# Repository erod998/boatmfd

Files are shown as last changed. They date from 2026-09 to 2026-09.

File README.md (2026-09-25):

# Boat Dashboard — Proof of Concept

A DIY Garmin-style MFD for a 7" 16:9 landscape display, restyled after the
look of Garmin's GPSMAP touchscreen chartplotters (near-black panes, round
segmented dials that fill blue, outlined data boxes, a black menu bar with a
Home button) and built for big touch targets while driving the boat.

**Moving to real hardware?** [HARDWARE.md](HARDWARE.md) has the parts list, a picked depth
transducer, and a step-by-step order to bring it up on the boat.

**Screens** (tap **Home** on the menu bar, or the small thumbnails either side
of it, to switch):

| Screen | What it shows |
| --- | --- |
| **Helm** (default) | Everything at once: GPS speed and RPM dials plus coolant / oil / battery / fuel (with estimated GPH and MPG) / trim bars on top, the chart with big Depth and Water Temp boxes in the middle, and trip, Fusion stereo and RGB lights below |
| **Nav. Chart** | Full-screen chart with Speed / Heading / Depth / Water Temp data boxes, zoom buttons, the boat, its heading line and track, an optional compass rose, and waypoint navigation |
| **Gauges** | Garmin-style engine and vessel dials: coolant, oil, battery, fuel, trim, RPM, GPS speed, fuel flow, plus fuel economy / remaining / water temp boxes |
| **Trip** | Start/stop trip logging: distance, time, average and max speed, fuel used and economy, and the saved-trip list |
| **Media** | Fusion stereo over NMEA 2000: cover art, source chips, big transport buttons, a Master volume that moves every zone together (keeping their relative mix), and a volume bar for each zone (with its own mute), plus a mute for everything, plus a gear icon for RPM Volume Boost |
| **RGB Lights** | Twelve colour presets, rainbow, power, and a segmented brightness bar |
| **Switching** | A grid of simulated digital-switching circuits (nav lights, anchor light, cabin lights, livewell, bilge pump, two accessories, horn) — no real switching module, just remembers on/off |

**Also reachable from Options** (not full screens, but full features): **Waypoints, Routes &
Boundaries** (mark/save/rename/delete waypoints, search saved waypoints by name and go straight
to one — like a GPS — build and follow multi-leg routes, circular geofence alarms), **Navigation
Alarms** (Arrival, Off Course, Anchor Drag, GPS Accuracy), and **Pinned Screens** (choose which screens
show in the Home overlay's Pinned tab and the prev/next swipe at the bottom of every screen — at
least one has to stay pinned).

**Home** is a translucent overlay like Garmin's: a clock (tap **Home** any time to check
it), a row of screen thumbnails above category tabs (Pinned, Charts, Combo, Vessel, Media,
Lights). The menu bar also has **Mark** (drop a waypoint at the boat), **Info** (data sources,
position, GPS status), **Day/Night** chart mode, **Alerts** (the alarms and
warnings below, and a missing GPS fix; the icon turns amber/red with a count)
and **Options** (units, alarms, chart orientation, map layers & colors, centre chart on
boat, waypoints, calibration). Tap the speed gauge to switch between mph and knots. The
chart defaults to **Old Hickory Lake, TN (37075)**, and has the three orientations a GPSMAP
does: **North Up** (default), **Heading Up** (the bow points to the top of the screen) and
**Course Up** (the *active leg* points to the top). Course Up is the one worth knowing about —
Heading Up re-aims the chart with every wiggle of the boat, which at idle is a constant slow
swim, while Course Up holds the leg still and lets the boat icon swing against it, so the angle
between the icon and straight-up is exactly how much you are crabbing off the track. With no Go
To or route running it falls back to course over ground, then heading, so it is never stuck
pointing somewhere stale. The chart button beside the zoom controls is labelled with the current
mode (**N↑**, **H↑**, **C↑**) and switches in one press between North Up and whichever rotating
mode you last chose; **Options → Chart orientation** cycles through all three. (It used to cycle
all three itself, and since Heading Up and Course Up look alike on a straight run, getting back
to North Up took two presses.)

**Following the boat**: the chart keeps the boat centred (North Up) or a third of the way up the
screen (Heading and Course Up) until you drag it. Then it stays where you put it, and a blue
**Center** button appears above the ruler; tap it to go back to the boat. Pinching or the +/−
buttons zoom without letting go of the boat.

**The chart cursor** — what a tap on the chart does, the way a GPSMAP does it: it drops a cursor
and does nothing else yet. The bar that appears says how far away it is and in which direction,
its position, and what is charted there (the depth band, or a bridge, dam or caution area — tap
that line for the full details); **Go To** navigates there, **Save Waypoint** keeps it. A tap used
to start a Go To immediately, and since a Go To and a route are mutually exclusive, one stray tap
in a chop cancelled an active route. Tapping an aid to navigation, mile marker, landmark or
hazard point identifies it instead, with its own Go To. Only those point features take a tap;
land, depth areas and shorelines used to as well, which between them cover the whole chart, so
every tap opened "Land" and the chart could not be tapped for anything else at all.

**Go To follows the channel** (auto guidance): a Go To is planned over the water, preferring the
Corps' recommended track down the channel, and leaves it only to reach a destination off it -- up a
creek, into a marina. The route is drawn as a dashed line and steered leg by leg: bearing, course
and cross-track error are for the current leg (so Course Up turns with the channel), distance and
time to go are along the rest of the route. With no chart or no way through the water it falls
back to a straight line and says so. Saved routes (Route To) still run straight between their
waypoints, as they do on a GPSMAP.

**Look-ahead**: in North Up the boat sits a third of the way in from the edge it is coming from,
so two thirds of the screen is the water ahead -- the bottom third heading north, the left third
heading east. It follows the course over the ground above 2 kn.

**Measure Distance** (the ruler button beside the zoom controls): the reference starts at the
boat and follows it; each tap on the chart moves the far end, and the range and bearing read out
at the top of the chart. **Set Ref** pins the reference to that point instead, to measure between
two arbitrary points; **From Boat** puts it back. (Built for a finger: an earlier version relied on
mouse hover and read 0.00 on a touchscreen.)

**Range Rings** (**Options → Map layers & colors → My Vessel**): four concentric circles around
the boat at a spacing you pick, the outermost labelled with its radius, so distance to anything
on screen can be eyeballed without measuring it. Drawn in real distance rather than screen
pixels, so they scale with zoom the way the chart does.

The boat's position and heading are eased continuously (every animation frame, not once a
second when a GPS fix arrives) — the same idea as the spring-smoothed gauges, but for a
wrapped compass angle and a lat/lon position: `setBoatTarget()`/`boatTick()` in app.js. This
drives the boat icon, the chart's own bearing in Heading Up (which turns the whole chart so
the boat's current heading points to the top of the screen, the boat icon then always
pointing straight up), and the position lock that keeps the boat horizontally centered and
about a third of the way up from the bottom of the map in Heading Up — a single cheap
`panBy` every frame, not a `setView`, so it holds through the whole rotation instead of only
correcting once a second. The chart itself is vector data held in memory (see **Charts**), so
panning and rotating never wait on anything to load and never show a blank square — the old
raster-tile black-square problem went away with the tiles.

**Map layers & colors** (**Options → Map layers & colors**, or the app/gps.py and
app/state.py simulators' more realistic noise): chart colors are Day/Dusk/Night — three real
palettes applied to the chart vectors themselves, not a filter smeared over an image, so the
boat and track keep their own colours while only the chart changes;
**Chart** layer toggles (Land & shoreline, Depths & contours, Aids to navigation, Hazards &
caution areas, Landmarks) add and remove the matching vector layers on the spot, with no
refetching — the data is already local; **My Vessel** has a Heading Line
(projects ahead of the boat by a fixed distance or by how far it'll travel in a set time at
its current speed — Distance/Time, matching a real GPSMAP's own Heading Line options) and a
Compass Rose (a fixed-size ring around the boat marked N/E/S/W — left un-rotated in CSS on
purpose, since leaflet-rotate spins the whole marker pane with the chart, the same reason the
boat icon has to counter-rotate to stay pointing up in Heading Up); **User Data** can hide the
recorded track, clear it, name and **save** the current breadcrumb trail as a permanent record
(kept in `data/tracks.json`, up to the same ~600-point/~10-minute window the live trail itself
keeps — a real chartplotter's active-track memory has the same kind of limit), and lists every
saved track — tap one to draw it on the chart in green, tap again to hide it, tap the pencil to
rename it in place, tap the arrow to drop a waypoint back at its starting point (retracing it, the
way you'd want to find your way back to the dock after an out-and-back cruise), or delete it. All
of this is a per-browser preference (localStorage) except clearing the track, and saved tracks
themselves, which live on the server (`/api/track`, `/api/tracks`).

**Data overlays** (the Speed/Heading/Depth/... boxes on the Helm and Nav. Chart screens): **hold**
any box (same gesture, and the same fill-as-you-hold feedback, as the RPM display and alarm
menus) to swap in a different field, matching a real GPSMAP's "Edit Overlays". There are **36
fields in seven groups**, and the picker shows the group headings because a flat list of that
many is not something anyone navigates while driving:

| Group | Fields |
| --- | --- |
| **Navigation** | Bearing, Course, Distance, Time To Dest, Arrival Time, VMG, Cross Track, Turn, Destination |
| **Vessel** | Speed, Heading, Course Over Ground, Position, GPS Accuracy, Satellites |
| **Depth & Water** | Depth, Water Temp |
| **Engine** | RPM, Engine Temp, Oil Pressure, Trim, Battery |
| **Fuel** | Fuel Level, Fuel Remaining, Fuel Rate, Fuel Economy, Range |
| **Trip** | Trip Distance, Trip Time, Average Speed, Max Speed, Trip Fuel Used |
| **Time** | Time of Day, Sunrise, Sunset, Moon Phase |

The Navigation group needs a Go To or a route running and reads `--` otherwise, the Trip group
needs a trip started, and everything reads `--` without a GPS fix — which is what a real unit
does rather than showing a stale or invented number. **VMG** is velocity made good: how fast the
distance to the destination is actually shrinking, which is only the same as speed when steering
straight at it. **Time To Dest** is computed from VMG rather than speed for exactly that reason
— sliding sideways past a waypoint at 20 kn is not arriving at 20 kn — and reads `--` when VMG
has gone negative, because a boat pointed away is not arriving at all. **Fuel Remaining**,
**Economy** and **Range** need the tank size (`BOAT_FUEL_CAPACITY_GAL`, default 40).
Which fields are picked, per screen, is a per-browser preference (localStorage);
the Chart screen defaults to Speed/Heading/Depth/Water Temp and the Helm screen (which already
shows speed via its own dial) to Depth/Water Temp, same as before this was made editable.
Sunrise, sunset and moon phase come from `app/celestial.py` — sunrise/sunset from the standard
astronomical "sunrise equation" using the boat's own position, moon phase from the days elapsed
since a known new moon (the same for every observer, so it only needs a date) — both accurate to
civil (not celestial-navigation) precision, no network call or API key, and (deliberately) not
tide/current predictions or moonrise/moonset times, which either wouldn't mean anything on a
freshwater lake (tide/current) or need meaningfully more work to compute well (the moon's real
position, not just its phase angle) than this dashboard's use case calls for.

**Alarms:** hold your finger on a gauge for about half a second (the gauge
fills as you hold) to open its alarm menu: coolant / engine temperature, oil
pressure, battery voltage (a low and a high alarm), fuel level, or the Depth
box. **Options → Alarms** lists them all. Each has an on/off switch and a
level you set with the big −/+ buttons or by tapping the bar; a small bell
marks every gauge that has an alarm on, and the gauge's red and amber bands
move to match the level. Coolant and engine temperature are the same reading
here (one engine-temperature gauge). Details are in "Alarms" below.

**Waypoints, Routes & Boundaries** (**Options → Waypoints, Routes & Boundaries**): mark the
boat's current position as a named, saved waypoint (separate from the single "Go To" target the
chart cursor sets); go to one, rename it in place, or delete it. Build a **route** by
checking two or more saved waypoints in the order you want to visit them — following one steers
leg to leg and auto-advances to the next point on arrival (within ~300 ft), the same way a single
Go To does, and the two are mutually exclusive (starting a route stops a Go To and vice versa).
**Boundaries** are a circular geofence around a point — pick a radius and whether the alarm fires
on entering, exiting, or both — for a no-wake zone, a marina, water you want a heads-up about
either way. Only circles, not the arbitrary polygons a real Garmin supports: a circle is a tap
and a radius, a polygon needs collecting an ordered ring of points on a touchscreen, and circles
already cover "stay near/away from this spot."

**Navigation Alarms** (**Options → Navigation Alarms**): **Arrival** (nearing the active
waypoint or route leg, on by default), **Off Course** (strayed too far from the direct line, by
cross-track error), **GPS Accuracy** (the fix's own reported HDOP has gotten too poor to trust),
and **Anchor Drag** — drop a reference point at the current position and get alarmed if the boat
drifts past a set radius from it, checked against the real (or simulated) GPS fix every second,
the same way a real chartplotter's anchor watch works. All four, plus boundary crossings, show up
in the same Alerts panel and banner as the engine/boat alarms; unlike those, they don't have an
"acknowledge" — they clear on their own once the condition does (back on course, anchor
re-settled), except a boundary crossing, which is a one-time event held in the alert list for 8
seconds so it doesn't disappear before the once-a-second Alerts badge or banner even shows it.

**Digital Switching** (the **Switching** screen): eight named on/off circuits (nav lights, anchor
light, cabin lights, livewell, bilge pump, two accessories, horn) standing in for a real NMEA
2000 digital-switching module (a CZone/Empirbus-style relay box) — there isn't one wired up, so
each circuit just remembers its own state, the same simulate-what-there's-no-hardware-for
approach as the rest of this dashboard.

**Smooth gauges:** engine and boat readings arrive five times a second (GPS,
trip, stereo and lights once a second), and every dial, bar and number glides
to each new reading on a critically damped spring instead of jumping, so
needles start and stop gently and never overshoot. How quickly a needle
follows a new reading is itself adjustable: hold either RPM gauge (Helm or
Gauges screen) to open "Engine RPM display" and pick from Very smooth to
Snappy — useful once a real, noisier tach signal replaces the simulator's.
No amount of easing can fully hide noise with a genuinely slow, drifting
component (a spring only trades lag for smoothness, it can't remove a real
random walk), so the simulated RPM and GPS heading in app/state.py and
app/gps.py were also tuned down to something closer to a real steady-cruise
signal — they were originally noisy enough that even "Very smooth" still
visibly shook.

Engine and battery readings are read-only, like real NMEA 2000 sensors. The
layout scales with screen height and was checked at 800x480, 1024x600,
1280x720, 1280x800 (the 10.1" panel below) and 1920x1080.

Runs today against built-in **simulators** (GPS, engine, stereo, LEDs) so the
whole thing is demoable with zero hardware attached. Swapping in real
hardware is a config change, not a rewrite — see "Going to real hardware".

## The reference build

| Job | Part | Connects with |
| --- | --- | --- |
| Brain | Raspberry Pi 4 or 5 | Runs the server and the browser (Chromium kiosk) |
| Screen | Orient Display 10.1" 1280x800, 900 nit, capacitive touch, **HDMI/USB version** (see "The screen") | HDMI + USB touch + 12 V |
| Engine data | Matsutec **CX5003** analog-to-NMEA 2000 converter | senders on one side, NMEA 2000 on the other |
| Stereo | Fusion MS-RA210 / MS-WB675 | NMEA 2000 |
| NMEA 2000 interface | CAN HAT for the Pi (PiCAN-M, MacArthur HAT, or an isolated MCP2515 HAT) or a USB CAN adapter | `can0`, 250 kbit/s |
| Fuel flow (optional) | NMEA 2000 fuel-flow sensor | NMEA 2000 |
| Lights | 12 V PWM RGB strips: PCA9685 board + 3 logic-level MOSFETs | I2C |
| Position | GPS receiver | USB or UART |
| Battery voltage | ADS1115 board + two resistors (or the converter's alternator volts) | I2C |

```
 senders (tach, oil, temp, trim, fuel) --> CX5003 --+
 Fusion MS-RA210 / MS-WB675 ------------------------+--- NMEA 2000 backbone (250 kbit/s, a terminator
 fuel-flow sensor (optional) -----------------------+    at each end, 12 V power tee)
                                                    |
                                     CAN HAT or USB CAN adapter
                                                    |
 GPS -------------- USB or UART ---------------+    |
 battery ------- ADS1115 ---- I2C -------------+--- Raspberry Pi --- HDMI + USB touch ---> 10.1" screen
 12 V RGB strips <-- MOSFETs <-- PCA9685 <-- I2C +
```

**ESP32** is not a fit for serving the chart UI, but it makes an excellent
*lighting node* for addressable strips:
[`esp32/boat_rgb_node/`](esp32/boat_rgb_node/boat_rgb_node.ino) is an
Arduino sketch that drives a WS2812B strip over WiFi with the same
`/api/lighting` shape this dashboard uses (solid color + rainbow).

## Run it (simulator mode, no hardware)

```bash
python -m venv venv
venv/Scripts/pip install -r requirements.txt      # Windows
# venv/bin/pip install -r requirements.txt         # macOS/Linux
venv/Scripts/python -m uvicorn app.main:app --host 0.0.0.0 --port 8090
```

Open `http://localhost:8090` (the layout scales with screen height, so it
works from 1024x600 up to 1080p). The simulated boat cruises up and down
the Old Hickory Lake channel near Hendersonville (edit `ROUTE` in
[`app/gps.py`](app/gps.py) to move it). Tap the chart to drop the cursor, press **Go To**, and
watch bearing/distance/ETA/cross-track-error update live (**Options →
Waypoint / go to…** shows them). Use **Night** on the menu bar, tap a color
swatch to light the (virtual) LED strip, and try the Media screen (a simulated
stereo, badge says DEMO). On a desktop browser the screen is sized by window
height, so resize to 1024x600 to see it as it will look on the boat.

Tests (protocol layer, including a fake stereo on a virtual CAN bus):

```bash
venv/Scripts/pip install python-can
venv/Scripts/python -m unittest discover -s tests -t . -v
```

## Charts

The chart is **vector data drawn by this app**, not pictures downloaded from a
map server — the same thing a real chartplotter does, and the reason it works
with no internet, stays sharp at any zoom, restyles for night instantly, and
can tell you what a buoy is when you tap it.

Source is **USACE Inland ENC** (`ienccloud.us`, the Corps of Engineers' inland
waterway charts — free, no key, no account). Their map service exposes every
S-57 feature class as a queryable layer, so the fetch pulls real GeoJSON:
depth areas with their actual depth ranges in metres, the shoreline, the
navigable channel, and every buoy, beacon and light with full attribution.

For the whole of Old Hickory Lake — Old Hickory Dam (river mile 216) up to Cordell Hull Dam at
Carthage (mile 313), creek arms included — that is **about 9,000 features and 8 MB, in about 107
requests, one every 3 seconds: 6–7 minutes**, once, until you choose to refresh it. (The first
version covered only the lower lake and stopped at Gallatin.) The service publishes no rate
limit and is a shared government server, so the fetcher never bursts; see
`REQUEST_DELAY_S` in `app/chart_data.py`.

### Getting the charts

Run this **on the Pi**, over WiFi at the dock:

```bash
venv/bin/python -m app.fetch_charts old-hickory --dry-run   # coverage check first
venv/bin/python -m app.fetch_charts old-hickory              # then for real
venv/bin/python -m app.fetch_charts --name my-lake --bbox -86.62,36.24,-86.44,36.36
```

Charts land in `data/charts/<area>/` as GeoJSON, two levels of detail (the
zoomed-out one is generalised server-side, which turns 2.1 MB of raw shoreline
into 207 KB without any visible difference at that zoom).

**`data/charts/` is committed**, so Old Hickory arrives with a plain `git pull`
and you only need the command above for a new area or a refresh. Everything else
under `data/` — tracks, waypoints, trips, settings — stays gitignored, since
that is per-boat state rather than project source. Charts are the exception
because the Pi cannot re-create them for itself: it is offline, and
`fetch_charts.py` needs the internet.

USACE reissues IENCs bi-monthly, so re-running this occasionally at the dock is
worth doing. It simply overwrites what's there.

### What you get on screen

Land and shoreline; creeks and marina basins as water; depth-shaded water, with the
**surveyed depths** (below) over the channel; the recommended track; bridges, the dam and lock;
marinas, docks and piers; restricted areas and no-wake notice signs; caution areas and hazards;
roads and railroads on land; and the aids to navigation on top. **Names** print the way a chart
prints them — creeks and bays in italic blue, islands and bends, towns, marinas, bridges and river
miles — upright even in Heading Up, and only as many as fit without overlapping. Detail comes in
as you zoom: the whole lake at once is the shoreline, the channel and the town names, and buoys,
mile markers, hazards and docks appear as you zoom in. Every group can be hidden under
**Options → Map layers & colors**. Tap any of them:

| Tap | It says |
| --- | --- |
| A beacon | `Spencer Creek Light (236.8)` — Starboard-Hand Lateral Mark, Red |
| A light | `Fl(2)R 5s` — built from the S-57 characteristic, group and period |
| The chart, in the surveyed channel | `Depth 18.2 ft, surveyed 2019` — then the charted area below it |
| A charted depth area | `0 ft to 9 ft` outside the channel, `9 ft or more` inside it |
| A marina | its name, and what kind of facility it is |
| A distance mark | `Mile 225`, Cumberland (CR) |

Two things were wrong in how the chart drew before this version and are worth knowing about if
you remember the old one: creeks and marina basins were filled in the **land** colour (Station
Camp Creek, Cedar Creek and every marina looked like dry ground), and in **Heading Up the chart
did not turn** — the boat, track and labels did, while the chart under them stayed north-up and
drew in the wrong place.

### Surveyed depths

The Corps' chart only knows two depths on Old Hickory: **0–9 ft** outside the navigation channel
and **9 ft or more** inside it. That is what the chart is for — the maintained 9-ft channel — and
it is why tapping the chart used to say 0–9 ft or nothing.

The Corps does survey the actual bottom. Its Nashville District runs condition surveys of the
channel and publishes every one through **eHydro** — around 9,000 soundings per mile, across the
old river bed from bank to bank. `app/fetch_depths.py` downloads them and turns them into a depth
grid (25 ft cells, keeping the shallowest sounding in each, a newer survey replacing an older
one) plus the surveyors' own printed soundings:

```bash
venv/bin/python -m app.fetch_depths old-hickory --dry-run   # list the surveys
venv/bin/python -m app.fetch_depths old-hickory              # ~18 downloads, one every 5 s
```

On screen: the channel shaded by depth (darker is shallower, as on a paper chart; the colour key
is under Map layers & colors), depth numbers once zoomed in, and the cursor reading the real
depth wherever you tap in a surveyed stretch. The result is `data/charts/old-hickory/survey_depth.json`
(680 KB, committed with the charts); the downloads are cached in `data/survey-cache/` so a re-run
fetches only new surveys.

**What it covers**: river miles **216–225** (Old Hickory Dam up past Hermitage, surveyed 2018–19)
and **297–313** (the upper lake below Cordell Hull Dam, 2016–17) — the channel, not the coves,
flats or creek arms, and not the middle of the lake between those two stretches. No public data
covers those; Quickdraw, once a transducer is fitted, fills them in from your own sounder.

**Lake level**: the surveys record bottom *elevations* (feet above NAVD88), so a depth is the lake
level minus the bottom — and Old Hickory moves between 442 and 445 ft. **Options → Map layers &
colors → Lake level** sets it (445 ft, normal summer pool, by default), the way a Garmin with
lake charts does; every screen shares the setting. Set it to the day's level, which the Corps
posts daily, and the chart agrees with the sounder.

Day / Dusk / Night are real palettes applied to the vectors, not a CSS filter
smeared over an image — so the boat and track keep their own
colours while only the chart changes.

### Coverage: what this data does and does not include

IENC charts the **commercially-navigable federal waterway system** — the
Cumberland (including Old Hickory Lake), Tennessee, Ohio, Mississippi and
similar. Those are covered properly, to real chart standard.

Lakes off that system may have **nothing at all**. Center Hill Lake was checked
three ways — the IENC vector service, the IENC S-57 cell list, and USACE's
separate eHydro hydrographic survey archive — and has zero USACE data in any of
them. That is a genuine gap in the free federal data, not a bug here.
`--dry-run` reports the feature count before downloading, so an uncovered area
is obvious in seconds.

Closing that gap means commercial data (Navionics, C-MAP and the like, which is
what apps such as Savvy Navvy license). That data is not redistributable into a
project like this one without its own licence, and the terms are not something
to assume — it would need checking with the provider directly, and would be a
separate data pipeline rather than a drop-in. The other route, once a
transducer is fitted, is recording your own depths with Quickdraw, which builds
a personal depth map of exactly the water you actually run.

### Why it is not raster tiles any more

The first version cached rendered tile images. Replacing it with vectors was
not a tuning change, it was a correction:

| | Raster tiles | Vectors (now) |
| --- | --- | --- |
| Requests for one lake | ~4,500, rate-limited | **~60, once** |
| Time | ~3.75 hours | **36 seconds** |
| On disk | 88 MB | **2.1 MB** |
| Zoom | fixed 11–15, blurry between | **any zoom, always sharp** |
| Night mode | CSS filter over the image | **a real palette** |
| Tap a feature | nothing | **full chart attributes** |
| Load with no internet | only pre-cached area | **everything fetched** |

### A chart app of its own in the chart's place (GPS Nautical Charts)

GPS Nautical Charts sells Center Hill Lake charts, but only inside their own app, not
as files the dashboard can draw. Their Raspberry Pi app (`Boating_App-aarch64.AppImage`,
a Qt/X11 program, verified by them on Debian 13) can take the chart's place on the
helm display instead. The dashboard's screens stay as they are, and the app's window
sits where the chart would be: on the Helm and Chart screens, clear of the data boxes,
an open side panel and the alarm banner, and out of sight on the other screens and
under the Home overlay.

On the Pi (the custom image):

```bash
mkdir -p ~/boating-app && cd ~/boating-app
curl -fLO https://www.gpsnauticalcharts.com/static_html/Boating_App-aarch64.AppImage
chmod +x Boating_App-aarch64.AppImage && ./Boating_App-aarch64.AppImage --appimage-extract
echo "BOAT_CHART_APP=$HOME/boating-app/squashfs-root/AppRun" >> /var/lib/boatmfd/boat.env
sudo systemctl restart boat-dashboard boatmfd-kiosk
```

(Extracted rather than run as an AppImage: the image has no FUSE, and it starts faster.)
Then, in the app's settings, set its NMEA 0183 source to **TCP, 127.0.0.1, port
10110**: the dashboard sends the boat's position, speed, course, heading, depth and
water temperature there once a second (`app/nmea_out.py`; `BOAT_NMEA_TCP_PORT` and
`BOAT_NMEA_TCP_HOST` change where).

How it fits together: the kiosk page (`static/js/chart-app.js`) reports where its
chart is on the screen (`POST /api/chart-app/rect`); `kiosk/chart-app.py`, started by
labwc's autostart when `BOAT_CHART_APP` is set, keeps the app running and moves its
window there; labwc's window rule (`/etc/boatmfd/labwc/rc.xml`) takes its title bar
off and keeps it above the dashboard. Remove the `BOAT_CHART_APP` line to go back to
the dashboard's own chart.

## Going to real hardware

**GPS** (e.g. u-blox NEO-6M/NEO-M8N on the Pi's UART or a USB adapter):

```bash
venv/Scripts/pip install pyserial pynmea2
set BOAT_GPS_PORT=COM5          # or /dev/serial0 on the Pi
set BOAT_GPS_BAUD=9600
```

With `BOAT_GPS_PORT` set, [`app/gps.py`](app/gps.py) uses `SerialGPS`
(real NMEA GGA/RMC/VTG parsing) instead of the simulator. If the port can't
be opened it shows NO FIX rather than a made-up position. Put the antenna
where it sees the sky.

**When hardware is configured, the dashboard never shows made-up numbers:**
a sensor that isn't wired, or has failed, shows `--`. Depth is `--` until you
add a depth transducer, and water temperature is `--` until you assign a
water probe.

### The screen

The listing for the [10.1" Sunlight Readable IPS, 1280x800, 900 nits, capacitive touch panel](https://orientdisplay.com/products/10-1-sunlight-readable-ips-1280x800-900-nits-with-capacitive-touch-panel/)
(`AFY1280800A1-10.1INTH-C`, about $142) is a **bare LVDS panel**: it has no
HDMI input, its touch panel needs its own controller, and its 3.3 V logic and
LED backlight expect a driver board. A Raspberry Pi can't drive it directly.
Orient sells the same panel with the driver board attached as the
[10.1" Raspberry Pi TFT with PCAP, HDMI/USB interface](https://www.orientdisplay.com/products/10-1-raspberry-pi-tft-with-pcap1280x800-900-nits-hdmi-usb-interface/)
(`AFY1280800A2-10.1INTH-C-HDMI`, about $180, listed with HDMI video, USB touch and a
12 V supply). Buy that one. Keeping the bare panel would mean sourcing an
HDMI-to-LVDS board that matches its pinout and backlight, plus a touch
controller: doable, but a project of its own.

- The panel is 16:10, not 16:9. Nothing in the layout assumes 16:9.
- Feed it fused, switched 12 V. The listing gives no current draw, so
  budget generously until you measure it.
- 900 nits is blinding at night. **Day/Night** only changes the chart colors.
  Ask Orient whether the driver board has a backlight dimming input: a
  dimmable backlight is the real fix, and the PCA9685 has spare outputs.
- USB touch works without drivers; there is nothing to calibrate.

### Engine data over NMEA 2000: the CX5003 (`BOAT_SENSORS=n2k`)

The Matsutec **CX5003** ([manual](https://www.scribd.com/document/1074807900/Matsutec-CX5003-Dual-NMEA-2000-converter-user-manual))
reads the boat's analog senders and puts them on the NMEA 2000 bus, so the Pi
needs no ADC, tach circuit or temperature probe for the engine. It sends PGN
127488 (RPM, trim), 127489 (oil pressure, temperature) and 127505 (fuel,
fresh-water and black-water levels), which the app decodes.

| Input | What the manual says | For this boat |
| --- | --- | --- |
| RPM | speed-ratio DIP switches (ratio 1-128) | a 4-cylinder, 4-stroke gasoline inboard is **ratio 2**; set the switches as the table on page 2 of the manual shows for ratio 2 |
| Fuel level | 0-190 ohm, or 240-33 ohm when the **"switch" wire is connected to ground** | US-standard sender: connect "switch" to ground |
| Trim | 0-190 ohm | measure the Alpha One sender with a multimeter first; anything above 190 ohm is cut off |
| Oil pressure | 10-184 ohm = 0-10 bar | US-standard 80 psi senders read high; set the sender's psi on `/calibrate` |
| Temperature | 301-22 ohm = 40-120 C (VDO-type sender) | the engine has no coolant sender: fit a VDO-type one (check the thread of your thermostat-housing port), or use the DS18B20 fallback below |
| Power | 9-32 V DC, under 120 mA, IP67 | fused, ignition-switched 12 V |

Things to know:

- **Reviews are mixed** (3.5 of 5 on Amazon, and the manual is thin). Forum
  posters report the *second engine channel* of the dual unit dead on some
  units; you use one engine, but test it on the bench before you install it.
- It does **not** send battery voltage or fuel rate. Battery voltage comes from an
  ADS1115 on the Pi (`BOAT_BATTERY_ADC=true`, wired as in the next section)
  or, if the converter turns out to send alternator volts, from that. Fuel rate
  comes from a fuel-flow sensor, otherwise it is estimated from RPM.
- The manual doesn't say which **instance numbers** it uses, whether the
  temperature is reported as engine or oil temperature, or what it sends for a
  sender that isn't connected. Open `/calibrate`: it lists every value the
  converter sends, with the instance numbers. The Pi treats a zero oil pressure
  or fuel rate as "nothing connected" until it has seen a real nonzero reading,
  so an unwired input shows `--` rather than 0.
- Trim and oil come through as percentages of the converter's range, so
  you calibrate both on `/calibrate` (below).
- If the CX5003 disappoints, any other NMEA 2000 engine converter works the
  same way: the app reads standard PGNs, not anything specific to this device.

On the Pi (the CAN interface is set up in "The NMEA 2000 backbone" below):

```bash
export BOAT_SENSORS=n2k
export BOAT_CAN=can0
export BOAT_N2K_ENGINE_INSTANCE=0        # RPM, trim, oil, temperature: use what /calibrate shows
export BOAT_N2K_FUEL_TANK_INSTANCE=0     # fuel level
export BOAT_BATTERY_ADC=true             # only if you fitted the ADS1115 for the battery
export BOAT_HOUSE_BATTERY=true           # the sensor board's house battery input (J1.8): a second battery
export BOAT_REDLINE_RPM=4800             # your engine's maximum WOT RPM
export BOAT_ENGINE_HP=135 BOAT_ENGINE_WOT_RPM=4600      # only used for the fuel-burn estimate
export BOAT_FUEL_CAPACITY_GAL=40                        # tank size: turns fuel % into gallons, economy and range
# export BOAT_N2K_TEMP=oil               # if the converter reports its temperature as oil temperature
```

**Calibrate** from a phone at the boat: `http://<pi-address>:8090/calibrate`.

1. Check that the converter appears under "NMEA 2000" with the instance number
   in use, and that RPM, oil and temperature look plausible.
2. **Trim:** run the drive fully down and save, then fully up and save.
3. **Oil:** type your sender's full-scale psi (80 for US-standard). Check it
   against a mechanical gauge if you can.
4. **Fuel level:** works as it arrives; save the readings when the tank is truly
   empty and truly full if it never quite reads 0 and 100.
5. **RPM:** with the engine running, type what the analog tach shows. The DIP
   switches must already be right; this only corrects small errors.
6. **Battery:** type what a multimeter shows.
7. At each fill-up, type the gallons pumped (see "Fuel" below).

Values are saved to `data/calibration.json`. A converter that stops
transmitting turns every engine value to `--` within a few seconds; the Info
panel on the dashboard says whether the bus is being heard.

### Alternative: the Pi reads the senders itself (`BOAT_SENSORS=real`)

Skip this section if you use an NMEA 2000 converter.

**Recommended: the passive-tap sensor board** ([SENSOR_BOARD.md](SENSOR_BOARD.md),
`BOAT_SENDER_WIRING=tap`). It only *listens* to the wires the analog gauges already drive, so every
analog gauge stays connected and working -- if the Pi is off, the helm is a normal helm. It reads
fuel, trim, oil, engine temperature, battery and RPM (through an optocoupler), and calibrates from the gauges
themselves: "just filled up", then one mark read off the analog fuel gauge, calibrates the whole
fuel scale. RPM comes from the Delco EST ignition's gray tach wire. The KiCad schematic, board and
ready-to-order fabrication files are in [hardware/sensor-board/](hardware/sensor-board/). The rest of this section is the older **reference** wiring (`BOAT_SENDER_WIRING=reference`,
the default), which takes each sender over and means disconnecting its analog gauge.

Everything on a boat like this is analog, so a small interface board sits between the senders and the Pi.
This was designed for a MerCruiser 3.0 (4-cylinder, distributor ignition,
Alpha One drive) with US-standard resistive senders, but every value is
configurable.

**Parts:** an ADS1115 module (4-channel 16-bit I2C ADC); 1% metal-film
resistors (one 240 ohm per resistive sender, one 47 k and one 10 k for the
battery, two 47 k for the tach); a 3.3 V zener diode; a 100 nF capacitor; a
1 A fuse; DS18B20 waterproof probes (1-2) with one 4.7 k resistor; wire.

| Signal | Wiring |
|---|---|
| Fuel sender (A0) | Pi 3.3 V, then 240 ohm, then a node wired to ADS1115 A0, then the sender, then boat ground. **Skip this** if you use a NMEA 2000 tank-level adapter, and set `BOAT_FUEL_SENDER=false` (an unwired input must never be read as a fuel level) |
| Trim sender (A1) | Same circuit into A1 |
| Oil sender (A3, optional) | Same circuit into A3, and set `BOAT_OIL_SENDER=true` |
| Battery (A2) | Fused 12 V, then 47 k to a node wired to A2; 10 k from the node to ground; 100 nF node to ground |
| Tach | The coil-negative (gray) tach wire, then two 47 k in series, then a node wired to GPIO 17; a 3.3 V zener from the node to ground (cathode on the node) |
| Temperature probes | DS18B20 red to 3.3 V, black to ground, yellow to GPIO 4; 4.7 k from GPIO 4 to 3.3 V. Several probes share the same three wires. (On a MacArthur HAT, use its 1-Wire connector instead: it is GPIO 19 with the pull-up already fitted, and GPIO 4 is the HAT's NMEA 0183 transmit line) |

Read these before wiring:

- **A resistive sender can feed only one circuit.** The dashboard reads each
  sender through its own reference resistor, so **disconnect the sender wire
  from the old analog gauge** (the gauge stops working). Paralleling the two
  circuits shifts both readings. Keep the analog gauge only if you can fit a
  second sender.
- **The tach wire carries ignition spikes.** On a MerCruiser 3.0 the tach
  signal is the coil-negative wire, which spikes to hundreds of volts. Tap it
  where it reaches the back of your existing tach, keep both 47 k resistors in
  series, and before connecting the GPIO put a multimeter on the node with the
  engine running: it should stay at or below about 3.3 V. The old tach can stay
  connected (this tap loads it negligibly). The counter uses one edge per
  spark (2 per revolution on a 4-cylinder distributor engine; `BOAT_TACH_PPR`)
  and ignores the ring-down after each spark, but that filtering is designed
  from how the ignition behaves, not tested on your engine: check idle RPM
  against your analog tach and use the calibration page to correct it.
- **Alpha One trim sender range:** published values conflict (some sources say
  33-240 ohm, others 0-80 ohm), so nothing is assumed: you measure yours on the
  calibration page. The 240 ohm reference handles anything from 0 to about
  390 ohm.
- **Share one ground** with the boat's DC negative, and keep sender and tach
  wiring away from ignition wires.

On the Pi:

```bash
sudo raspi-config nonint do_i2c 0                       # enable I2C
echo "dtoverlay=w1-gpio" | sudo tee -a /boot/firmware/config.txt   # 1-Wire on GPIO 4, then reboot
                                                                   # (MacArthur HAT: dtoverlay=w1-gpio,gpiopin=19)
sudo apt install python3-lgpio
python -m venv --system-site-packages venv && venv/bin/pip install -r requirements.txt smbus2

export BOAT_SENSORS=real
export BOAT_REDLINE_RPM=4800                            # your engine's maximum WOT RPM
export BOAT_ENGINE_HP=135 BOAT_ENGINE_WOT_RPM=4600      # only used for the fuel-burn estimate
export BOAT_FUEL_CAPACITY_GAL=40                        # tank size: turns fuel % into gallons, economy and range
```

**Calibrate** from a phone at the boat: open `http://<pi-address>:8090/calibrate`.
Live readings update every second. Capture fuel empty/full (defaults are the
US-standard 240/33 ohm), trim fully down/up, type your multimeter's battery
voltage, type your analog tach's RPM while running, assign the temperature
probes (engine / water), and record each fill-up. Values are saved to
`data/calibration.json`.

**Engine temperature:** the boat has no coolant sender, so use a DS18B20
probe strapped to the thermostat housing (thermal paste, then insulate it
from the engine bay air). It reads a little below true coolant temperature;
correct that on the calibration page against an infrared thermometer. A
second probe on the raw-water intake hose gives the water temperature.
Warning colors on the dashboard: amber above 195 F, red above 210 F.

### Fuel: a NMEA 2000 fuel sensor

Both kinds of NMEA 2000 fuel device work, and they share the same powered
backbone and CAN interface as the Fusion stereo (set `BOAT_CAN=can0`; the old
name `BOAT_FUSION_CAN` still works):

- **Fuel-flow sensor** (measures fuel going to the engine and broadcasts fuel
  rate, PGN 127489): GPH is then **measured**, and MPG is GPS speed divided by
  GPH. Install it in the fuel line with the flow arrow pointing the right way and
  a fuel filter ahead of it, and check the sensor's rated flow and line size
  against your engine (for example,
  [Navico's](https://www.svb24.com/en/navico-fuel-flow-transmitter.html) is rated
  0.6-45 GPH on 3/8" lines). A sensor in a supply line only reads net
  consumption if the engine has no fuel return line; fuel-injected engines
  with a return line need a differential kit that outputs the net rate.
- **Tank-level adapter** (converts your existing 240-33 ohm sender to NMEA 2000,
  PGN 127505; the CX5003's fuel input does the same job): fuel level comes from
  the bus and takes priority over the analog sender. The [Maretron TLA100](https://www.maretron.com/products/tla100-tank-level-adapter/)
  does this and, per Maretron, can be used alongside the analog gauge, so with
  that adapter you can keep your old fuel gauge. Set `BOAT_FUEL_SENDER=false` so
  the Pi doesn't also read the sender.
- The `/calibrate` page lists every fuel-flow and tank-level message it hears,
  with the device address and its **instance number**. If yours isn't 0, set
  `BOAT_N2K_ENGINE_INSTANCE` (flow sensor) or `BOAT_N2K_FUEL_TANK_INSTANCE`
  (tank level).
- Messages the device marks "not available", and readings older than 5 seconds,
  count as no data: GPH falls back to the estimate below and the level falls
  back to the analog sender, never to a stale number.

**Without a fuel-flow sensor**, GPH is estimated from RPM (propeller-law
horsepower times a typical fuel consumption) and shown with an "est" tag. With
either kind of GPH, enter the gallons the pump put in at each fill-up on
`/calibrate`: the count of gallons burned since the last fill-up is compared
with what the pump says and the fuel burn is rescaled to match, so it improves
every time.

### Depth: a NMEA 2000 transducer

Depth (and, if the transducer sends it, sea temperature) comes from any NMEA 2000 depth
transducer on the same backbone as the CX5003 and the Fusion stereo — no separate wiring
or converter needed once it's on the bus. [HARDWARE.md](HARDWARE.md) has a specific
transducer picked out (an Airmar DST800, thru-hull) if you're buying one.

- PGN 128267 (Water Depth) gives the raw depth below the transducer and the transducer's
  own configured offset (positive: to the waterline; negative: to the keel) — the two are
  added together for what the dashboard shows.
- PGN 130311 (Environmental Parameters) is filtered to just the "Sea Temperature" reading
  (that PGN is shared with outside air, cabin and other temperatures from other instruments,
  so the rest are ignored) and, if a transducer sends it, wins over the DS18B20 water probe,
  the same "bus beats a local sensor" rule used for engine temperature and fuel level.
- The `/calibrate` page lists what it hears, with the device address and the raw depth and
  offset the transducer itself reports. Depth messages carry no instance number, so with more
  than one transducer on the bus the freshest is used; to pick one, set
  `BOAT_N2K_DEPTH_SOURCE` to its device address.
- If the depth is off by a fixed amount (a transducer's own offset is often left at its
  factory default), type the true depth — from a lead line, a marked dock piling, or a known
  chart depth at your slip — into the Depth card; that's a *further* correction added on top
  of whatever offset the transducer itself reports, so you never need to reconfigure the
  transducer to fix it from here.
- No transducer, or one that's gone quiet for more than a few seconds, means `--`, the same
  no-made-up-data rule as everything else on real hardware.

### RGB lighting

**Recommended for plain 12 V PWM strips: a PCA9685 board and three MOSFETs
next to the Pi** (`BOAT_LED_DRIVER=pwm`, below). The PCA9685 makes steady 12-bit
PWM on its own, so the Pi's load never makes the lights flicker; it works on
any Pi, including the Pi 5; and the strips' current never touches the Pi. Keep
the MOSFETs beside the PCA9685 (I2C and gate wiring are short-range), and run
fused 12 V and the switched color wires out to the strips in tinned marine
wire sized for the strip current (a 5 m, 60 LED/m RGB strip can draw about 6 A
in total, 2 A per color). Fuse each LED circuit and put the electronics in a
sealed box.

**Response time:** the lights change within milliseconds of a tap. A small
background loop in `LightingController` applies every change straight away
(the API also applies it before it answers), keeps the rainbow moving at 30
frames a second, and only writes to the driver when the color actually changed
(it repeats an unchanged color every two seconds, to recover from an I2C glitch).
On the screen, the swatch, power state and preview strip react at the tap,
without waiting for the server, and the brightness slider sends its first change
at once and then at most one update every 60 ms while you drag.

Color presets live in [`app/lighting.py`](app/lighting.py) (`COLOR_PRESETS`);
the UI builds its swatches from `GET /api/lighting/presets`. Pick the driver
that matches your lights:

**Plain 12 V RGB strips (the common 4-wire kind)** — `BOAT_LED_DRIVER=pwm`.
A PCA9685 PWM board on the Pi's I2C bus (address 0x40) drives three
logic-level N-channel MOSFETs (for example IRLZ44N, or a 3-channel MOSFET
board rated above your strip's current). Wire the strip's shared `+12V`
wire to fused 12 V; each color wire (R, G, B) to a MOSFET drain; the sources to
ground; the gates to PCA9685 outputs 0, 1 and 2 (`BOAT_LED_PWM_CHANNELS`) with
a 100 ohm series resistor and a 10 k pulldown each. This assumes a
**common-anode** strip (the shared wire is +12 V), which is how nearly all
4-wire strips are made; if yours is common-cathode this circuit won't work.
All LEDs show one color at a time.

**Addressable WS2812B strips** — `BOAT_LED_DRIVER=ws281x` (needs `rpi_ws281x`
and root), with `BOAT_LED_COUNT` and `BOAT_LED_GPIO`.

**With the sensor board: the [LED board](LED_BOARD.md)** — `BOAT_LED_DRIVER=ledboard`.
Four 12 V RGBW zones (5 m of 5050 strip each) and four 12 V addressable outputs
(5 m of WS2815 each), every output on its own standard blade fuse, 20 A in all,
with a current monitor that keeps the whole board inside that. It connects to
the sensor board's J6 by an ordinary Cat5e/Cat6 patch cable (differential I2C;
not Ethernet), and the strips' power never goes near the Pi. See LED_BOARD.md.

### The NMEA 2000 backbone (CX5003, Fusion stereo and the Pi)

The CX5003, the Fusion stereo (MS-RA210 or MS-WB675 — same protocol either way) and the Pi all share one NMEA 2000 backbone,
and Fusion-Link control over NMEA 2000 needs a **powered** network. The stereo
does not power the bus, so:

1. Build a small backbone: a power tee fed from switched 12 V through a 3-5 A
   fuse, a terminator (120 ohm) at each end, and T-connectors with a drop cable
   to the CX5003, the stereo and the Pi (and the fuel-flow sensor, if any).
   Power the bus from exactly one place. The CX5003 has its own red/black
   power wires as well as the "Micro-C" bus connector.
2. Give the Pi a CAN interface. Any of these gives you a `can0`:
   - **The sensor board** ([SENSOR_BOARD.md](SENSOR_BOARD.md), rev 1.1 on): it has an isolated
     NMEA 2000 interface built in -- a drop cable into J5, and the network side is powered from
     the backbone and isolated from the Pi, like any NMEA 2000 device. Nothing else to buy.
   - **[PiCAN-M](https://copperhilltech.com/pican-m-nmea-0183-nmea-2000-hat-for-raspberry-pi/)**:
     a Pi HAT built for NMEA 2000, with a Micro-C connector for a
     plain drop cable and an optional 3 A supply that runs the Pi from 12 V. The
     simplest route. Feed that supply from the boat's 12 V, not from the
     NMEA 2000 bus: a Pi draws more than a bus should carry.
   - The **[MacArthur HAT](https://github.com/OpenMarine/MacArthur-HAT)** (open
     hardware, EUR 62 from OpenMarine before tax and shipping): an MCP251xFD CAN controller, so it
     appears as an ordinary `can0`, plus a 1-Wire connector with its pull-up
     fitted, a Qwiic I2C connector, two NMEA 0183 inputs and two outputs
     (a route to a depth sounder) and an optional 12 V to 5 V power module.
     Three things to know. It has **screw terminals**, not an M12 connector, so
     you cut a drop cable and follow the wiring diagrams in
     [its NMEA 2000 chapter](https://macarthur-hat-documentation.readthedocs.io/en/latest/nmea2000.html).
     Its CAN side is **not isolated**: the Pi and the NMEA 2000 network must be
     powered from the same battery, and the HAT's ground goes on first (see
     [its safety note](https://macarthur-hat-documentation.readthedocs.io/en/latest/#safety)).
     And its documentation assumes OpenPlotter, so on plain Raspberry Pi OS you
     set it up yourself (below). Its power module's clean-shutdown handshake is
     configured by OpenPlotter's settings app; a forum poster found that the bare
     `gpio-shutdown` and `gpio-poweroff` overlays cut power at once, so plan on
     a separate 5 V supply unless you install that app for it. Power the Pi from
     the module or from USB-C, never both.
   - An **isolated MCP2515 HAT** such as Waveshare's 2-CH CAN HAT: cheaper, screw
     terminals, so you cut a Micro-C drop cable and wire CAN_H, CAN_L and the
     HAT's isolated ground (**not** the bus's 12 V).
   - A **USB CAN adapter** (a candleLight-firmware one appears as `can0` with no
     overlay to edit); prefer an isolated one.

   Turn the HAT's own 120 ohm termination off unless it sits at the end of
   the backbone (the backbone terminators do that job). With the power off,
   measure between CAN-H and CAN-L on the backbone: 60 ohm means both
   terminators are present, 120 ohm means one is missing, about 40 ohm means
   there is one too many.
3. Enable the HAT in `/boot/firmware/config.txt` (`dtparam=spi=on` and the
   `dtoverlay=...` line for its CAN chip from your HAT's documentation), reboot,
   then bring the interface up at N2K's 250 kbit/s and check that the devices
   are talking before starting the app. Examples:

   | HAT | `config.txt` lines |
   | --- | --- |
   | Sensor board, J5 (SPI0 CE0, GPIO 25) | `dtparam=spi=on` and `dtoverlay=mcp251xfd,spi0-0,oscillator=40000000,interrupt=25` |
   | Waveshare 2-CH CAN HAT (`can0`) | `dtparam=spi=on` and `dtoverlay=mcp2515-can0,oscillator=16000000,interrupt=23` |
   | MacArthur HAT (SPI0 CE1, GPIO 25) | `dtparam=spi=on` and `dtoverlay=mcp251xfd,spi0-1,oscillator=20000000,interrupt=25` (the settings OpenPlotter's CAN app uses for it) |

   After a reboot, `dmesg | grep -i mcp` should show the controller, and
   `ip link` should list `can0`.

```bash
sudo apt install can-utils
sudo ip link set can0 up type can bitrate 250000 restart-ms 100
candump can0                          # power the stereo and the CX5003 on: you should see frames
pip install python-can
export BOAT_CAN=can0                  # shared by the engine converter, the Fusion stereo and the fuel sensor
export BOAT_FUSION_MAX_VOLUME=24      # volume steps your head unit uses (check the manual)
export BOAT_FUSION_ZONES=4            # zones the stereo has -- this boat's head unit is a 4-zone model
```

The Pi claims an NMEA 2000 address (default 42, `BOAT_N2K_ADDRESS`),
discovers the stereo from its status broadcasts, and the Media card shows
what's playing and controls play/pause/next/prev, source, mute, power and
volume. If the CAN interface can't be opened the Media card says "No stereo
found" instead of pretending.

**Zones:** each zone has its own volume. On the Media screen every zone is a
row with the name you gave it on the stereo (otherwise "Zone 1", "Zone 2"), a
speaker button that mutes just that zone, and its own −/+ and volume bar. On
the Helm screen, numbered chips choose which zone the one volume bar controls.
The speaker button beside the transport buttons (or the Helm volume row) mutes
everything at once, which is the stereo's own mute. The stereo has no
per-zone mute, so muting a zone sets its volume to 0 and remembers the level to
return to; if the volume is changed on the stereo itself in the meantime, that
memory is dropped. Each zone's volume bar stops at the volume limit set on the
stereo for that zone.

The zone number in the volume command counts from 0 (Zone 1 is 0, Zone 2 is 1),
although the stereo's screen counts from 1; the code converts. That follows
canboat's captures and the signalk-fusion-stereo plugin, which sends the zone
number minus one. An earlier version of this dashboard sent Zone 1 as 1, which,
going by those sources, would have been Zone 2.

**RPM Volume Boost:** the gear icon next to the power button on the Media
screen opens a panel that turns the stereo up as RPM climbs toward
`BOAT_REDLINE_RPM`, to stay ahead of engine and wind noise, and eases it back
down toward idle — the marine version of a car stereo's speed-compensated
volume. Three settings, all saved server-side (`data/volume_boost.json`, so
every screen agrees): an on/off toggle, **Boost at full RPM** (how many
percent louder than what you set the volume to, applied at redline), and
**Smoothing** (how gradually the boost follows RPM changes instead of
chasing every flicker — 0% is instant, 100% is about a 4-second ease). It
boosts every zone from whatever you last set that zone's volume to, so
turning the volume up or down by hand while boosted just moves the baseline
it boosts from. Implemented in `app/volume_boost.py`, ticked once a second
from the full-frame loop.

**Mute stereo on alarms (TelMute):** when a new NMEA-sourced alarm fires
(coolant, oil pressure, battery, fuel, depth — see "Alarms" below), the
dashboard sends the stereo's ordinary mute command for a few seconds so the
alarm is actually heard over music, then un-mutes on its own; a second alarm
before that window ends extends it instead of double-muting. This is the
same idea as wiring a phone or VHF into a stereo's dedicated TelMute input,
but Fusion has no TelMute message over NMEA 2000 — the regular mute command
(the same one behind the dashboard's own Mute button) has the same audible
effect without extra wiring. Toggle it at **Options → Mute stereo on
alarms** (on by default; the setting is saved server-side too). Implemented
in `app/telemute.py`, ticked five times a second alongside alarm evaluation.

**Album art:** Fusion stereos don't send cover art over NMEA 2000, so the
dashboard looks it up by artist/album from Apple's free iTunes Search API
(cached, on a background thread; needs internet). That sends the track's
artist and album names to Apple. Set `BOAT_ALBUM_ART=false` to turn it off;
with no art (offline, or no match) the UI draws a generated cover instead.

**Read this before trusting it:** the Fusion messages come from
[canboat's](https://github.com/canboat/canboat) reverse-engineered PGN
definitions (proprietary PGN 126720 commands, PGN 130820 status), not an
official Garmin spec. The code is verified against those definitions by unit
tests and a virtual CAN bus with a fake stereo — **it has not been tested
against a real head unit.** Expect to adjust things like the volume range
(unit-specific) and the number of zones once it's on the boat.

### Alarms

Hold a gauge (see the top of this file) to set its alarm. What you can set,
and where each starts:

| Alarm | Fires when the reading | Starts at | Warning (amber) from |
| --- | --- | --- | --- |
| Coolant / engine temp | rises to the level | 210 F, on | 15 F below |
| Oil pressure | falls to the level | 10 psi, on | 10 psi above |
| Battery voltage low | falls to the level | 11.8 V, on | 0.3 V above |
| Battery voltage high | rises to the level | 14.8 V, on | 0.3 V below |
| Fuel level | falls to the level | 10 %, on | 15 % above |
| Depth | falls to the level | 5 ft, **off** | 3 ft above |

The first five start on, at the same levels as the fixed red alerts the dashboard
had before, but they now also raise the banner and the beep described below.
Depth starts off: it needs a depth sounder, and there is none yet.

How they behave (all decided on the server, in [`app/alarms.py`](app/alarms.py),
so the Helm screen and a phone always agree):

- The reading must stay past the level for a few seconds (3 s for temperature
  and oil, 5 s for battery and fuel, 2 s for depth) before the alarm fires, so a
  starter-motor voltage dip or a sounder dropout doesn't set it off. It clears
  when the reading recovers by a small margin, so it doesn't flicker.
- **No data never alarms:** a sensor that isn't there, or a converter that has
  gone quiet, is not a reading. Oil pressure is only watched once the engine
  has been running for 5 seconds, because it takes a moment to build.
- **...and never clears one either.** An alarm already sounding stays up when
  its sensor stops reporting, with the banner saying so ("no reading from the
  sensor", and the last value it had), until real data shows recovery. A depth
  sounder loses the bottom in very shallow water, and an overheating engine can
  burn through its sender wire -- the moments an alarm must not quietly vanish,
  which it used to. Silence still silences it; switching that alarm off clears it.
- When an alarm fires, a red **banner** appears above the menu bar with the
  message and a **Silence** button, the gauge flashes red, and a double beep
  sounds once a second. Silence stops the banner and the beep for everything
  alarming at that moment; the alarm stays in the Alerts list, marked
  "silenced", until the reading recovers. A different alarm later needs its own
  Silence. Warnings are amber, silent, and appear only in the Alerts list and
  on the gauge.
- Levels, on/off and the sound switch are saved in `data/alarms.json`, so they
  survive a restart. Changing a level starts that alarm afresh against the new
  level.

**Sound** is generated in the browser (Web Audio, two alternating tones), so it comes out of
whatever device is actually showing the dashboard: the Pi's own audio (HDMI, a USB speaker, or
the 3.5 mm jack on a Pi 4 -- the Pi 5 has no jack) if it's running in kiosk mode on the boat, or
that device's own speaker if it's a phone or tablet loading the dashboard over the boat's WiFi.
Browsers only allow sound after the page has been touched once; the kiosk command below adds
`--autoplay-policy=no-user-gesture-required` so the Pi's own kiosk browser never hits this, but a
phone or tablet still needs one tap anywhere first -- a "Tap anywhere to enable alarm sound" hint
appears a couple seconds after load if it hasn't happened yet, and disappears on the first tap.
The **Test sound** button in the alarm menu plays the pattern so you can check the volume. The
banner and flashing work without any sound, on every device, regardless of the above.

### Run it on the Pi at boot

A systemd service for the server, with the settings from the sections above in
`boat.env` (one `NAME=value` per line):

```ini
# /etc/systemd/system/boat-dashboard.service
[Unit]
Description=Boat dashboard
After=network.target

[Service]
User=pi
WorkingDirectory=/home/pi/boat-dashboard
EnvironmentFile=/home/pi/boat-dashboard/boat.env
ExecStartPre=+/bin/sh -c 'ip link set can0 down; ip link set can0 up type can bitrate 250000 restart-ms 100'
ExecStart=/home/pi/boat-dashboard/venv/bin/python -m uvicorn app.main:app --host 0.0.0.0 --port 8090
Restart=always

[Install]
WantedBy=multi-user.target
```

Then `sudo systemctl enable --now boat-dashboard`. To pick up new code later,
from an SSH session on the Pi itself: `./update.sh` (pulls, then restarts the
service -- one-time `chmod +x update.sh` first, or just `bash update.sh`).

**Full screen on the Pi's own display** ([kiosk/](kiosk/)), from an SSH session on the Pi:

- `kiosk/start-kiosk.sh` opens the dashboard in Chromium's kiosk mode on the display, now
  (`--stop` closes it). It finds the desktop session itself, so it works over SSH, and first
  shows a "Starting up..." page that switches to the dashboard as soon as the server answers.
- `kiosk/install-autostart.sh`, once: the Pi logs straight in to a **kiosk session** of its own
  (`kiosk-session.sh`) -- none of the Pi desktop, only the splash and the dashboard, which reopens
  itself if it's closed or crashes. `--desktop` points the auto-login back at the normal desktop
  (with the dashboard opened over it); `--undo`, the plain desktop.
- `kiosk/quiet-boot.sh`, once, then `sudo reboot`: no rainbow square, logos or boot text -- a
  black screen that says "Starting up...", the same as the kiosk's first page, until the
  dashboard appears. Every boot file it touches is backed up first; `--undo` puts them back.
- `kiosk/slim-down.sh`, once, then `sudo reboot`: turns off what a boat dashboard doesn't use --
  cloud-init, waiting for WiFi at boot, remote desktop, automatic updates (an update cut short by
  the power switch can leave the Pi unbootable), printing, Bluetooth, NFS. Disabled, not
  uninstalled, and recorded: `--undo` turns back on exactly those. It saves boot time, not CPU:
  measured, Chromium drawing the dashboard is nearly all of the Pi's CPU.
- `kiosk/network-later.sh`, once, then `sudo reboot`: the dashboard first, the network after.
  NetworkManager takes ~16 s to start on the Pi and the display waits for it; now it starts the
  moment the display is up instead, with a timer that starts it 60 s after boot regardless, so
  WiFi and SSH always come back. `--undo`.

**Or a system of its own** ([image/](image/README.md)): an image built for the dashboard alone,
with no Raspberry Pi OS underneath -- the boot logo, then the dashboard, from a read-only system
the power switch can't damage.

## Architecture

```
app/
  main.py      FastAPI app: REST endpoints + /ws/telemetry WebSocket (engine/boat/alarms 5x a second, everything else 1x)
  alarms.py    User-set alarms: levels, delay, hysteresis, warnings, silencing, saved to data/alarms.json
  gps.py       GPS source: SimulatedGPS (default) or SerialGPS (real NMEA)
  nav.py       Great-circle bearing/distance/ETA/cross-track-error math
  lighting.py  RGB controller with its own 30 Hz loop: color presets, rainbow; MockDriver, WS281xDriver or PCA9685 PWM
  sensors.py   Sensor hub: engine data from NMEA 2000 or from senders/tach/temp probes on the Pi, fuel-burn estimate, calibration
  media.py     Stereo control: SimulatedMedia (default) or FusionMedia (real)
  fusion.py    Fusion PGN encoders + status parsers (canboat layouts), including zone volumes, limits and names
  volume_boost.py  RPM-linked stereo volume boost: boost %, smoothing, saved to data/volume_boost.json
  telemute.py  Mutes the stereo for a few seconds when a new NMEA alarm fires, saved to data/telemute.json
  artwork.py   Cached background album-art lookup (iTunes Search API)
  n2k.py       Minimal shared NMEA 2000 node: CAN IDs, fast-packet, address claim
  n2k_engine.py  Engine (127488, 127489) and tank level (127505) decoders + latest-value store
  n2k_env.py   Depth (128267) and sea-temperature (130311) decoders + latest-value store
  state.py     Settings (env vars) + the simulated engine/battery/depth/water-temp
  trips.py     Start/stop trip logging, saved to data/trips.json
  tracks.py    Saved chart tracks (name, save, list, delete), saved to data/tracks.json
  celestial.py Sunrise/sunset/moon phase from lat/lon/date: the "sunrise equation", no network call
  waypoints.py Saved waypoint list (name, save, rename, move, delete), saved to data/waypoints.json
  routes.py    Multi-leg routes: save/list/rename/delete, plus following one leg-by-leg with auto-advance on arrival
  boundaries.py  Circular geofence alarms (enter/exit/both), saved to data/boundaries.json
  nav_alarms.py  Arrival, Off Course, Anchor Drag, GPS Accuracy alarms
  switching.py  Simulated digital-switching circuits, saved to data/switching.json
  quickdraw.py Simplified Quickdraw-style depth-sample recording, saved to data/quickdraw.json
  chart_data.py   Local vector chart store: fetches S-57 features from USACE as GeoJSON; see "Charts" above
  fetch_charts.py CLI to download an area's charts over WiFi ahead of time (python -m app.fetch_charts)
static/
  index.html, css/style.css                 The screens, menu bar, Home overlay and side panels
  js/dials.js                               Garmin-style segmented dials and bars (SVG), and the spring animation that smooths every gauge
  js/app.js                                 Chart (Leaflet, drawing local USACE IENC vectors), gauges, trip/media/lights widgets, telemetry rendering
  js/alarms.js                              Hold-a-gauge alarm menus, gauge bands, banner and alarm sound
  js/chrome.js                              Menu bar, Home overlay, screen switching, Alerts / Info / Options panels, WebSocket link
  calibrate.html                         Phone-friendly sensor calibration page (/calibrate)
tests/
  test_media_protocol.py                 N2K framing, Fusion protocol and album-art tests
  test_sensors.py                        Sensor math, tach, probes, fuel burn, calibration, PWM lights
  test_n2k_fuel.py                       NMEA 2000 fuel sensor decoding, priority rules, virtual-bus test
  test_n2k_engine.py                     Engine converter decoding, staleness, unwired inputs, calibration, virtual-bus test
  test_alarms.py                         Alarm thresholds, delay, hysteresis, warnings, silencing, saved settings
  test_lighting.py                       Lights: changes reach the driver at once, rainbow animation, no needless writes
  test_n2k_env.py                        Depth/sea-temperature decoding, offsets, calibration, staleness, virtual-bus test
  test_volume_boost.py                   RPM volume boost math, smoothing, per-zone baselines, saved settings
  test_telemute.py                       Alarm-to-mute timing, extension, manual-unmute handoff, saved settings
  test_tracks.py                         Saved-track save/list/get/rename/delete, generated names, persistence
  test_celestial.py                      Sunrise/sunset and moon-phase invariants (day length, hemispheres, synodic month)
  test_waypoints.py                      Saved waypoints: create/list/rename/move/delete, auto-generated names
  test_routes.py                         Multi-leg routes: save/list/rename/delete, leg-by-leg auto-advance, arrival/finish
  test_boundaries.py                     Circular boundaries: create/list/enable/delete, enter/exit/both crossing detection
  test_switching.py                      Digital switching circuits: defaults, toggle, persistence
  test_quickdraw.py                      Quickdraw depth recording: enable/disable, distance-based dedup, clear
  test_nav_alarms.py                     Navigation alarms: arrival, off course, anchor drag, GPS accuracy
  test_chart_data.py                     Chart query building, paging, atomic writes, per-layer/detail storage, failure handling
esp32/
  boat_rgb_node/boat_rgb_node.ino        Optional WiFi RGB lighting node
```

No build step on the frontend — it's a static page served by FastAPI,
talking to the backend over REST (waypoints, lighting, media, trips) and one
WebSocket (telemetry stream: GPS fix, computed nav, engine, boat info, media
state, LED frame).

### The offline guard

The boat has no internet, so anything the UI loads from a CDN works in testing —
where the machine is online, or the browser still has it cached — and is simply
gone on the water. Leaflet itself shipped that way for a while: every test
passed, the chart drew fine, and a reload out of range would have produced no map
at all, because without `L` the first `L.map()` call throws and takes the whole
chart screen with it.

`app/offline_check.py` scans `static/` for references that need the internet —
HTML `src`/`href`, CSS `url()` and `@import`, and URLs in JS string literals
(comments are skipped, so citing a source in prose is free, and `xmlns` SVG
namespaces are not mistaken for fetches). It runs two places:

- **`tests/test_offline_check.py`** fails the suite. This is the real gate; a
  CDN reference never reaches the Pi.
- **Startup**, which prints `[offline] …` with file and line into the journal
  and carries on. That covers what the test cannot see — a file hand-edited over
  SSH, or restored from an old backup. It deliberately does not refuse to boot:
  a helm display that will not start because of a lint finding is a worse bug
  than the one being guarded against.

Browser libraries therefore live in `static/vendor/`, committed. See
`static/vendor/README.md` for versions and how to upgrade them.

## What's genuinely POC-grade (next steps for a real boat)

- Nav math is great-circle bearing/distance — fine for coastal use, not
  rhumb-line/Mercator-correct for long passages.
- The sensor layer is verified by unit tests and by running the real code
  against fake hardware (a fake ADC, GPIO edge source and 1-Wire directory).
  **It has not been run on a real Pi against real senders**, and the tach
  conditioning circuit and ring-down filter in particular should be checked
  against your analog tach before you trust the RPM.
- The CX5003 support follows its manual and canboat's PGN layouts and is tested
  against a fake converter on a virtual CAN bus, **not against a real CX5003**:
  its instance numbers, its temperature field, its trim scaling and what it
  sends for an unwired sender are all things to confirm on `/calibrate`.
- Fuel GPH is an estimate until a NMEA 2000 fuel-flow sensor is added.
- The depth and sea-temperature decoding (PGN 128267, 130311) follows canboat's PGN layouts
  and is tested against a fake transducer on a virtual CAN bus, **not against a real
  transducer**: confirm its instance number and offset sign on `/calibrate` before trusting it.
- Chart rotation (Heading Up and Course Up) uses [leaflet-rotate](https://github.com/Raruto/leaflet-rotate),
  a third-party Leaflet plugin, not a first-party part of Leaflet itself. It is vendored into
  `static/vendor/` along with Leaflet, because the boat has no internet — see "The offline guard".
  Its bearing convention and click-to-latlng math were checked by hand against its own source
  and by comparing real clicks to their expected position at several bearings; it has not been
  used on a touchscreen on a moving boat.
- The NMEA 2000 fuel decoding follows canboat's PGN layouts and is tested
  against a fake sensor on a virtual CAN bus, not a real fuel sensor. Some
  devices number their instances differently; the calibration page shows what
  the device actually sends.
- The NMEA 2000 node is minimal: no product-information PGN (126996) or
  heartbeat, and it uses manufacturer code 2046 (DIY/unassigned). Some
  chartplotters list unidentified devices oddly.
- The zone byte convention (Zone 1 is 0 on the wire) comes from canboat's
  captures and the signalk-fusion-stereo plugin, not from a real head unit on
  the bench. If Zone 1's dial moves Zone 2 on the boat, that is the first
  thing to look at.
- Alarm sound is generated per-device in the browser (see "Sound" above); depth
  alarms wait for a depth source.
- No auth on the API/WebSocket — fine on an isolated boat WiFi network,
  not fine if exposed further.

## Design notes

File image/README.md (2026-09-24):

# The boat MFD's system image

A system of its own for the Pi, instead of Raspberry Pi OS with the dashboard added
([kiosk/](../kiosk/)): power on, the boot logo ("Starting up..."), then the dashboard, and
nothing else on screen at any point. It is built with Raspberry Pi's own image builder,
[rpi-image-gen](https://github.com/raspberrypi/rpi-image-gen), on GitHub
([.github/workflows/image.yml](../.github/workflows/image.yml)) whenever the dashboard or
this folder changes.

What's in it:

- Minimal Debian 13 from Raspberry Pi's A/B configuration: **two copies of a read-only system**
  (an update goes into the other copy; one that fails to boot goes back to the one that worked),
  and a data partition for everything that changes. Cutting the power with the switch can't
  damage the system, because nothing writes to it.
- The dashboard's server (`boat-dashboard.service`) and the display (`boatmfd-kiosk.service`:
  labwc and Chromium, the same session as [kiosk/](../kiosk/)). No desktop, no login screen.
- SSH, by key only; the network (systemd-networkd, with iwd for WiFi); `boatmfd.local` on the
  local network.
- The sensor board's hardware turned on in `config.txt`: I2C, SPI and its CAN controller, and the
  LED board's I2C bus (7).

| Where | What |
|---|---|
| `/opt/boatmfd` | The dashboard (read-only) and the charts it was built with |
| `/var/lib/boatmfd` | What the boat writes: tracks, waypoints, settings, calibration |
| `/var/lib/boatmfd/boat.env` | The boat's settings ([README](../README.md): `BOAT_SENSORS=real`, `BOAT_CAN=can0`, ...), one `NAME=value` per line; then `sudo systemctl restart boat-dashboard` |
| `/home/admin` | The dashboard browser's profile (its screens and units) and SSH keys |

To see what it's doing: `journalctl -u boat-dashboard` and `journalctl -u boatmfd-kiosk`.
Nothing in the image is private. SSH keys and WiFi passwords go onto the drive after the image is
written, and it picks them up at boot (`/usr/lib/boatmfd/apply-settings`).

## The Pi 4 test build, on a USB flash drive

[config/boatmfd-pi4.yaml](config/boatmfd-pi4.yaml). The Pi 4 boots from USB when there's no SD
card in it, so the SD card's Raspberry Pi OS stays as it is: take the flash drive out and put the
card back to go back to it.

rpi-image-gen's A/B system only boots from an SD card or NVMe; `usb_boot`
([layer/boatmfd.d/usb-boot.sh](layer/boatmfd.d/usb-boot.sh)) adds USB, as long as the flash
drive is the only USB drive plugged in at boot.

From the Pi, with the flash drive plugged in (here `/dev/sda`: check with `lsblk`):

```bash
sudo ~/boatmfd/image/flash-from-pi.sh https://github.com/erod998/boatmfd/releases/download/pi4-test/boatmfd-pi4.img.zst /dev/sda
```

It asks before erasing the drive, writes the image, and copies this Pi's SSH keys (the computers
that can log in to it now) and its WiFi networks onto it. Then `sudo poweroff`, take out the SD
card, and power on. Log in with `ssh admin@boatmfd.local`, or at its address on the router.

## The boat's Pi 5

The same with `device.layer: rpi5`, booting from its SD card or NVMe, without `usb_boot`. A USB
drive then holds more charts (to come).

## Building it yourself

On a 64-bit Raspberry Pi OS or Debian arm64 machine (a Pi 5 will do):

```bash
git clone https://github.com/raspberrypi/rpi-image-gen && cd rpi-image-gen && sudo ./install_deps.sh
sudo apt install python3-pil
python3 ~/boatmfd/image/make-splash.py ~/boatmfd/kiosk/plymouth/splash.png ~/boatmfd/image/build/splash.tga
./rpi-image-gen build -S ~/boatmfd/image -c boatmfd-pi4.yaml
```

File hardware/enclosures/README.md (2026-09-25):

# Enclosures: the Pi box and the LED box

Two boxes to 3D-print in PETG. Each is a base and a screw-on lid:

- **Pi box.** Holds the Raspberry Pi 5, the M.2 SSD board over its Active Cooler, and the
  sensor board on top. It measures 100 × 100 × 55 mm, not counting the ears and lugs.
- **LED box.** Holds the LED board. It measures 185 × 101 × 38 mm.

| Pi box | LED box |
| --- | --- |
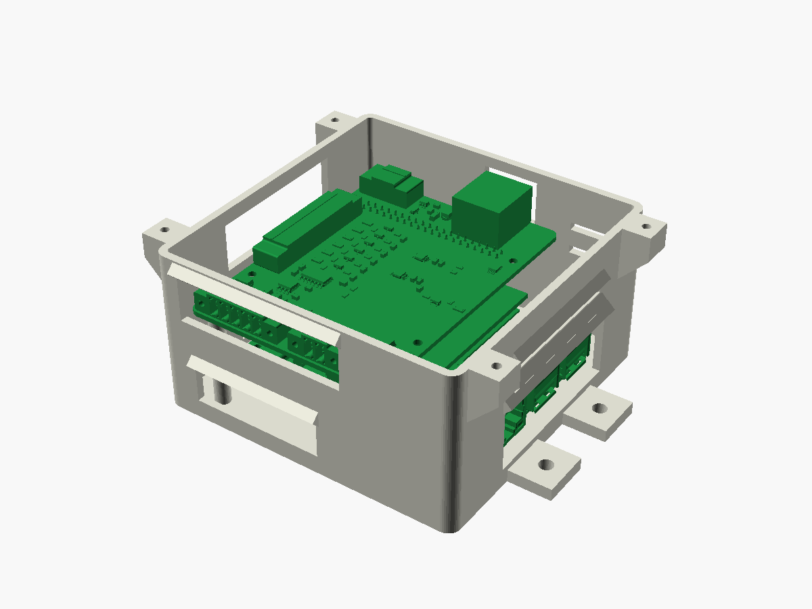
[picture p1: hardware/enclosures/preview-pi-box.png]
Pi box, USB-C/HDMI and J5/J2 side
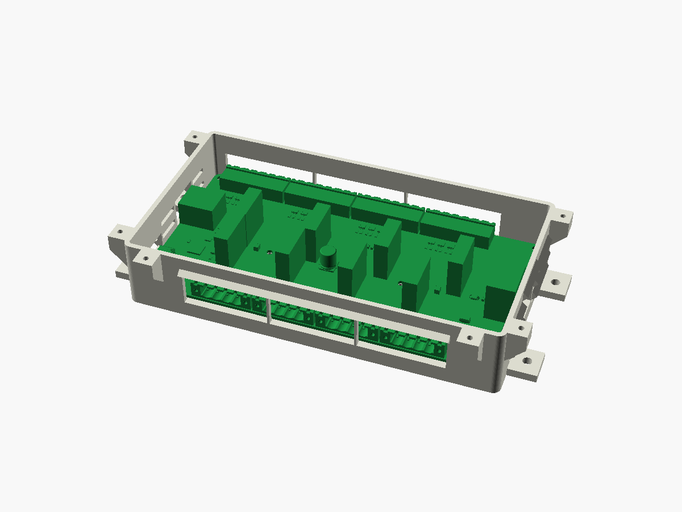
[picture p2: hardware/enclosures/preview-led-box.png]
LED box
|  |  |
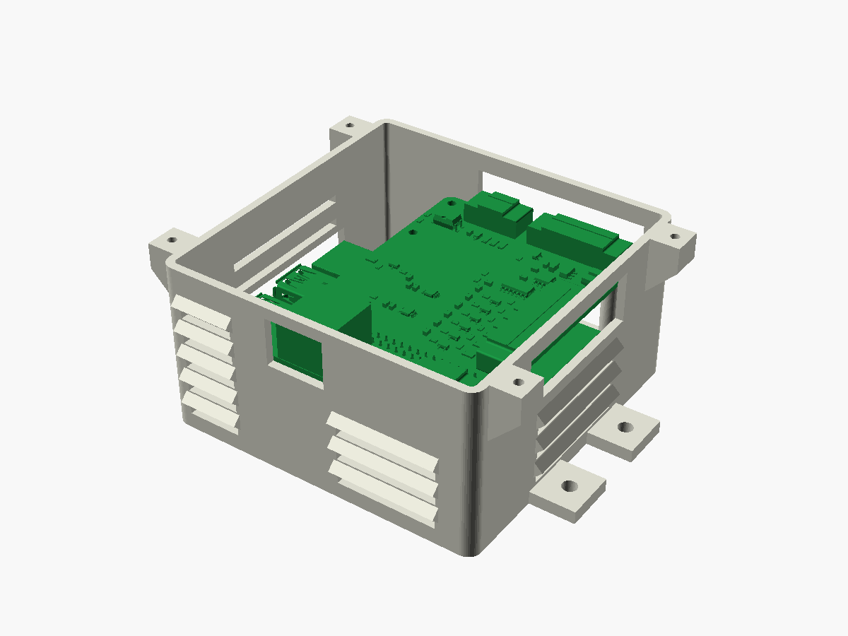
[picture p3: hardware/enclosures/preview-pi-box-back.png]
Pi box, RJ45 side
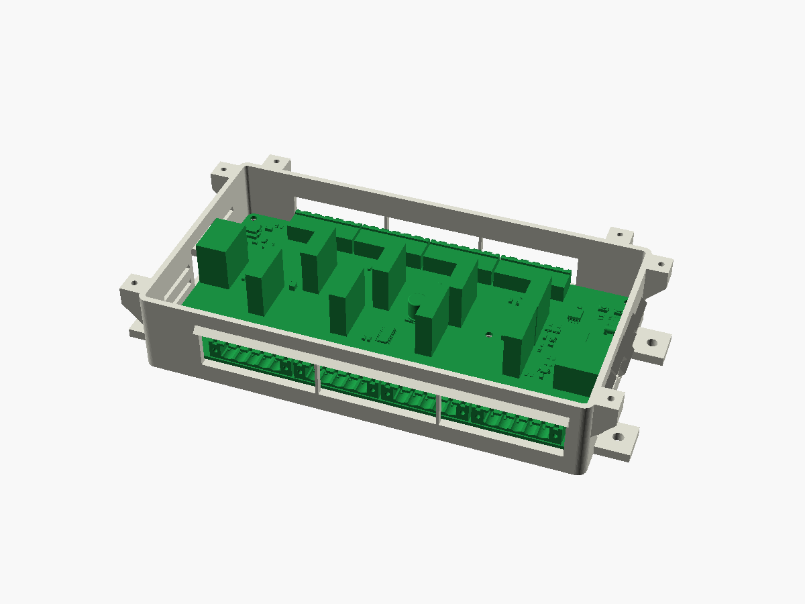
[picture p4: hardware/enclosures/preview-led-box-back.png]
LED box, zone outputs side
|  |  |

## Built for humidity, not spray

Both boxes go behind the dash. A sealed box would trap damp air, and it would condense on the
boards whenever the temperature drops. So the boxes breathe, but water can't drip in:

- The lid has no openings, and it overhangs the walls by 1.5 mm. Drips fall clear of the
  seam.
- The vents are louvres: slots in the side walls, each under a hood that slopes down and out.
  Every connector window has a hood like that above it too.
- Each floor corner has a 3 mm drain hole.
- **Conformal-coat both boards** (MG Chemicals 422B silicone or similar). The coating, not
  the box, is what keeps condensation off the parts. Mask these before you spray:
  - every connector
  - the fuse clips
  - the RJ45 and USB jacks
  - the GPIO header pins
  - the push buttons

Mount the boxes floor-down, with the walls vertical, so the hoods and the drains work.

## Files (`out/`)

| File | What it's for |
| --- | --- |
| `*-base.3mf`, `*-lid.3mf` | Bambu Studio. Already oriented to print: the bases stand on their floors, and the lids are upside down. |
| `*.stl` | The same parts as STL, for any other slicer. |
| `*-base.step`, `*-lid.step` | Fusion 360 (File → Open). Each part sits where it goes in the box, and you can edit it. |
| `*-assembly.step` | Each box with its boards in place, to check the fit in Fusion. These aren't in git because they're large. `enclosures.py` writes them. |

## Printing (Bambu, 256 mm bed, PETG)

- Layer height 0.2 mm, 5 walls (the 2.5 mm walls come out solid), 20–25 % infill.
- **No supports.**
  - The hoods, lugs and the undersides of the lugs are 45° slopes.
  - The window tops are short bridges.
  - The LED box's two long plug windows have thin ribs across them, so their tops print as
    short bridges. **Snip the ribs out with flush cutters after printing.**
- Print the bases floor-down and the lids top-down, as the 3MF files already have them.

## Hardware

**Pi box**

| Qty | Part | For |
| --- | --- | --- |
| 4 | M2.5 × 10 pan-head screw | Up through the floor posts and the Pi, into the M.2 kit's brass standoffs. They replace the kit's four lower screws. |
| 1 | M2.5 × 8 screw | Down through the sensor board's fifth hole, into the tall post under its overhang. It cuts its own thread in PETG. |
| 4 | M3 × 10 self-tapping screw | The lid into the lugs. |
| 4 | #8 or M4 screw | The ears to the boat. |

**LED box**

| Qty | Part | For |
| --- | --- | --- |
| 6 | M3 × 8 self-tapping screw | The board onto the posts. **Use nylon for the two in the middle:** they sit in the 12 V bus. |
| 6 | M3 × 10 self-tapping screw | The lid into the lugs. |
| 4 | #8 or M4 screw | The ears to the boat. |

If you'll open a lid often (the LED box, to change fuses), use M3 heat-set inserts in the lugs
instead of self-tapping screws. Set `LUG_PILOT = 4.0` in `enclosures.py` and run it again.

## Before printing the Pi box: measure the stack

Two heights aren't published anywhere: how high the M.2 board and the sensor board sit above
the Pi. `enclosures.py` estimates them:

```python
SSD_HAT_Z = 13.8   # the M.2 board's underside, above the Pi's underside
SENSOR_Z = 26.0    # the sensor board's underside, above the Pi's underside
```

Assemble the stack (Pi, Active Cooler, M.2 board on its standoffs and stacking header, and the
sensor board). Measure both heights with calipers, from the underside of the Pi's board. Put
them in `enclosures.py` and run it again, and the windows and posts follow. The box can only
be checked against the heights it's given.

The LED box has one estimate too:
- `FUSE_TOP = 22.0` is the top of an ATO fuse sitting in its holder, measured from the LED
  board's underside. The holder itself is 17.5 mm tall, per Littelfuse.
- The rim sits 4.5 mm above that height.

## Regenerating

With FreeCAD 1.0 installed, run this from this directory:

```bash
"$LOCALAPPDATA/Programs/FreeCAD 1.0/bin/freecadcmd.exe" enclosures.py
```

It does five things:
1. Exports both boards from KiCad (`kicad-cli`).
2. Builds the boxes.
3. Checks every part of every board against the walls, posts and lid.
4. Prints any clash it finds.
5. Writes `out/`.

For the Pi itself to be included in that check, put Raspberry Pi's model in `models/`:
1. Download `RaspberryPi5-step.zip` from datasheets.raspberrypi.com (MIT licence).
2. Extract `rpi-5b_no_graphics.step` into `models/`.

That model has no micro-HDMI sockets, so the Pi box has one wide opening for USB-C and both
HDMI ports. The plugs' overmoulds need that room anyway.

## What goes where

**Pi box**

| Wall | Openings |
| --- | --- |
| USB-C/HDMI side | USB-C and both micro-HDMI, reached 20 mm in under the sensor board. Above them, J5 (NMEA 2000) and J2 (tach). |
| USB side | The Pi's two USB stacks and Ethernet. |
| Power-button end | J1 (the gauge taps). It sits 6 mm in from the wall, because the M.2 board's ribbon cable loops out beside the Pi there. |
| GPIO side | J6, the RJ45 to the LED board. |

The sensor board's own J7 5 V input has no window: on the boat the Pi 5 runs from its USB-C.
Drill one if that changes.

**LED box**

| Wall | Openings |
| --- | --- |
| Zone-output side | The four zone outputs (J3–J6). |
| Pixel-output side | The four addressable outputs (J7–J10). |
| 12 V end | The 12 V input (J2), for 10 AWG. |
| RJ45 end | The RJ45 link (J1), and the USB-C for loading firmware. |

BOOTSEL, RESET and the fuses are reached with the lid off.

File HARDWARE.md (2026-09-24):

# Hardware list and Pi bring-up guide

This is the shopping list and the step-by-step for moving from the simulator to real
hardware on the boat. It assumes you've read the relevant sections of [README.md](README.md)
for the *why* and the wiring detail; this file is the *what to buy* and *what order to do
it in*. Nothing here is final until you've soldered it — treat part numbers as a strong
starting point, not gospel, and check current price/stock before ordering.

> **Engine data without a converter:** instead of the CX5003, the [passive-tap sensor board](SENSOR_BOARD.md) reads fuel, trim, oil, battery and RPM straight off the existing gauges' wires while they keep working. The KiCad design and ready-to-order fabrication files are in [hardware/sensor-board/](hardware/sensor-board/); it has not been built and proven on the boat yet.

## Parts list

| # | Part | Why | Rough price |
| - | --- | --- | --- |
| 1 | Raspberry Pi 4 or 5 (4 GB+), power supply, microSD (32 GB+) or SSD | Runs the dashboard | $60-100 |
| 2 | [Orient Display 10.1" 1280x800, HDMI/USB](https://www.orientdisplay.com/products/10-1-raspberry-pi-tft-with-pcap1280x800-900-nits-hdmi-usb-interface/) (`AFY1280800A2-10.1INTH-C-HDMI`) | The screen | ~$180 |
| 3 | Matsutec CX5003 analog-to-NMEA 2000 converter | Reads your MerCruiser's tach, trim, oil, and (once you add one) a coolant-temp sender | ~$130 |
| 4 | A NMEA 2000 interface for the Pi — **built into the [sensor board](SENSOR_BOARD.md)** (rev 1.1: isolated, J5 takes a drop cable), or a PiCAN-M / MacArthur HAT (see README's "The NMEA 2000 backbone" section) | Lets the Pi join the CAN bus | included / $60-100 |
| 5 | NMEA 2000 backbone parts: a power tee, 2 terminators (120 Ω), 3-5 A fuse, T-connectors and drop cables for the CX5003, the Fusion, the Pi's HAT and the depth transducer | Ties everything together | $60-100 |
| 6 | Depth transducer: **Airmar DST800PV-N2** (plastic, thru-hull, NMEA 2000 native) — see "Choosing a transducer" below | Makes the Depth box real | $370-410 |
| 7 | VDO-type engine temperature sender (301-22 Ω, matches the CX5003's temperature input) | Coolant temperature, since the boat has none | $15-30 |
| 8 | ADS1115 board (I2C 16-bit ADC) + a 47 kΩ / 10 kΩ resistor pair | Battery voltage (`BOAT_BATTERY_ADC=true`) | $10 |
| 9 | PCA9685 PWM board + 3 logic-level N-channel MOSFETs (e.g. IRLZ44N) + gate resistors/pulldowns -- or, with the sensor board, the [LED board](LED_BOARD.md) (4 RGBW zones + 4 addressable strips, 20 A, every output fused) | Drives the 12 V strips | $15-25 |
| 10 | GPS receiver (u-blox NEO-6M/NEO-M8N or similar, UART or USB) | Position and heading | $15-30 |
| 11 | Fuses, tinned marine wire, connectors, a project box, a 12 V-to-5 V converter for the Pi (3 A+, with output overvoltage protection; with the sensor board it plugs into the board's J7 and powers the Pi through the header) | Wiring and enclosure | $40-80 |

That's roughly **$950-1200** all-in, dominated by the transducer. If that's too much for a first
pass, skip #6 and #7 for now — everything else (engine data, lights, GPS, media) works and is
testable without them, and Depth/coolant just show `--` until you add them.

### Choosing a transducer

**[Airmar DST800PV-N2](https://www.airmar.com/Product/DST800P-2000)** (depth, speed and
water temperature in one housing, native NMEA 2000, ~$370-410): this is the recommendation.
It needs a **thru-hull install** — one hole in the hull, below the waterline, which normally
means hauling the boat out. In exchange: it's a well-proven part with a huge install base,
it's *retractable* (the sensor pulls up from inside the hull on its valve for cleaning or
replacement without hauling out again), and it gives water temperature too, which the boat
otherwise has no good source for. Prices and part-number suffixes vary a bit by retailer
(`DST800PV-N2` / `DST800P-2000` both show up for the plastic NMEA 2000 version); confirm
the listing says **NMEA 2000**, not **NMEA 0183** — Airmar sells both, and only the 2000
version talks to this dashboard directly.

**If you'd rather not haul out and drill a hole:** an *in-hull* depth transducer (a puck
epoxied to the inside of a solid fiberglass hull, reading through the glass) needs no hole,
but only works reliably on a solid (non-cored) hull, gives depth only (no speed or
temperature — you already have GPS speed, so that's a smaller loss), and typically comes as
a plain analog/pulse sender needing a separate NMEA 2000 converter box, the same pattern as
the CX5003 for engine data. This dashboard's depth code (PGN 128267) doesn't care which kind
of transducer feeds it, so either route works; this option just hasn't been priced out or
tested here the way the DST800 has.

Either way, mount it where it won't cavitate (bubbles under the boat at speed) — away from
strakes, steps and the propeller — and forward enough to read at speed, not right at the
transom.

## Setting it up: do this in order

Bring hardware up **one piece at a time**, checking the dashboard after each step, rather
than wiring everything and hoping. Every step below has something you can look at to confirm
it worked before moving to the next.

### 1. The Pi, headless, with the software already proven

1. Flash Raspberry Pi OS (64-bit, Bookworm or newer) to the SD card / SSD. Enable SSH and
   Wi-Fi in the imager's advanced options so you don't need a monitor yet.
2. Boot it, SSH in, then:
   ```bash
   sudo apt update && sudo apt install -y python3-venv git
   git clone <your fork or a copy of this repo> boat-dashboard
   cd boat-dashboard
   python3 -m venv venv
   venv/bin/pip install -r requirements.txt
   venv/bin/python -m uvicorn app.main:app --host 0.0.0.0 --port 8090
   ```
3. From your phone or laptop on the same network, open `http://<the Pi's address>:8090`.
   You should see the full dashboard running on **simulators** — a moving boat, engine
   gauges, lights you can tap. This proves the Pi, Python, and the app itself all work,
   with zero hardware attached yet. **Don't move on until this works.**
4. `Ctrl-C` it for now; it comes back permanently in the last step below.

### 2. The screen

1. Connect the display's HDMI and USB (touch) to the Pi, and its 12 V power to a bench
   supply or the boat's battery through a fuse.
2. Re-run the `uvicorn` command from step 1 and confirm the dashboard shows on the display
   itself, and that touch works (tap a screen thumbnail in the Home overlay, drag the
   brightness slider). If touch is inverted or offset, that's an OS display-rotation/touch
   calibration issue, not this app.

### 3. Engine data (the CX5003)

This is the biggest wiring job, so it gets its own careful pass. Full wiring, DIP-switch and
calibration detail is in README's ["Engine data over NMEA 2000: the CX5003"](README.md#engine-data-over-nmea-2000-the-cx5003-boat_sensorsn2k)
section — this is the short version of the order to do it in:

1. Build the NMEA 2000 backbone (item #5): power tee, a terminator at each end, T-connectors.
   Power it from switched 12 V through its own fuse.
2. Wire the CX5003 to the backbone and to your senders (tach off the coil-negative wire, the
   fuel and trim senders, and the new engine-temperature sender). Set its speed-ratio DIP
   switches for a 4-cylinder 4-stroke gasoline engine (ratio 2) and, for the fuel sender's
   "switch" wire, connect it to ground for a US-standard 240-33 Ω sender.
3. Set up the Pi's NMEA 2000 interface (item #4; for the sensor board's, see SENSOR_BOARD.md's
   "NMEA 2000" section) and bring the interface up
   (`sudo ip link set can0 up type can bitrate 250000 restart-ms 100`; `candump can0` should show frames
   once the CX5003 has power).
4. On the Pi:
   ```bash
   export BOAT_SENSORS=n2k
   export BOAT_CAN=can0
   ```
   Restart the app and open `/calibrate`. You should see "Engine data from device ..." with
   live RPM, trim, oil and temperature. If RPM reads roughly double or half the analog tach,
   fix the DIP switches rather than the calibration scale.
5. Calibrate trim (drive fully down, then fully up), oil (type your sender's full-scale psi),
   and the tach (type what the analog tach shows), all from `/calibrate`.

### 4. Battery voltage

Wire the ADS1115 (item #8) as described in README's sensor-wiring table, set
`BOAT_BATTERY_ADC=true`, and check `/calibrate` shows a sensible voltage; type what a
multimeter shows to calibrate it.

### 5. Depth transducer

1. Install the transducer (see "Choosing a transducer" above) and wire it to the same NMEA
   2000 backbone as the CX5003.
2. Restart the app (still `BOAT_SENSORS=n2k`) and check `/calibrate` — you should see
   "Depth from device ..." and, if the transducer sends it, "Sea temperature from device
   ...". The Depth box on the Helm and Chart screens should stop showing `--`.
3. If the depth reads off by a fixed amount (common — the transducer's own offset is often
   left at its factory default), type the true depth from a lead line or a marked piling
   into the Depth card's "true depth" field; that's a *correction on top of* whatever the
   transducer itself reports, so you don't need to reconfigure the transducer.

### 6. RGB lights

Wire the PCA9685 + MOSFETs (item #9) as in README's "RGB lighting" section, set
`BOAT_LED_DRIVER=pwm`, and check that tapping a color swatch actually changes the strip.

### 7. GPS

Wire the GPS receiver (item #10), set `BOAT_GPS_PORT` (and `BOAT_GPS_BAUD` if it's not
9600), and confirm the boat icon moves to your real position instead of the simulated lake
route.

### 8. Fusion stereo

Wire the RA210 onto the same NMEA 2000 backbone (README's "The NMEA 2000 backbone" section
already covers this alongside the CX5003) and confirm the Media screen finds it.

### 9. Make it permanent

Once everything above works from a manual `uvicorn` command, set up the systemd service and
Chromium kiosk autostart from README's ["Run it on the Pi at boot"](README.md#run-it-on-the-pi-at-boot)
section, with all the `export`s from the steps above moved into its `boat.env` file.

## After it's running

- Go through **every** card on `/calibrate` once more with the engine actually running and
  the boat actually on the water — numbers that looked right on the bench can still be off
  (a coolant sender reading warm at idle in your driveway, for instance).
- Set your alarm levels (hold a gauge, or **Options → Alarms**) — the defaults are
  reasonable guesses, not tuned to your engine.
- If the RPM needle looks too jumpy or too sluggish once it's reading a real, noisy tach
  signal instead of the smooth simulator, hold either RPM gauge and adjust "Needle response".

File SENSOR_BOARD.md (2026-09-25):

# Sensor board: passive taps on the existing gauges

A Raspberry Pi HAT that reads **fuel level, trim, oil pressure, engine temperature, battery
voltage and RPM** by
*listening* to the wires the boat's analog gauges already use -- and, since rev 1.1, puts the Pi on
the boat's **NMEA 2000** network (the Fusion stereo, the depth transducer) through an isolated
CAN interface, so no separate CAN HAT is needed. Since rev 1.2 it also powers the Pi, from an
external 12 V to 5 V converter wired to J7, and has a connector (J6, LIGHTS) for a separate LED
controller board -- since rev 1.3 an RJ45, for an ordinary patch cable to the
[LED board](LED_BOARD.md). Nothing is disconnected: every
analog gauge stays wired exactly as it is and keeps working, so if the Pi is off or broken the
helm is just a normal helm. It replaces buying an engine-data converter (the CX5003 route).

Built for this boat: a MerCruiser 3.0 4-cylinder with the **Delco EST ignition** (the newer
coil with two terminals, BAT +12 V in and TACH out), US-standard resistive senders, and the
stock analog gauges.

- **Design files:** [hardware/sensor-board/](hardware/sensor-board/) -- a KiCad 10 project
  (schematic, board, project footprint library) generated from one Python description.
- **Ready to order:** [hardware/sensor-board/fab/](hardware/sensor-board/fab/) -- Gerbers and
  drill files, BOM, pick-and-place, schematic and assembly PDFs, renders.
- **Software:** `BOAT_SENSORS=real` with `BOAT_SENDER_WIRING=tap`
  ([app/sender_tap.py](app/sender_tap.py) has the maths and why it works;
  [tests/test_sensor_board.py](tests/test_sensor_board.py) runs it end to end against simulated
  gauges).

> **Status: a checked design, not a proven board.** Rev 1.3 (the RJ45 link to the LED board, and
> the house battery input on J1.8) passes KiCad's electrical rules check, its design rules check
> and its schematic-to-board parity check with nothing reported at any severity, and `fab/` is
> built from it. No board has been built or connected to this boat yet, so the bring-up section
> below checks each block with a multimeter before it is trusted.

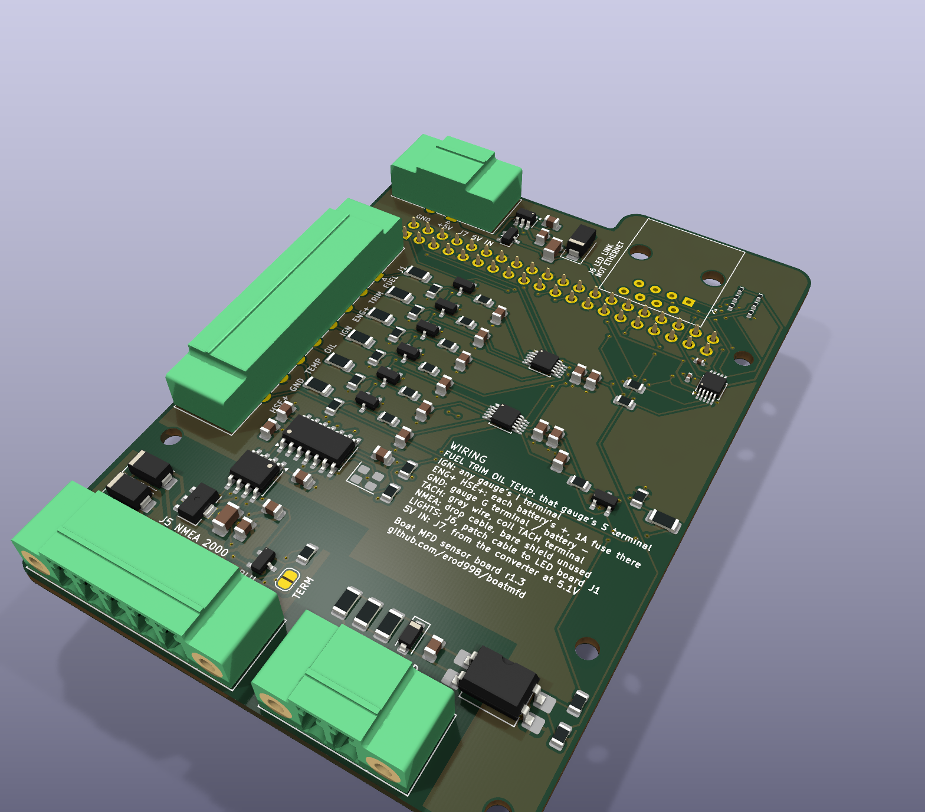
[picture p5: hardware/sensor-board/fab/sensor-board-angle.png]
The board, top side


---

## How it works

```
               BACK OF THE GAUGES (unchanged)                           SENSOR BOARD (Pi HAT)
  fuel gauge   S ── to the fuel sender ─────────── tap wire ── J1.1 FUEL ────┐
  trim gauge   S ── to the trim sender ─────────── tap wire ── J1.2 TRIM ────┤ divider, clamp, filter
  any gauge    I ── key-on +12 V ───────────────── tap wire ── J1.4 IGN ─────┤   ADS1115 U1 (0x48)
               G ── ground ────────────────────────────────── J1.7 GND      │     AIN0 fuel   AIN1 trim
  oil gauge    S ── to the oil sender ──────────── tap wire ── J1.5 OIL ─────┤     AIN2 batt   AIN3 gauge supply
  temp gauge   S ── to the temp sender ─────────── tap wire ── J1.6 TEMP ────┤   ADS1115 U2 (0x49)
  engine battery + (fused 1 A at the battery) ─────────────── J1.3 ENG+ ────┤     AIN0 oil    AIN1 temp
  house battery + (fused 1 A at the battery) ──────────────── J1.8 HSE+ ────┘     AIN2 house

  gray wire: EST coil TACH terminal ── tach gauge ─────────── J2.1 TACH ──── optocoupler ──── GPIO 13
  the tach gauge's G terminal ─────────────────────────────── J2.2 GND (the tach's own, isolated)

  NMEA 2000 drop cable (Fusion stereo, depth transducer) ───── J5 ── isolated CAN ── SPI0 + GPIO 25 (can0)

  LED board (LED_BOARD.md), patch cable ───────────────────── J6 (RJ45) ── differential I2C ── GPIO 5 / 6

  12 V -> 5 V converter (separate) ── J7 ── ideal diode ── header pins 2, 4: the Pi, and from it this board's 3V3
```

- **Taps** read the voltage on each gauge's **S** (sender) terminal, and once on the gauges' shared
  **I** (ignition supply) terminal. Each level is worked out from the sender voltage *as a share of
  the gauge supply*, so it doesn't shift when the alternator starts charging. With the key off the
  gauges are dark, and so are these readings ("--").
- The voltage on the S terminal is **not linear** in fuel level: the gauge and the sender form a
  divider. The software models that divider exactly (see app/sender_tap.py), so two calibration
  points anywhere on the scale -- "just filled up", and one mark read off the analog gauge later --
  calibrate the whole range, near-empty included. A straight line would be ~20 points out at half
  a tank.
- **Every tap resistor is on the board** (49.9 kΩ on top, 10 kΩ below, which the software
  assumes: `BOAT_TAP_R_TOP=49900`), so a tap wire is plain wire from the gauge terminal to J1.
  That makes each tap wire part of its gauge's circuit: one chafed through to ground would read
  on that gauge like a shorted sender (and on IGN, short the key-on 12 V). Route them so they
  can't chafe, and secure them. (Rev 1.0-1.1 put 10 kΩ of the top resistor at the gauge end of
  each wire instead, which made a chafed wire harmless.)
- The **tach** input goes through an **optocoupler**, so nothing on the ignition side can reach
  the Pi. It has to: the EST coil's **TACH** terminal is the coil's switched side. It sits at
  12 V, drops to ground while the coil charges, and flies up to a few hundred volts at every
  spark. That's what the analog tach counts, and the board reads the same wire.
- A tap loads the gauge by about 0.2 mA (59 kΩ from the S terminal to ground). Next to a 33–240 Ω
  sender that is well under half a percent -- the analog gauges read the same as before.

---

## Schematic, block by block

Reference designators match the KiCad schematic
([PDF](hardware/sensor-board/fab/sensor-board-schematic.pdf)). `3V3` and `GND` are the Pi's.

### Tap inputs (×7: fuel, trim, engine battery, gauge supply, oil, engine temperature, house battery)

```
                                             on the board
  gauge terminal ── tap wire ── J1.x ──[ R1 49.9k 1% 1206 ]──┬──[ R13 1k ]──┬── ADS1115 AINx
                                                             │              │
                                                    [ R7 10k 1% ]      [ C1 100n ]
                                                             │              │
                                                            GND            GND
                                     D1 BAT54S: clamps the node (R1/R7) between GND and 3V3
```

- **R1/R7** divide 0–16 V down to 0–2.7 V (`V_adc = V_tap × 10/59.9`).
- **D1 (BAT54S)** clamps the divider node between GND and 3V3 so a transient can never push the
  ADC input past its limits; the 49.9 kΩ in front of it keeps the clamp current to about 2 mA even
  at 100 V.
- **R13/C1** are a noise filter right at the ADC pin (and keep the clamp's forward voltage away from it).
- No TVS diode on these inputs: the 49.9 kΩ already limits any transient to a couple of
  milliamps, and a TVS's leakage current, flowing through it, would show up as a reading error.
- The top resistors are 1206 for their voltage rating; everything else is 0805.
- Channels, top to bottom on the board: fuel (R1, R7, R13, C1, D1), trim (…2), engine battery
  (…3), gauge supply (…4), oil (…5), engine temperature (…6). The house battery's (R35, R36, R37,
  C24, D13) came in rev 1.3, after the other parts were numbered; with no room left in that
  column, its lane runs right to left beside U2.

### Battery voltages (J1.3 engine, U1 AIN2; J1.8 house, U2 AIN2)

The boat has two batteries on a common negative, their positives kept apart: the engine's and
the house's (lights and stereo). Each input is the same as a tap input, except the top resistor
is **47 kΩ 1% 1206** (R3 engine, R35 house), giving `V_adc = V_batt × 10/57`. The software
default `BOAT_BATT_R_TOP=47000`, `BOAT_BATT_R_BOTTOM=10000` matches both. Wire each straight from
its battery's + terminal through a **1 A fuse at the battery**, not from a switched feed, so both
read with every switch off; the divider draws about 0.2 mA, some 2 Ah a year. One GND (J1.7)
serves both, since they share the negative. (J1.8 was a second GND until rev 1.3.)

### Tach: the EST coil's TACH terminal, gray wire (optocoupler)

```
  gray wire (TACH) ───── J2.1 ──[ R19 3.3k ]──[ R20 3.3k ]──[ R21 3.3k ]──┬─────────┬─────────┬── U3 pin 1 (LED anode)
                                   1206          1206          1206        │         │         │
                                                                     [ C11 10n ] [ D7 ]        │  D7: 1N4148W, cathode
                                                                           │     1N4148W       │  toward pin 1
  tach gauge G ───────── J2.2 ─────────────────────────────────────────────┴─────────┴─────────┴── U3 pin 2 (LED cathode)
                          (printed GND, but its own net, TACH_GND -- not the board's GND)

                                              3V3
                                               │
                                          [ R22 10k ]
                                               │
  U3 pin 4 (collector) ────────────────────────┴───[ R23 1k ]─── GPIO 13 (header pin 33)
  U3 pin 3 (emitter) ── GND
```

- Three 1206 resistors in series share an ignition spike (≈130 V each at a 400 V spike, inside a
  1206's rating) and set about 1 mA through the LED at 12 V -- plenty for a PC817 rank B/C.
- **C11** filters the ring-down after each spark; **D7** stops the ring-down's negative swing from
  reverse-biasing the LED.
- **R23** protects the GPIO if it is ever set as an output by mistake.
- The Pi sees one clean rising edge per ignition cycle, which is what the tach code counts: two per
  revolution on the 4-cylinder (`BOAT_TACH_PPR=2`, the default). Set **`BOAT_TACH_PULL=none`**:
  R22 is the pull-up.
- The board draws about 1 mA from the gray wire, next to the analog tach, which stays connected.

### NMEA 2000: isolated CAN interface

```
                    THE NETWORK'S SIDE (its own 0 V: N2K_GND)          │  THE PI'S SIDE
  J5.2 NET-S ──[ D9 SS14 ]──┬── N2K_12V ──[ U6 L78L05 ]── N2K_5V ──┐   │
                            ├─[ D10 SMAJ18A ]─ N2K_GND             │   │
                            └─[ C16 1µ 50V ]── N2K_GND   C17, C18 ─┤   │
  J5.3 NET-C ── N2K_GND                                            │   │
  J5.4 NET-H ──┬── D11 NUP2105L ── N2K_GND              U5 ISO1044 ┴ VCC2 │ VCC1 ── 3V3
  J5.5 NET-L ──┤   R26 120 + JP1 (open)                    CANH/CANL  │  TXD/RXD ── U4 MCP2518FD ── SPI0: GPIO 8-11
  J5.1 shield: not connected                                          │             INT ────── GPIO 25
                                                                      │             OSC1 ───── Y1 40 MHz
```

- **U4 (MCP2518FD)** is a CAN FD controller on the Pi's SPI0, the same chip family as the
  MacArthur HAT and most current CAN HATs; Raspberry Pi OS's own `mcp251xfd` driver makes it
  `can0`. R27 keeps it deselected while the Pi boots, R28 pulls its interrupt line up.
- **U5 (ISO1044)** is an isolated CAN transceiver: its Pi side runs from 3V3 and the Pi's ground,
  its network side from the NMEA 2000 network's own NET-S and NET-C. The two never share a ground,
  so the stereo's power wiring and the Pi's can't form a ground loop through the CAN wires, which
  is what the NMEA 2000 standard expects of a device with its own power supply.
- **D9** stops a reversed NET-S from doing anything; **D10** clamps surges on it; **U6** makes 5 V
  for U5's network side. The board draws well under 50 mA from the network: **1 LEN**.
- **D11** protects NET-H and NET-L from ESD and surges.
- **JP1 is open, and stays open on the boat.** Bridging it puts R26 (120 Ω) across NET-H/NET-L,
  for a bench test with just the Pi and the stereo and no backbone. A device on a real network
  must not terminate it -- the backbone's two terminators do that.
- The network side is its own island on the board: every N2K net is at least **2 mm** from all
  other copper (a rule KiCad's DRC checks, in `sensor-board.kicad_dru`), with its own ground pour,
  kept 4 mm clear of the Pi mounting hole beside it so a metal standoff can't bridge the two.

### No temperature probes

Every temperature comes from the boat's own senders: the engine's through its temperature gauge
(J1 TEMP, above), the water's from the depth transducer on NMEA 2000, if it reports one. Rev 1.0
and 1.1 had a 1-Wire input (J3) for DS18B20 probes clamped to the engine; rev 1.2 has none.

### Converters and header

```
  ADS1115 U1                              ADS1115 U2
    VDD ── 3V3, C7 100n + C8 1µ to GND      VDD ── 3V3, C9 100n + C10 1µ to GND
    SCL ── GPIO 3 (pin 5)                   SCL ── GPIO 3 (pin 5)
    SDA ── GPIO 2 (pin 3)                   SDA ── GPIO 2 (pin 3)
    ADDR ── GND   -> address 0x48           ADDR ── 3V3   -> address 0x49
    AIN0 fuel  AIN1 trim                    AIN0 oil  AIN1 temp  AIN2-3 not connected
    AIN2 battery  AIN3 gauge supply
    ALERT/RDY: not connected                ALERT/RDY: not connected
```

No I²C pull-ups on the board: the Pi already has them on GPIO 2/3, and a second board stacked on
the header would double them up.

### 5 V in (J7): the Pi's power

```
  J7.1 +5V ──┬──────────── Q1 IRLML0030 (S -> D) ──────────────┬──── header pins 2, 4 (the Pi's 5 V)
             │                     │ G                         ├── C21 22µ
         [ C20 100n ]         U7 LM74700 ideal diode:           └── D12 SMAJ5.0A (to GND)
             │                ANODE/EN to J7.1, CATHODE to the Pi side,
  J7.2 GND ──┴── GND          GATE to Q1, VCAP: C19 100n to ANODE
```

- The converter's output (set it to **5.1-5.2 V**, rated 3 A or more) runs the Pi through the
  header's 5 V pins, as the Raspberry Pi HAT guide allows (5 V ±5 %, up to 2.5 A). This board's
  3V3 comes from the Pi, as before; the NMEA 2000 side still runs from the network's own 12 V.
- **U7 + Q1 are an ideal diode**: about 20 mV forward drop, where a Schottky would lose 0.4 V the
  Pi can't spare (it warns of undervoltage below 4.63 V). **J7 wired backwards** is blocked --
  nothing conducts, and U7 is rated to -65 V. With the Pi's **USB-C plugged in as well**, that
  supply can't push current back into the converter. (The Pi 4 has no diode of its own on
  USB-C, though, so the converter would feed the USB supply: don't plug both in on the boat.)
- **D12** clamps spikes on the rail. None of this saves the Pi from a converter that fails with
  12 V on its output, so pick one with output overvoltage protection.
- J7 and these parts sit on a **tab above the header's left half** (see Ordering): the Pi's 5 V
  pins are at that corner, and the tab keeps the 5 V run to them short.

**On the boat: the Pi 5 and its SSD run from the Pi's own USB-C, not J7.** A Pi 5 with an NVMe
SSD (the M.2 board under this one, see below) can draw more than the 2.5 A J7 and the header are
built for. So the boat's Pi 5 takes its power the usual way, through its USB-C, from a 12 V -> 5 V
converter good for **5 A**, and the Pi feeds the SSD board and this board through the header, as
Raspberry Pi's own M.2 HAT+ is fed. **J7 stays unconnected** (still fitted, for a Pi on its own).
The ideal diode keeps the Pi's 5 V from reaching J7's terminals. J7 remains the way to power a
Pi 4, or a Pi 5 without an SSD.

**Stacked on an M.2 SSD board.** The boat's Pi 5 boots from an NVMe SSD on a PCIe-to-M.2 board
(Waveshare PCIe TO M.2 HAT+, 2230/2242 drives). That board sits on the Pi, over its Active Cooler,
with a stacking header passing the 40 pins up, and this board plugs onto that header. Nothing
clashes. The only part on this board's underside is its header socket, apart from the
connectors' solder joints: check those clear the SSD. The M.2 board's own ID EEPROM is the only one, since this
board has none. Its INA219 power monitor sits at I²C address 0x40, while this board's ADCs are at
0x48 and 0x49. Use standoffs tall enough for the two levels.

### Lights connector (J6): the link to the LED board

The LED controllers are deliberately **not** on this board: 20 A of switched strip current would
sit next to the millivolt-level gauge taps, and a shorted strip shouldn't be able to take the
engine data down with it. They're on the [LED board](LED_BOARD.md), and J6 is its link: an
**RJ45** for an ordinary straight-through Cat5e/Cat6 patch cable (rev 1.3; rev 1.2 had an 8-way
JST GH carrying logic-level signals, which a long cable run through a boat would not have liked).

```
  J6.1 / J6.2  ── pair: the LED board's I2C clock  ┐ differential I2C (U8, a PCA9615): GPIO 5/6,
  J6.3 / J6.6  ── pair: the LED board's I2C data   ┘ the LED board's own bus (R24/R25 pull it up)
  J6.4 / J6.5, J6.7 / J6.8 ── the other two pairs: reserved, not connected
```

- **One I2C bus, everything on it.** The LED board's PCA9685 (0x40, its four RGBW zones), its
  current monitor (INA226, 0x45) and the RP2040 that runs its four addressable outputs (0x30) all
  sit on the bus from GPIO 5/6. It's a bus of its own, so a fault out there can't stall the
  converters' bus and with it the engine data; and a kernel-driven one (i2c-gpio), which honours
  clock stretching -- the RP2040 stretches, and the Pi's hardware I2C gets that wrong.
- **Differential I2C**: U8 (NXP PCA9615) turns the bus into two differential pairs at 5 V, and the
  LED board's PCA9615 turns it back. Each pair is terminated at both ends, 620 Ω up, 120 Ω across,
  620 Ω down (R29-R34 here), so the cable is matched and an idle bus reads as idle. Good for many
  metres of cable at the 100 kHz the bus runs at.
- **No ground and no power in the cable.** The strips' current returns on the LED board's own
  heavy ground wire to the supply's ground point, and can't come back through the Pi. The PCA9615
  is built for exactly this: it tolerates a few volts between the two boards' grounds.
- **NOT Ethernet.** Never plug either end into a network switch, router or PoE injector: the
  pairs carry 5 V logic, and a PoE injector would put 48 V on them. Both boards say so beside
  their RJ45s.
- **GPIO 18, 19 and 21 are free since rev 1.3**: rev 1.2 passed them to the LED board for
  addressable data, but the Pi can only drive two such strips (and none on a Pi 5), so the LED
  board's RP2040 makes that data itself now.

Software: `dtoverlay=i2c-gpio,bus=7,i2c_gpio_sda=5,i2c_gpio_scl=6` in `/boot/firmware/config.txt`,
then `BOAT_LED_DRIVER=ledboard` and `BOAT_LED_I2C_BUS=7` (LED_BOARD.md, "Software").

---

## Pi header pins used

| Pin | Signal | Use |
|---|---|---|
| 2, 4 | 5V | **in**: the Pi's power, from J7 through the ideal diode |
| 1, 17 | 3V3 | converters, pull-ups, U8's input side (a few mA in total) |
| 3 | GPIO 2 / SDA | both ADS1115 |
| 5 | GPIO 3 / SCL | both ADS1115 |
| 6, 9, 14, 20, 25, 30, 34, 39 | GND | |
| 33 | GPIO 13 | tach |
| 19, 21, 23, 24 | GPIO 10, 9, 11, 8 (SPI0 MOSI, MISO, SCLK, CE0) | NMEA 2000 CAN controller |
| 22 | GPIO 25 | CAN controller interrupt |
| 29, 31 | GPIO 5, 6 | SDA, SCL of the LED board's own I2C bus (i2c-gpio), out on J6 through U8 |

Everything else is left free -- GPIO 18, 19 and 21 too, since rev 1.3 -- GPIO 4 (used for NMEA 0183 by some marine HATs) included. The
header is a stacking socket, so another HAT can go on top; check its pin list against this one
first -- in particular, a CAN HAT on SPI0 CE0 would clash with the one built in here.

## Connectors

J1, J2, J5 and J7 are Phoenix Contact **MC 1,5 / 3.81 mm pluggable terminal blocks with
screw-locking flanges**: the plug screws to the header, so it can't walk out on a boat. Each
connector's plug overhangs the board edge. J6, the LED board's link, is an **RJ45** for a
straight-through patch cable (Amphenol 54602-908LF, on the tab beside J7's, facing up).

Since rev 1.2 every pin is labelled on the board itself, beside the pin, with the name in the
**Printed** column; the **WIRING** block in the middle of the board sums up the table below.

| Connector | Pin | Printed | Goes to |
|---|---|---|---|
| **J1** helm (8, left edge) | 1 | FUEL | fuel gauge **S** terminal |
| | 2 | TRIM | trim gauge **S** terminal |
| | 3 | ENG+ | the engine battery's **+** terminal, through a **1 A fuse at the battery** |
| | 4 | IGN | the **I** terminal on the back of any one gauge. That's the key-switched +12 V that lights the gauges; they all share it, so any gauge will do. The board measures the senders as a share of it, and uses it to tell that the key is on |
| | 5 | OIL | oil gauge **S** terminal |
| | 6 | TEMP | engine temperature gauge **S** terminal |
| | 7 | GND | the **G** terminal of the same gauge as IGN: the taps measure against the gauges' own ground |
| | 8 | HSE+ | the house battery's **+** terminal, through a **1 A fuse at the battery** (rev 1.3; was a second GND) |
| **J2** tach (2, bottom edge) | 1 | TACH | the **gray wire** from the EST coil's **TACH** terminal -- easiest where it lands on the tach gauge's signal terminal at the helm. No resistor on this one |
| | 2 | GND | the tach gauge's **G** terminal -- twist these two wires together |
| **J5** NMEA 2000 (5, bottom edge) | 1 | BARE | the drop cable's bare drain wire (shield) -- **not connected** here (the backbone grounds its shield at the power tee) |
| | 2 | RED | NET-S: the network's +12 V |
| | 3 | BLK | NET-C: the network's 0 V |
| | 4 | WHT | NET-H: CAN high |
| | 5 | BLU | NET-L: CAN low |
| **J6** lights (RJ45, on the tab, facing up) | 1-8 | "J6 LIGHTS: LED board J1 / patch cable, NOT ETHERNET" | the LED board's J1, by a straight-through Cat5e/Cat6 patch cable (see "Lights connector" above) |
| **J7** 5V IN (2, on the tab, plug faces up) | 1 | +5V | the 12 V -> 5 V converter's **+5 V** output |
| | 2 | GND | the converter's **0 V** output |
| **J4** | | | the Pi's 40-pin header, underneath |

---

## Parts list

The full list, with manufacturer part numbers, is
[fab/sensor-board-bom.csv](hardware/sensor-board/fab/sensor-board-bom.csv). In short:

| Ref | Qty | Part | Notes |
|---|---|---|---|
| U1, U2 | 2 | **ADS1115IDGSR** (TI, TSSOP-10) | 0x48 and 0x49 |
| U3 | 1 | **PC817**, rank B or C, SMD gull-wing | tach optocoupler |
| R1, R2, R4–R6 | 5 | 49.9 kΩ 1% **1206** | tap top resistors |
| R3, R35 | 2 | 47 kΩ 1% **1206** | engine and house battery top resistors |
| R7–R12, R36, R22 | 8 | 10 kΩ 1% 0805 | divider bottoms; tach pull-up |
| R13–R18, R37, R23 | 8 | 1 kΩ 0805 | ADC pin series resistors; GPIO protection |
| R19–R21 | 3 | 3.3 kΩ **1206** | tach input, in series |
| R24, R25 | 2 | 4.7 kΩ 0805 | the LED board bus's pull-ups |
| U8 | 1 | **PCA9615DP** (NXP, TSSOP-10) | differential I2C for the LED link |
| R29-R34, C22, C23 | 6 + 2 | 620 / 120 / 620 Ω ×2, 100 nF, all 0402 | the link's pair terminations; U8's decoupling |
| C1–C7, C9, C24 | 9 | 100 nF X7R 0805 | ADC pin filters; decoupling |
| C8, C10 | 2 | 1 µF X7R 0805 | decoupling |
| C11 | 1 | 10 nF X7R 0805 | tach ring-down filter |
| D1–D6, D13 | 7 | BAT54S (SOT-23) | clamps |
| D7 | 1 | 1N4148W (SOD-123) | across the opto LED |
| U4 | 1 | **MCP2518FD** (Microchip, SOIC-14) | CAN controller |
| U5 | 1 | **ISO1044BD** (TI, SOIC-8) | isolated CAN transceiver |
| U6 | 1 | L78L05 (SOT-89) | 5 V for the network side |
| Y1 | 1 | 40 MHz 3.3 V oscillator, 3.2 × 2.5 mm | CAN controller clock |
| D9 / D10 / D11 | 1 each | SS14 / SMAJ18A (SMA) / NUP2105L (SOT-23) | reverse polarity / surge / CAN ESD |
| R26, JP1 | 1 | 120 Ω 0805 + solder jumper (open) | bench-only terminator |
| C12-C18 | 7 | 100 nF / 1 µF 0805, one 1 µF **50 V 1206** (C16) | decoupling |
| J1 / J2 / J5 | 1 each | Phoenix MC 1,5/ 8-, 2-, 5-GF-3,81 | plus the matching **MC 1,5/ n-STF-3,81** plugs |
| J6 | 1 | Amphenol **54602-908LF** (RJ45, through-hole) | the LED link; any straight-through patch cable |
| J7 | 1 | Phoenix MC 1,5/ 2-GF-3,81 (as J2) | 5 V in, plus its **MC 1,5/ 2-STF-3,81** plug |
| U7 / Q1 | 1 each | **LM74700-Q1** (TI, SOT-23-6) / **IRLML0030** (Infineon, SOT-23) | ideal diode |
| C19, C20 / C21 | 2 / 1 | 100 nF 0805 / 22 µF 25 V X5R **1206** | charge pump, input / 5 V bulk |
| D12 | 1 | SMAJ5.0A (SMA) | 5 V rail clamp |
| J4 | 1 | 2×20 female **stacking** header, extra-tall (e.g. Adafruit 1979) | |
| — | 5 | M2.5 standoffs and screws | four HAT holes on the Pi, one (H5) supporting the part past the Pi's edge |
| — | 1 | NMEA 2000 drop cable with a female Micro-C end | cut the other end into J5's plug |
| — | 2 | inline fuse holder + 1 A fuse | the J1.3 and J1.8 battery leads, one at each battery |
| — | 1 | **12 V -> 5 V converter**, 3 A or more, adjustable or fixed at 5.1-5.2 V, **with output overvoltage protection**, potted or sealed | J7; fed from the dashboard switch through its own fuse |
| — | | 20–22 AWG tinned marine wire, ring terminals | taps; tach pair twisted |

---

## Ordering the board

For **PCBWay**, everything is ready in [hardware/sensor-board/fab/pcbway/](hardware/sensor-board/fab/pcbway/): the Gerbers, a BOM and centroid in PCBWay's assembly format, and [ORDER.md](hardware/sensor-board/fab/pcbway/ORDER.md) with every option to pick on their quote forms. The notes below are the general version.

The board is a 2-layer, 1.6 mm Pi HAT, **65 × 88 mm overall**: the standard HAT outline and
mounting holes, 20 mm longer on the side away from the header to make room for the NMEA 2000
interface, and a **35 × 12 mm tab above the left half of the header** for the 5 V input.
- The 20 mm reach past the Pi 4's USB-C / micro-HDMI edge and sit about 5 mm above those plugs
  (on the Pi's usual 11 mm standoffs) -- fine for straight plugs; check first if you use a
  right-angle HDMI adapter there. H5, in the extra corner, takes a standoff to the enclosure.
- The tab reaches 12 mm past the Pi's GPIO edge, at the SD-card end, and J7's plug and wires
  come out of its top edge: leave room for them there in the enclosure.
0.2 mm tracks and spacing, 0.3 mm vias, all within any online fab's standard service.

- **Bare board:** upload `fab/sensor-board-gerbers.zip`. Any colour and finish (HASL lead-free
  is fine; ENIG makes the fine-pitch ADS1115 easier to solder by hand).
- **Assembled (surface-mount parts):** also upload `fab/sensor-board-bom.csv` and
  `fab/sensor-board-cpl.csv` (JLCPCB's column names). Check every part's orientation in the fab's
  placement preview before paying -- fabs' rotation conventions differ from KiCad's for some
  packages, typically SOT-23, TSSOP and the opto's SMD-4. The connectors and the stacking header
  are through-hole: solder those yourself.
- `fab/sensor-board-assembly.pdf` is the placement drawing (references and pin-1 marks);
  `fab/sensor-board-layers.pdf` shows each copper layer.

## Layout

- **Two layers**, a GND pour on both with a stitching via beside every surface-mount ground pad
  -- **except under the NMEA 2000 network's side** (its own pour, 2 mm away; see above) and
  **around the tach input**: J2, R19–R21, C11, D7 and U3's pins 1–2 are on their own
  nets (TACH_*) with **at least 3 mm clearance** to everything else and no pour near them. That
  side sees the ignition; no board ground goes anywhere near it. Inside it, the three series
  resistors' nets keep 0.6 mm from each other. Both rules are in `sensor-board.kicad_dru`, so
  KiCad's design rules check enforces them.
- The six input channels run in lanes from J1 on the left to the converters in the middle,
  each with its filter right at the ADC pin; the tach sits in the bottom-right corner, away
  from them.
- **Silkscreen** (rev 1.2): every connector pin is labelled with what it connects to, printed
  on the wire side of the connector, and a WIRING block in the middle of the board sums up the
  rules. J5's labels are the drop cable's wire colours.
- **The 5 V input** is on the tab: J7's +5V pin sits right above the header's 5 V pins, and the
  converter's current runs J7 -> Q1 -> header pins 2/4 on 0.8 mm tracks, the last stretch on the
  bottom layer (on top it walled the header's GND pin 6 off from the pour). The ideal diode's
  sense pins, caps and D12 join on thin tracks. No via sits in a surface-mount pad anywhere on
  the board, so none can wick solder away from a joint.
- **J6** (rev 1.3) is an RJ45 on a tab of its own beside J7's, reaching 17.6 mm past the Pi's
  GPIO edge: 13 mm tall and through-hole, it couldn't go anywhere over the Pi. Its pair
  terminations stand in two chains beside its pins 1-3; U8 sits below the mounting hole, on the
  way to GPIO 5/6. Nothing runs on top under the plug's end of it.
- **The header's GND pins keep their thermal spokes:** no other net's track passes within half a
  pin pitch of one, on either layer, so none is ever walled off from the ground pours.
- **Conformal coat** everything except the connectors and the header after the board passes bring-up.

## Changing the design

Everything in `hardware/sensor-board/` is generated. Edit the Python, not the KiCad files:

| File | What it is |
|---|---|
| `design.py` | every part, its value, footprint, part number, and what each pin connects to -- the one source of truth |
| `schematic.py` | draws the schematic from design.py |
| `board.py` | places the parts, routes the board (with `router.py`), pours ground, writes the design rules |
| `footprints.py` | the project footprint library: KiCad's own resistor, capacitor and SOT-23 footprints with their outline moved off the silkscreen (the board is too dense for it) |
| `build.py` | runs all of the above, then KiCad's ERC, DRC and parity checks, then writes `fab/` |

Rebuild with KiCad's bundled Python (KiCad 10). `build.py` stops before writing `fab/` if any
check reports anything.

```powershell
& "C:\Users\erod9\AppData\Local\Programs\KiCad\10.0\bin\python.exe" hardware\sensor-board\build.py
```

---

## Wiring at the gauges

1. Key off. At the back of each gauge, the terminals are marked **I** (ignition +12 V), **G**
   (ground) and **S** (sender, sometimes SND). Don't remove anything: put a ring terminal for the tap
   *on top of* the existing one on the stud, and snug the nut back down.
2. Run a tap wire from each: fuel S to J1 FUEL, trim S to TRIM, oil S to OIL, the temperature
   gauge's S to TEMP, and one gauge's **I** terminal to **IGN** (J1.4). Plain wire -- the
   resistors are on the board.
3. Run a ground from that same gauge's **G** terminal to J1.7 (GND).
4. **Tach:** the EST coil has two terminals, **BAT** (+12 V in) and **TACH**. The **gray** wire
   runs from TACH to the tach gauge's signal terminal (marked TACH, SIG or S). Put a ring terminal
   on top of the gray wire's at the back of the tach gauge, to **J2 TACH**, and a second from the
   tach gauge's **G** terminal to **J2 GND**. Twist the two together. The tach gauge stays
   connected.
5. **Power:** the dashboard switch's 12 V output feeds the 12 V -> 5 V **USB-C** converter
   (5 A, through its own fuse), plugged into the **Pi 5's USB-C**. That powers the Pi, the SSD
   board and this board. Leave J7 unconnected. (A Pi without an SSD can take a 3 A converter on
   J7 instead, with the USB-C left unplugged.)
6. **Batteries:** a wire from each battery's **+** terminal, through a 1 A inline fuse right at
   the battery: the engine battery to **J1.3 ENG+**, the house battery to **J1.8 HSE+**. Not from
   a switched feed: these read with everything off.
7. **NMEA 2000:** a drop cable from a T on the backbone to J5 (colours in the Connectors table).
   The backbone needs its power tee and two terminators, as always; see README's "The NMEA 2000
   backbone".
7. Keep the tap and tach wires away from ignition leads, and zip-tie them against chafe.

## Bring-up, one block at a time

Do these in order, and don't connect the gauges until the board has passed the bench steps.

1. **5 V in, before the Pi goes on.** Board on its own, a bench supply at 5.1 V into J7:
   header pins 2 and 4 read about 5.08 V to GND. Swap the supply's leads: they read 0 V, and the
   supply sees no load (the ideal diode blocks). Then set the real converter to 5.1-5.2 V the same
   way before connecting it.
2. **Converters.** Board on the Pi (powered from its USB-C, or from J7), nothing plugged into J1
   or J2. Enable I²C
   (`sudo raspi-config nonint do_i2c 0`, reboot), then `i2cdetect -y 1` must show **48** and **49**.
3. **One tap, on the bench.** A 12 V supply into J1.4 and its negative to J1.7. The calibration
   page (`http://<pi>:8090/calibrate`, with the software settings below) should show **about
   12.0 V at the gauges**. Repeat for each tap input by moving the wire, and for the battery input
   (J1.3).
4. **Tach, on the bench.** A 12 V supply switched on and off into J2 (+ to pin 1): `pinctrl get 13`
   should follow it -- low while 12 V is applied, high when it is off. Then on the engine: compare
   the page's RPM with the analog tach at idle and at cruise, and use the page's tach calibration
   to correct it.
5. **Gauges.** Wire the taps (above). Key ON, engine off: the page shows the gauge supply and
   "gauges on", and each tap shows a voltage between 0 and the supply.
6. **NMEA 2000.** With the overlay below set and the Pi rebooted, `dmesg | grep -i mcp251xfd`
   shows the controller and `ip link` lists `can0`. Connect J5 to the backbone, power the network,
   then `sudo ip link set can0 up type can bitrate 250000 restart-ms 100` and `candump can0`: with
   the stereo on you see its frames. The dashboard's Media card finds the stereo by itself. (For a
   bench test with no backbone, bridge JP1 and power NET-S/NET-C from a 12 V supply -- then
   un-bridge it before the board goes on the boat.)
7. **The ratiometric check** (tells you what kind of gauges you have): once fuel is calibrated,
   note the fuel % with the key on, then start the engine. It should stay put. If it moves by more
   than a percent or two, your gauges regulate their own supply: switch the page to **Plain volts**
   and capture the points again.

## Software settings

In `boat.env` (see the README's service section), or exported before starting the app:

```bash
BOAT_SENSORS=real
BOAT_SENDER_WIRING=tap          # listen to the gauges instead of driving the senders
BOAT_TACH_GPIO=13               # the board's tach output (header pin 33)
BOAT_TACH_PULL=none             # the board has its own pull-up (R22)
BOAT_OIL_SENDER=true            # the oil tap on U2
BOAT_TEMP_SENDER=true           # the engine temperature tap on U2 (J1.6)
BOAT_HOUSE_BATTERY=true         # the house battery on U2 (J1.8); the engine battery (J1.3) is always read
BOAT_CAN=can0                   # the NMEA 2000 interface on J5 (Fusion stereo, depth)
# BOAT_TACH_PPR=2               # the default: 2 pulses per revolution on a 4-cylinder
# BOAT_FUEL_SENDER=false        # only if fuel level comes from NMEA 2000 instead
```

And once on the Pi:

```bash
sudo raspi-config nonint do_i2c 0
echo "dtparam=spi=on" | sudo tee -a /boot/firmware/config.txt
echo "dtoverlay=mcp251xfd,spi0-0,oscillator=40000000,interrupt=25" | sudo tee -a /boot/firmware/config.txt
sudo apt install can-utils && venv/bin/pip install python-can
sudo apt install python3-lgpio && venv/bin/pip install smbus2
```

Once the LED board is on J6, its I2C bus too (and `BOAT_LED_DRIVER=ledboard`, `BOAT_LED_I2C_BUS=7`
in `boat.env`; LED_BOARD.md):

```bash
echo "dtoverlay=i2c-gpio,bus=7,i2c_gpio_sda=5,i2c_gpio_scl=6" | sudo tee -a /boot/firmware/config.txt
```

The fuel sender is assumed to be the US standard (240 Ω empty, 33 Ω full). For anything else,
set `"empty_ohm"` and `"full_ohm"` under `"fuel"` in `data/calibration.json` before capturing points.

## Calibrating on the boat

All on `http://<pi>:8090/calibrate`, from a phone or the iPad, **key ON**:

| What | When | How |
|---|---|---|
| Oil 0 psi | any time, engine **off** | "Key on, engine off: save 0 psi" |
| Trim | at the dock | drive fully DOWN → save; fully UP → save; optionally the analog gauge's middle mark |
| Fuel, first point | **right after filling up** | "Just filled up: save FULL" |
| Fuel, second point | any later day | when the analog gauge sits on a mark, tap ¾, ½ or ¼ |
| Oil, running | engine running | type what the analog gauge reads, at idle and at cruise |
| Engine temp, cold | key on after the engine has sat a few hours | type the air or lake temperature |
| Engine temp, warm | warmed up | type what the analog gauge reads (an infrared thermometer on the thermostat housing is better) |
| RPM | engine running steady | type what the analog tach reads |

Fuel shows "--" until it has two points at least 25% apart; after that the whole scale is live,
empty included, and more points refine it (the page says how well they agree). Engine temperature
works the same way, with two points at least 40 F apart: the software knows the shape of a
temperature sender's curve (app/sender_tap.py), so the cold and warm points also set the overheat
end, which straight lines through them would read 15-45 F low. With the key off the gauges are
dark, and the engine temperature shows "--", like fuel, trim and oil. A capture is
refused while the reading is still settling (fuel is smoothed against slosh), and a new point at
the same level replaces the old one.

---

`can0` has to be up before the dashboard starts: the `ExecStartPre` line in README's systemd
unit does that. Add it to the Pi's unit **once this board is fitted** -- without a `can0` to bring
up, that line fails and takes the whole service down with it, which is why it is left out today.

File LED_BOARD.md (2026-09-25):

# LED board: four RGBW zones, four addressable strips, 20 A

The boat's lighting controller. It sits in its own box near the strips and the 12 V supply, and
takes its orders from the Pi over an ordinary patch cable to the [sensor board](SENSOR_BOARD.md)'s J6.

- **Four RGBW zones** (J3-J6): 12 V common-anode strips, 5050 RGBW, 5 m each -- a MOSFET per colour.
- **Four addressable outputs** (J7-J10): 12 V pixel strips (WS2815 and the like), 5 m each. An
  RP2040 on the board runs them, so each can show its own colour or effect.
- **Every output fused**, each on its own standard blade fuse (ATO/ATC) in a holder on the board.
- **20 A in all**, from one 12 V feed, measured by the board itself: the software holds the whole
  board inside it.
- **The link**: an RJ45 for a straight-through Cat5e/Cat6 patch cable to the sensor board's J6,
  carrying the board's I2C bus as differential I2C. **Not Ethernet** -- never plug it into a switch.

**Design files:** [hardware/led-board/](hardware/led-board/) -- a KiCad 10 project generated from
Python, like the sensor board's; the RP2040's firmware in
[hardware/led-board/firmware/](hardware/led-board/firmware/).
**Software:** `BOAT_LED_DRIVER=ledboard` ([app/lighting.py](app/lighting.py), `LedBoardDriver`;
tested in [tests/test_led_board.py](tests/test_led_board.py)).

> **Status: a checked design, not a proven board.** KiCad's electrical rules check, design rules
> check and schematic-parity check all come back clean, with nothing reported at any severity, and
> the fabrication files are in [hardware/led-board/fab/](hardware/led-board/fab/) -- ordering notes in
> [fab/pcbway/ORDER.md](hardware/led-board/fab/pcbway/ORDER.md) (2 oz copper). The firmware compiles;
> the driver is tested against a simulated board. Nothing has been built yet.

---

## What it has to carry

At 12 V, at full white:

| Output | Strip | Current |
|---|---|---|
| a zone | 5 m of 5050 RGBW, 60 LEDs/m | about 8 A (2 A per colour wire; all of it in the shared +12V wire) |
| an addressable output | 5 m of WS2815, 60 pixels/m | about 7.5 A (25 mA a pixel) |
| **everything** | four of each | **about 60 A** |

The board is built for **20 A**: that's what its input, its copper and the feed to it are sized
for, and it's plenty to light a boat -- a third of full white across all eight strips, or any
four at full brightness. Past 20 A everything dims together (see "The 20 A budget"). Each output
alone can take a whole 5 m strip at full white.

## How it works

```
  12 V feed (10 AWG, 25 A fuse at the supply) ── J2 ── D1 clamp ── R47 1 mΩ shunt ── the 12 V bus
                                                                      │ U4 INA226 reads it
      the 12 V bus ── F1..F4 ── J3..J6 zone +12V ── strip ── colour wires ── Q1..Q16 to ground
                  └── F5..F8 ── J7..J10 +12V ────── strip ── its own GND pin back to the board

  sensor board J6 ══ patch cable ══ J1 ── U1 PCA9615 ── the board's 5 V I2C bus:
                                            ├── U5 PCA9685 (0x40): 16 PWM outputs ── the 16 MOSFETs' gates
                                            ├── U4 INA226 (0x45): the board's current and voltage
                                            └── Q17/Q18 level shift ── U2 RP2040 (0x30) ── U7..U10 ── J7..J10 data
```

### The link (J1)

The same as the sensor board's end (SENSOR_BOARD.md, "Lights connector"): the I2C bus as
differential I2C on two of the cable's pairs -- 1/2 clock, 3/6 data -- with each pair terminated
at both ends, 620 Ω / 120 Ω / 620 Ω; the other two pairs reserved. **No ground and no power go
down the cable**: the strips' current can only return on the board's own ground wire, and the
PCA9615s tolerate a few volts between the two boards' grounds. Any ordinary straight-through
patch cable works (T568A or T568B at both ends). **Never plug either end into a network switch,
router or PoE injector.**

### Zones (J3-J6)

**Common-anode** 12 V RGBW strips -- the shared wire is +12 V, each colour wire is switched to
ground -- which is nearly every 5-wire strip. Each colour is a BUK9M7R2-40E (40 V, 7 mΩ at a 5 V
gate) driven by the PCA9685 through 100 Ω, with 47 kΩ holding it off while the board powers up.
The PCA9685 runs at 5 V so the gates see 5 V.

Zone *z*'s colour *c* is PCA9685 output **4(z-1) + (R 0, G 1, B 2, W 3)**:

| Zone | Connector | R | G | B | W |
|---|---|---|---|---|---|
| 1 | J3 (top edge, left) | 0 | 1 | 2 | 3 |
| 2 | J4 | 4 | 5 | 6 | 7 |
| 3 | J5 | 8 | 9 | 10 | 11 |
| 4 | J6 (top edge, right) | 12 | 13 | 14 | 15 |

Zone 1's R, G, B are outputs 0, 1, 2 -- the plain `BOAT_LED_DRIVER=pwm` driver's defaults -- so
zone 1 also works with that driver alone.

### Addressable outputs (J7-J10)

**12 V pixel strips**: WS2815 (recommended: its backup data line means one dead pixel doesn't
blank the rest), or 12 V WS2811. The RP2040 makes the four data streams itself (PIO and DMA), so
each output can run its own colour or effect and the link only carries a few bytes when something
changes. U7-U10 buffer the data to 5 V; 330 Ω and a clamp protect each data pin.

Each connector is 4-way: **+12V, DATA, BI, GND**. BI is a WS2815's backup data input, which wants
ground at the strip's start -- it's grounded here. A 3-wire strip (WS2811) leaves BI empty.

5 V strips (WS2812B) aren't supported: 5 m of them would need 18 A at 5 V.

### The 20 A budget

Two layers:

1. **Before anything is sent**, the software works out what the scene will draw -- each zone
   colour's share of `BOAT_LED_ZONE_AMPS` by its PWM duty, each pixel strip by its length,
   brightness and colour at `BOAT_LED_PIXEL_MA` a pixel -- and if that's over `BOAT_LED_MAX_AMPS`
   (20), dims everything by the same factor. Zones through the PCA9685's duty; the pixel strips
   through the RP2040's limit register.
2. **The INA226 measures what really flows** (five times a second, through the 1 mΩ shunt with
   Kelvin sense). If it's still over -- longer strips than configured, say -- it dims further in
   steps until it isn't, and comes back up slowly once there's room.

The fuses are the backstop, and they protect the wires, not the budget.

### Supplies

The logic runs from the 12 V bus through D2 (reverse polarity) and a small buck converter, U6
(AP63205, fixed 5 V: a linear regulator would burn a watt from 14.8 V), then U11 (AP2112, 3.3 V)
for the RP2040. D1 (SMCJ18A) clamps surges on the input; wired backwards, it conducts and blows
the feed's fuse.

---

## Fuses and wiring

Every output has its own **standard blade fuse (ATO/ATC)** in a Littelfuse 178.6165.0002 holder
on the board (rated 30 A). **Size each fuse for the wire it protects**, not for the strip:

| Output | Wire | Fuse |
|---|---|---|
| zone, 5 m RGBW at full white (8 A) | 16 AWG (1.5 mm²) for all five wires | 10 A |
| addressable, 5 m WS2815 (7.5 A) | 16 AWG for +12V and GND; data can be thinner | 10 A |
| a shorter strip, on 18 AWG | 18 AWG | 7.5 A |

The **12 V feed** to J2 is **10 AWG (6 mm²)** from its own **25 A** fuse or breaker at the
supply (J2 is a 24 A screw terminal for 10 AWG), and its ground goes back on 10 AWG to the same
ground point as the Pi's supply. Tinned marine wire throughout; the electronics in a sealed box.

Over 5 m at 12 V, a strip is dimmer at its far end; for long runs, feed +12V and GND to both ends
(from the same fused output).

## Connectors

The outputs are Phoenix Contact **MSTB 2,5 / 5.08 mm pluggable terminal blocks with screw-locking
flanges** (12 A per pin, up to 2.5 mm² wire): the plug screws to the header, so it can't walk out.
Every pin is labelled on the board.

| Connector | Pins | Plug |
|---|---|---|
| **J1** link | RJ45: pairs 1/2, 3/6 | a straight-through Cat5e/Cat6 patch cable to the sensor board's J6 |
| **J2** 12V IN | +12V, GND | screw terminal (METZ CONNECT RT10N02HGLU), 10 AWG |
| **J3-J6** zones 1-4 | +12V, R, G, B, W | MSTB 2,5/ 5-STF-5,08 (1778014) |
| **J7-J10** addressable 1-4 | +12V, DATA, BI, GND | MSTB 2,5/ 4-STF-5,08 (1778001) |
| **J11** USB-C | | firmware loading only |

## The board

178 × 94 mm, two layers, **2 oz copper** (order it that way: the 20 A paths need it).

- The four zone connectors along the top edge, each with its MOSFETs right behind its colour pins;
  the four addressable outputs along the bottom edge; the 12 V input on the right edge, then its
  clamp, shunt and current monitor.
- A 12 V bus across the middle -- a top-layer pour -- with the eight fuses standing in two rows
  along it, the zones' above and the addressable outputs' below, each in line with its output's
  +12V pin.
- The strips' current on 3-4 mm tracks and pours on the top layer only (no vias in its path);
  ground poured on both layers, with a via beside every surface-mount ground pad.
- The PCA9685 in the middle above the bus; the RP2040, the link and the USB-C in the left-hand
  column. The RP2040's supply pins escape inward to vias under the chip, so every signal pin has
  its way out.
- Six M3 holes: the four corners, and two in the middle of the bus with the copper kept 3.4 mm
  away (use nylon screws or plain standoffs there all the same).

## Firmware

The RP2040's firmware is [hardware/led-board/firmware/](hardware/led-board/firmware/) (C, Raspberry
Pi's Pico SDK 2.x). GitHub builds it on every change
([.github/workflows/led-firmware.yml](.github/workflows/led-firmware.yml)): the run's artifact is
`led_board.uf2`. To build it yourself:

```bash
export PICO_SDK_PATH=/path/to/pico-sdk
cmake -S hardware/led-board/firmware -B build && cmake --build build   # build/led_board.uf2
```

**Loading it**: with the board on its 12 V, plug a computer into J11 (USB-C), hold **SW1
(BOOTSEL)**, press and release **SW2 (RESET)**, let go of BOOTSEL: the board appears as a drive
called RPI-RP2. Copy `led_board.uf2` onto it. The yellow LED (D8) blinks once a second while the
firmware runs. (A blank board appears as the drive on its own, without the buttons.)

It's an I2C target at **0x30**. Registers (writes and reads run on through consecutive registers;
a write takes effect at the end of the transfer):

| Register | What |
|---|---|
| 0x00-0x01 | `L` `B` (read-only: identifies the board) |
| 0x02-0x03 | firmware version, major / minor |
| 0x04 | status: bit 0 running |
| 0x05 | frame counter |
| 0x08 | limit, 0-255: scales every output's current, linearly (the budget) |
| 0x10 + 0x10·n | output n (0-3 = J7-J10): +0 mode (0 off, 1 solid, 2 rainbow), +1..+3 R G B, +4 brightness (colour × brightness is gamma-corrected, 2.2, like the zones' PWM, from firmware 1.1), +5 rainbow speed (turns a minute), +6 byte order (0 GRB, 1 RGB, 2 BRG, 3 RBG, 4 GBR, 5 BGR), +7 flags (bit 0 reverse), +8..+9 pixel count (up to 600) |
| 0x7E | write 0xB0: restart as the USB drive, to load new firmware |
| 0x7F | write 0x5A: restart |

Everything starts off; the Pi repeats its settings every two seconds, so the board recovers from a
restart on its own.

## Software

On the Pi (with the sensor board):

```bash
echo "dtoverlay=i2c-gpio,bus=7,i2c_gpio_sda=5,i2c_gpio_scl=6" | sudo tee -a /boot/firmware/config.txt
```

and in `boat.env`:

```bash
BOAT_LED_DRIVER=ledboard
BOAT_LED_I2C_BUS=7
BOAT_LED_PIXELS=300,300,300,300   # pixels on J7, J8, J9, J10 (0 for none)
BOAT_LED_ORDER=GRB                # the pixel strips' byte order (WS2815: GRB)
BOAT_LED_MAX_AMPS=20              # the whole board's budget
BOAT_LED_ZONE_AMPS=8              # one zone's strip at full white
BOAT_LED_PIXEL_MA=25              # one pixel at full white
BOAT_LED_WHITE=true               # zones light whites with their W LEDs
```

The dashboard's lighting controls then drive everything: every zone shows the chosen colour (its
white part on the W LEDs), every addressable strip the same colour, or the rainbow, which the
RP2040 runs itself. The API's lighting state carries the board's measured amps and volts, and how
far the budget has dimmed it (`board`).

## Changing the design

As the sensor board: everything in `hardware/led-board/` is generated; edit the Python.

| File | What it is |
|---|---|
| `design.py` | every part and what each pin connects to: the single source of truth |
| `schematic.py` | draws `led-board.kicad_sch` from it |
| `board.py` | places and routes `led-board.kicad_pcb`; `python board.py --dry-run` does it without KiCad and draws `reports/led-board-dry-run.png` |
| `padgeom.py` | footprint pad geometry from KiCad's library files, for the dry run (checked against pcbnew under KiCad) |
| `router.py` | the grid router |
| `footprints.py` | builds `led-board.pretty`, the small parts with their silkscreen moved to the fab layer |
| `build.py` | all of the above under KiCad, then ERC, DRC with schematic parity, and the fabrication files in `fab/` |
| `kicadpaths.py` | where KiCad is: the Windows install by default, `KICAD_DIR` elsewhere |

```
& "C:\Users\erod9\AppData\Local\Programs\KiCad\10.0\bin\python.exe" build.py
```

## Bring-up

1. Before fitting any fuse, power J2 from a current-limited bench supply at 12 V: the green LED
   (D7) lights; 5 V and 3.3 V are right at C13 and C34; under 100 mA drawn.
2. Load the firmware (above); the yellow LED blinks.
3. Connect the patch cable to the sensor board. On the Pi, `i2cdetect -y 7` shows 0x30, 0x40,
   0x45 (and 0x70, the PCA9685's all-call).
4. One output at a time: fit its fuse, connect its strip, and try it from the dashboard. Watch
   the measured current in the API's lighting state.

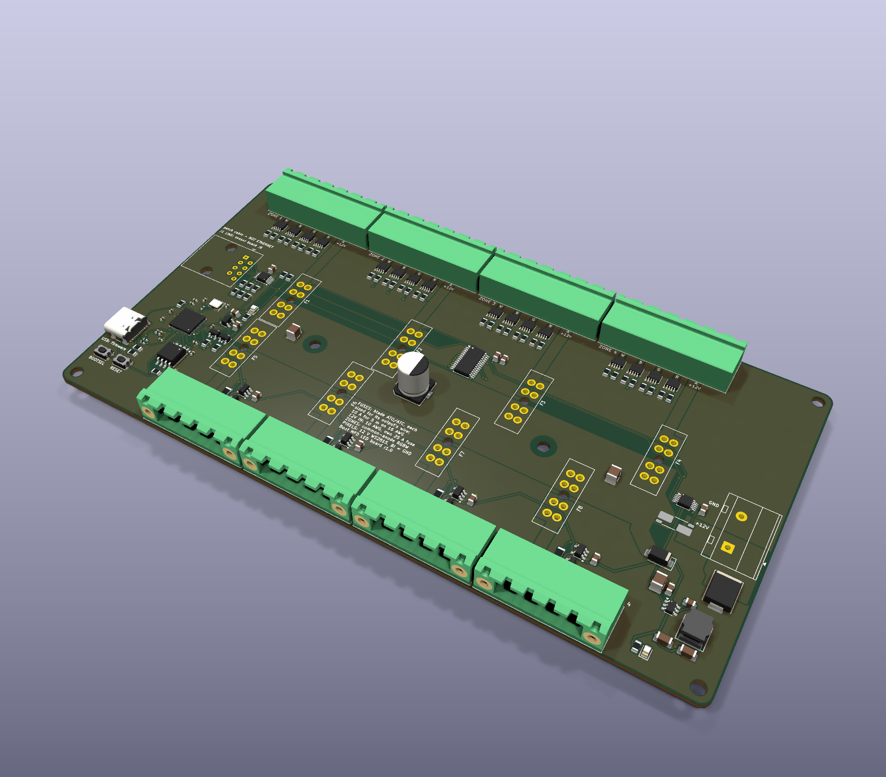
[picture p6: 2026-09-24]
hardware/led-board/fab/led-board-angle.png

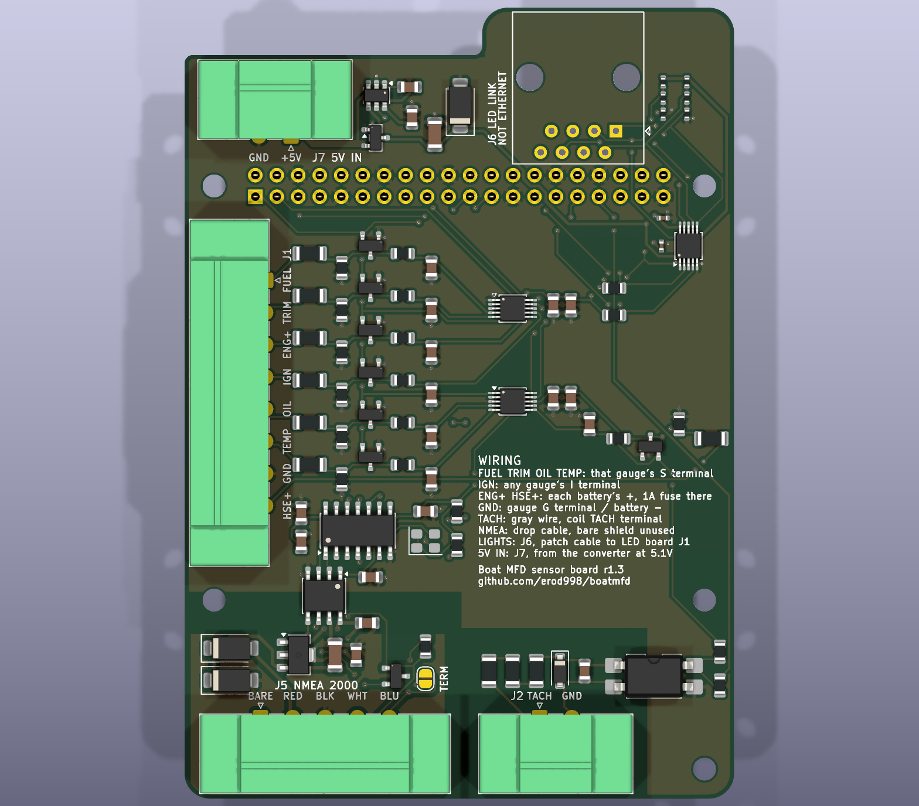
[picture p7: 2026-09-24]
hardware/sensor-board/fab/sensor-board-top.png

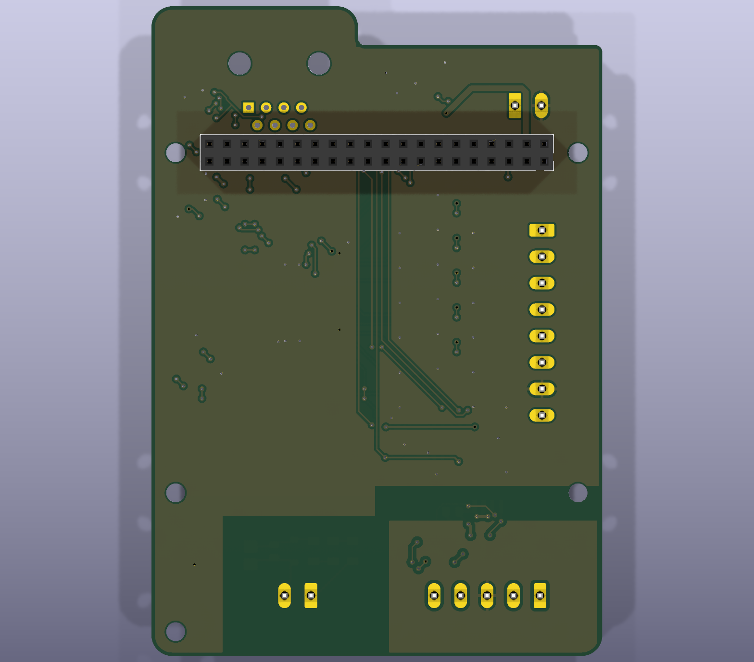
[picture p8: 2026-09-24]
hardware/sensor-board/fab/sensor-board-bottom.png

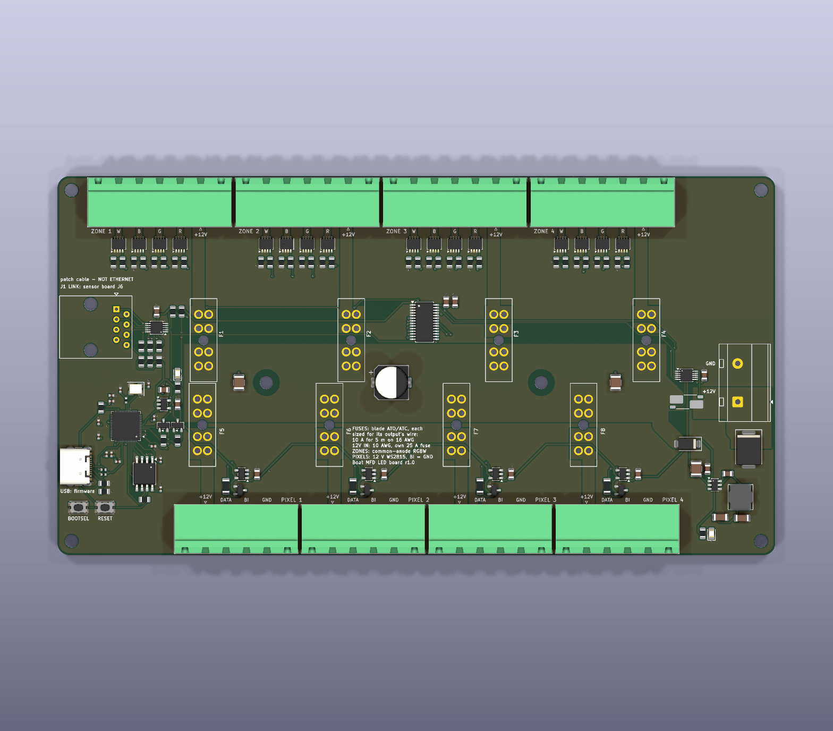
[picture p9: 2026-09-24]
hardware/led-board/fab/led-board-top.png

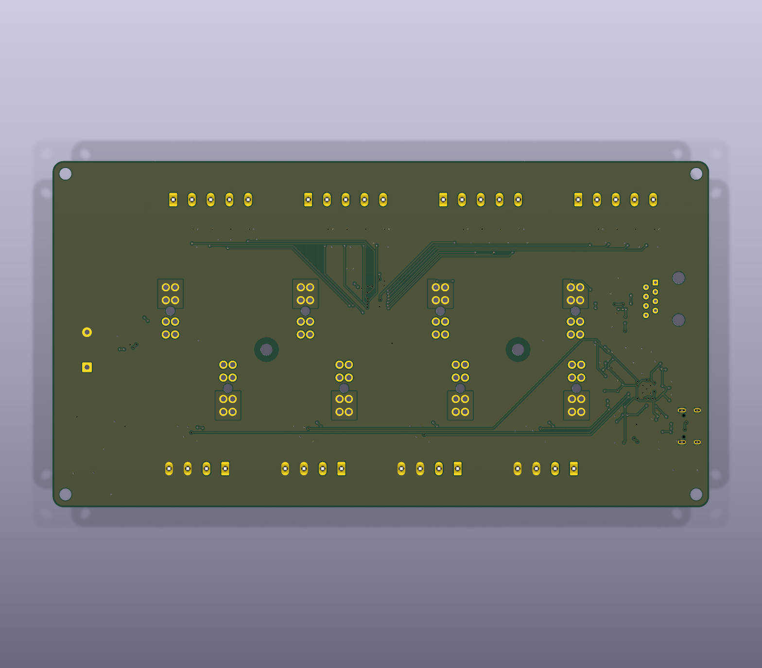
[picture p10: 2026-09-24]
hardware/led-board/fab/led-board-bottom.png

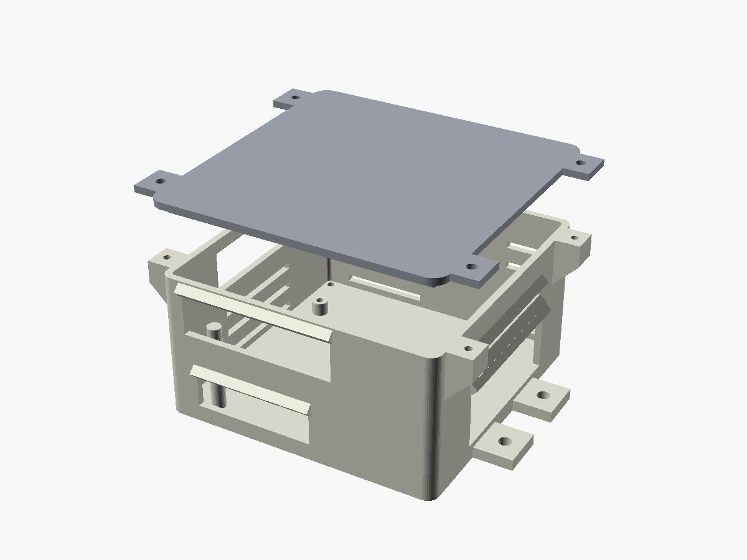
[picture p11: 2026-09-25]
hardware/enclosures/preview-lids.png

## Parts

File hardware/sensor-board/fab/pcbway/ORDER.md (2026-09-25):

# Ordering the sensor board from PCBWay

Board rev 1.3: 65 × 94 mm overall (the HAT, a 35 × 12 mm tab for the 5 V input and a taller tab for
the RJ45), 2 layers. Everything here is generated by `build.py`; rebuild before
ordering if the design has changed since.

## Checked before ordering

- **KiCad's checks**: the electrical rules check (ERC), the design rules check (DRC) and the
  schematic-to-board parity check report nothing at any severity. PCBWay's own limits are
  written into the design rules, so DRC enforces them: 0.2 mm tracks and gaps (8/8 mil, the
  setting PCBWay needs for 2 oz copper, so both boards go on one order), a 0.15 mm annular ring (vias here have 0.2), 16 mil between holes, 0.25 mm copper to a
  routed edge (0.3 here), silkscreen 0.8 mm tall with a 0.15 mm stroke.
- **Pinouts read from the manufacturers' datasheets**, not assumed from KiCad's library:
  ISO1044 (TI), MCP2518FD (Microchip, Table 1-1), uA78L05 in SOT-89 (TI: 1 out, 2 ground,
  3 in), NUP2105L (onsemi), EL817 (Everlight, including its surface-mount land pattern against
  the footprint), the Abracon ASE oscillator (pin 1 enable tied high = running).
- **Part numbers** in the BOM are all real, orderable parts; the Phoenix Contact numbers were
  looked up one by one.

## Files

| Upload | File |
| --- | --- |
| Gerbers + drill (PCB quote) | `sensor-board-gerbers.zip` |
| BOM (assembly quote) | `sensor-board-pcbway-bom.csv` |
| Centroid / pick-and-place (assembly quote) | `sensor-board-pcbway-centroid.csv` |
| For reference, if PCBWay asks | `../sensor-board-assembly.pdf`, `../sensor-board-schematic.pdf` |

## The bare board: pcbway.com → PCB Instant Quote → Quick-order PCB

Upload the Gerber zip; PCBWay reads the size and layers from it. Then:

| Option | Choose |
| --- | --- |
| Board type | Single pieces |
| Size | 65 × 94 mm (from the Gerbers; not a rectangle, the tabs are part of the outline) |
| Quantity | 5 (PCBWay's minimum; spares are handy) |
| Layers | 2 |
| Material | FR-4, TG130-140 |
| Thickness | 1.6 mm |
| Min track / spacing | 8/8 mil |
| Min hole size | 0.3 mm |
| Solder mask / silkscreen | Green / White |
| Edge connector | No |
| Surface finish | HASL lead free (or Immersion gold, ENIG, for flatter pads under the 0.5 mm-pitch ADCs -- worth it if PCBWay assembles) |
| Via process | Tenting vias |
| Finished copper | 1 oz |
| Remove product No. | Your choice: PCBWay prints an order number on the silkscreen unless told otherwise |

If you're assembling by hand, add a **stencil** (framework: none) -- it makes the fine-pitch
parts far easier.

## Assembled by PCBWay: pcbway.com → PCB Assembly

| Option | Choose |
| --- | --- |
| Service | Turnkey (PCBWay buys the parts) |
| Quantity | 1-5 |
| Assembly sides | Top side (every SMD part is on top; J4 goes on the bottom but is through-hole, soldered from the top) |
| Unique parts | 37 lines in the BOM |
| SMD pads | 228 |
| Through-hole pins | 65 (J1, J2, J4, J5, J6, J7) |
| Board | the same settings as above, ENIG finish |

In the notes: *"Assemble all SMD parts. Through-hole J1, J2, J5, J6, J7 and J4: [assemble / do
not fit -- customer will solder]. JP1 is a solder jumper: leave it OPEN."*

Soldering the six through-hole connectors yourself is easy and saves the through-hole charge;
J4 in particular (the 2×20 stacking header, Adafruit 1979) may be easier to buy yourself.

PCBWay's engineers review every order and may email about substitutions -- the likely ones are
Y1 (any 40 MHz 3.3 V CMOS oscillator in the 3.2 × 2.5 mm ASE footprint is fine) and U3 (any
PC817-type gull-wing optocoupler, CTR rank C or B). U7 (LM74700-Q1) has no drop-in substitute:
if it's out of stock, say so and wait rather than accept another part.

## Also buy, for the wiring (not on the board)

| Qty | Part |
| --- | --- |
| 1 each | Phoenix Contact plugs: 1827761 (8-pos, J1), 1827732 (5-pos, J5) |
| 1 | Phoenix Contact plug 1827703 (2-pos, J2). A second one for J7 only if a Pi without an SSD is powered through it |
| 1 | 12 V -> 5 V **USB-C** converter for the Pi 5's own USB-C: **5 A**, 5.1-5.2 V, with output overvoltage protection, sealed, and a short USB-C cable rated 5 A. On the boat J7 stays unconnected (SENSOR_BOARD.md, "5 V in") |
| 1 | NMEA 2000 drop cable with a female Micro-C end (cut the other end into J5's plug) |
| 5 | M2.5 standoffs and screws, tall enough to stack over the Pi 5's M.2 SSD board |
| 2 | inline fuse holder + 1 A fuse: the engine (J1.3) and house (J1.8) battery leads, one at each battery |
| 1 | straight-through Cat5e/Cat6 patch cable, for J6 -- only once the LED board exists. **Never** plug J6 into a network switch or PoE injector |

Bring-up, one block at a time, is in `SENSOR_BOARD.md`.

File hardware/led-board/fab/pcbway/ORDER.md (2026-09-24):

# Ordering the LED board from PCBWay

Board rev 1.0: 178 × 94 mm, 2 layers, **2 oz copper**. Everything here is generated by `build.py`;
rebuild before ordering if the design has changed since.

## Checked before ordering

- **KiCad's checks**: the electrical rules check (ERC), the design rules check (DRC) and the
  schematic-to-board parity check report nothing at any severity. PCBWay's limits for 2 oz copper
  are in the design rules, so DRC enforces them: 0.2 mm tracks and gaps (8/8 mil, the setting 2 oz
  needs; the strips' current runs on 1.5-6 mm tracks and pours), 0.3 mm minimum drill (vias 0.6 mm with 0.3 mm holes), 0.41 mm
  between holes, 0.25 mm hole to copper, 0.3 mm copper to the edge, silkscreen 0.8 mm tall.
- **One exception, on purpose**: the USB-C socket's two plastic locating pegs (J11) sit 0.19 mm
  from its own ground pads. That's GCT's land pattern for the USB4105, the one the part is made to
  fit, so the 0.25 mm hole-to-copper rule is relaxed for J11 alone (`led-board.kicad_dru`). If
  PCBWay's review flags it, that's the answer.
- **The RP2040's pins are 0.2 mm apart** (0.4 mm pitch), right at 8 mil: that's the part's own
  land pattern, and its tracks leave the pins at the same 0.2 mm.
- **The RP2040's exposed-pad vias** are drilled 0.3 mm (KiCad's footprint has 0.2 mm, under
  PCBWay's standard minimum).

## Files

| Upload | File |
| --- | --- |
| Gerbers + drill (PCB quote) | `led-board-gerbers.zip` |
| BOM (assembly quote) | `led-board-pcbway-bom.csv` |
| Centroid / pick-and-place (assembly quote) | `led-board-pcbway-centroid.csv` |
| For reference, if PCBWay asks | `../led-board-assembly.pdf`, `../led-board-schematic.pdf` |

## The bare board: pcbway.com → PCB Instant Quote → Quick-order PCB

| Option | Choose |
| --- | --- |
| Board type | Single pieces |
| Size | 178 × 94 mm |
| Quantity | 5 (PCBWay's minimum) |
| Layers | 2 |
| Material | FR-4, TG150 (it runs warm at 20 A) |
| Thickness | 1.6 mm |
| **Finished copper** | **2 oz** -- the 20 A input, the bus and the outputs are sized for it. 1 oz is not enough |
| Min track / spacing | **8/8 mil** -- PCBWay only offers 2 oz copper at 8/8 or wider |
| Min hole size | 0.3 mm |
| Solder mask / silkscreen | Green / White |
| Surface finish | **Immersion gold (ENIG)**: flat pads for the RP2040's 0.4 mm pitch |
| Via process | Tenting vias |

## Assembled by PCBWay: pcbway.com → PCB Assembly

| Option | Choose |
| --- | --- |
| Service | Turnkey (PCBWay buys the parts) |
| Quantity | 1-5 |
| Assembly sides | Top side only (every part is on top) |
| Unique parts | 53 lines in the BOM |
| SMD pads | 457 |
| Through-hole pins | 114 (F1-F8, J1-J10; J11's shell pins are part of an SMD part) |
| Board | the settings above: 2 oz, ENIG |

In the notes: *"Assemble all SMD parts. Through-hole F1-F8 (fuse holders), J1 (RJ45), J2 (screw
terminal) and J3-J10 (pluggable headers): [assemble / do not fit -- customer will solder]. No
programming: the RP2040's firmware is loaded over USB after delivery."*

The through-hole parts are big and easy to solder yourself, and it saves the through-hole charge.
The fuse holders and J2 carry up to 20 A: plenty of solder, fully wetted, on every pin.

Likely substitution questions: Y1 (any 12 MHz crystal in the same 3.2 × 2.5 mm footprint with
the same load capacitance), the MOSFETs (the BOM's logic-level part, or an equivalent in LFPAK33
with Rds(on) at 4.5 V gate no higher). The RP2040, PCA9615, PCA9685 and INA226 have no drop-in
substitutes: if one is out of stock, say so and wait.

## Also buy, for the wiring (not on the board)

| Qty | Part |
| --- | --- |
| 4 | Phoenix Contact plug 1778014 (MSTB 2,5/ 5-STF-5,08, for the zone outputs J3-J6) |
| 4 | Phoenix Contact plug 1778001 (MSTB 2,5/ 4-STF-5,08, for the addressable outputs J7-J10) |
| 8 | ATO/ATC blade fuses, sized for each output's wire: 10 A for 5 m of strip on 16 AWG (see LED_BOARD.md) |
| 1 | 25 A fuse or breaker at the supply, and 10 AWG wire for the feed to J2 and its ground |
| 1 | straight-through Cat5e/Cat6 patch cable, sensor board J6 to this board's J1. **Never** plug either into a network switch or PoE injector |
| 6 | M3 standoffs and screws (nylon, or plain standoffs, for the two in the middle of the 12 V bus) |
| 1 | a sealed enclosure |

Bring-up and loading the firmware are in `LED_BOARD.md`.

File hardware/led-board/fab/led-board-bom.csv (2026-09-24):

Comment | Designator | Footprint | MPN | Qty | Mount | Note
100n | C1,C5,C11,C12,C14,C15,C16,C17,C18 | 0805 | CL21B104KBCNNNC | 9 | SMD | U1 decoupling; U5 decoupling; U6 input, high frequency; U6 bootstrap; U7 decoupling; U8 decoupling; U9 decoupling; U10 decoupling; U4 decoupling
22u | C13,C19 | 1206 | CL31A226KAHNNNE | 2 | SMD | U6 output
100n | C20,C23,C24,C25,C26,C27,C28,C31,C32 | 0402 | CL05B104KO5NNNC | 9 | SMD | U3 decoupling; U2 IOVDD (pin 1); U2 IOVDD (pin 10); U2 IOVDD (pin 22); U2 IOVDD (pin 33); U2 IOVDD and ADC_AVDD (pins 42, 43); U2 USB_VDD and IOVDD (pins 48, 49); U2 DVDD (pin 23); U2 DVDD (pin 50)
15p | C21,C22 | 0402 | CL05C150JB5NNNC | 2 | SMD | crystal load
1u | C29,C30 | 0402 | CL05A105KA5NQNC | 2 | SMD | U2 VREG_VIN (pin 44); U2 VREG_VOUT (pin 45): the 1.1 V core supply
10u | C34 | 0805 | CL21A106KAYNNNE | 1 | SMD | U11 output, the 3.3 V bulk
1u | C6,C33 | 0805 | CL21B105KAFNNNE | 2 | SMD | U5 decoupling; U11 input
100u 35V | C7 | CP | EEE-FK1V101P | 1 | SMD | 12 V bulk: the PWM's current steps, and damping for the feed wire
10u | C8,C9,C10 | 1210 | CL32B106KBJNNNE | 3 | SMD | 12 V bypass, zone side; 12 V bypass, pixel side; U6 input (50 V)
SMCJ18A | D1 | SMC | SMCJ18A | 1 | SMD | 1500 W surge clamp on the 12 V input (18 V stand-off)
SS14 | D2 | SMA | SS14 | 1 | SMD | reverse polarity protection for the logic supply
BAT54S | D3,D4,D5,D6 | SOT-23 | BAT54S,215 | 4 | SMD | clamps J7's data line between GND and 5 V; clamps J8's data line between GND and 5 V; clamps J9's data line between GND and 5 V; clamps J10's data line between GND and 5 V
green | D7 | LED | LTST-C171GKT | 1 | SMD | lit when the board has 12 V
yellow | D8 | LED | LTST-C171YKT | 1 | SMD | the RP2040's status: blinks while its firmware runs
USB | J11 | USB_C_Receptacle_GCT_USB4105-xx-A_16P_TopMnt_Horizontal | GCT USB4105-GF-A | 1 | SMD | firmware loading only (VBUS unused: the board must have its 12 V)
6.8u | L1 | L | SRN6045TA-6R8M | 1 | SMD | U6's inductor
BUK9M7R2-40E | Q1,Q2,Q3,Q4,Q5,Q6,Q7,Q8,Q9,Q10,Q11,Q12,Q13,Q14,Q15,Q16 | LFPAK33 | BUK9M7R2-40EX | 16 | SMD | zone 1 R: PCA9685 output 0; zone 1 G: PCA9685 output 1; zone 1 B: PCA9685 output 2; zone 1 W: PCA9685 output 3; zone 2 R: PCA9685 output 4; zone 2 G: PCA9685 output 5; zone 2 B: PCA9685 output 6; zone 2 W: PCA9685 output 7; zone 3 R: PCA9685 output 8; zone 3 G: PCA9685 output 9; zone 3 B: PCA9685 output 10; zone 3 W: PCA9685 output 11; zone 4 R: PCA9685 output 12; zone 4 G: PCA9685 output 13; zone 4 B: PCA9685 output 14; zone 4 W: PCA9685 output 15
BSS138 | Q17,Q18 | SOT-23 | BSS138 | 2 | SMD | SDA level shift, 3.3 V to 5 V; SCL level shift, 3.3 V to 5 V
100 | R1,R2,R3,R4,R5,R6,R7,R8,R9,R10,R11,R12,R13,R14,R15,R16 | 0805 | RC0805FR-07100RL | 16 | SMD | gate resistor
47k | R17,R18,R19,R20,R21,R22,R23,R24,R25,R26,R27,R28,R29,R30,R31,R32 | 0805 | RC0805FR-0747KL | 16 | SMD | gate pull-down
620 | R33,R35,R36,R38 | 0805 | RC0805FR-07620RL | 4 | SMD | link SCL pair: bias (pull-up); link SCL pair: bias (pull-down); link SDA pair: bias (pull-up); link SDA pair: bias (pull-down)
120 | R34,R37 | 0805 | RC0805FR-07120RL | 2 | SMD | link SCL pair: termination; link SDA pair: termination
4.7k | R39,R40 | 0805 | RC0805FR-074K7L | 2 | SMD | I2C pull-up, 5 V side
10k | R41,R42,R49 | 0805 | RC0805FR-0710KL | 3 | SMD | I2C pull-up, RP2040 side; RUN pull-up
330 | R43,R44,R45,R46 | 1206 | RC1206FR-07330RL | 4 | SMD | J7 data series resistor; J8 data series resistor; J9 data series resistor; J10 data series resistor
1m | R47 | 2512 (4-terminal) | WSK25121L000FEA | 1 | SMD | 1 mOhm, 1 W, four-terminal: 20 A makes 20 mV and 0.4 W
1k | R48 | 0402 | RC0402FR-071KL | 1 | SMD | limits the crystal's drive
1k | R50,R55 | 0805 | RC0805FR-071KL | 2 | SMD | BOOTSEL button to the flash's chip select; status LED
27 | R51,R52 | 0402 | RC0402FR-0727RL | 2 | SMD | USB series resistor
5.1k | R53,R54 | 0805 | RC0805FR-075K1L | 2 | SMD | USB-C: identifies the board as a device
2.2k | R56 | 0805 | RC0805FR-072K2L | 1 | SMD | power LED
BOOTSEL | SW1 | SW | KMR221GLFS | 1 | SMD | held during reset: U2 starts as a USB drive, to load firmware
RESET | SW2 | SW | KMR221GLFS | 1 | SMD | resets U2
PCA9615DP | U1 | TSSOP-10 | PCA9615DP,118 | 1 | SMD | differential I2C from the RJ45, back to plain I2C
AP2112K-3.3 | U11 | SOT-23-5 | AP2112K-3.3TRG1 | 1 | SMD | 3.3 V for the RP2040 and its flash
RP2040 | U2 | QFN-56-1EP | RP2040 | 1 | SMD | runs the addressable outputs; I2C target at 0x30
W25Q16JV | U3 | SOIC-8 | W25Q16JVSSIQ | 1 | SMD | U2's program (2 MB QSPI flash)
INA226 | U4 | TSSOP-10 | INA226AIDGSR | 1 | SMD | the board's current and voltage, I2C address 0x45
PCA9685PW | U5 | TSSOP-28 | PCA9685PW,118 | 1 | SMD | 16 PWM channels, I2C address 0x40
AP63205 | U6 | TSOT-23-6 | AP63205WU-7 | 1 | SMD | 5 V for the logic, 2 A buck (about 100 mA used)
74AHCT1G125 | U7,U8,U9,U10 | SOT-23-5 | SN74AHCT1G125DBVR | 4 | SMD | pixel output 1: 3.3 V data to 5 V; pixel output 2: 3.3 V data to 5 V; pixel output 3: 3.3 V data to 5 V; pixel output 4: 3.3 V data to 5 V
12MHz | Y1 | 3225-4Pin | ABM8-272-T3 | 1 | SMD | U2's clock: the crystal Raspberry Pi specify, with its 15 pF loads and 1k in XOUT
ATO | F1,F2,F3,F4,F5,F6,F7,F8 | FuseHolder_Blade_ATO_Littelfuse_FLR_178.6165 | Littelfuse 178.6165.0002 (ATO/ATC holder, 30 A) | 8 | THT (hand solder) | zone 1's fuse: a standard blade (ATO/ATC) fuse sized for the strip's wire -- 10 A for 5 m of RGBW on 16 AWG; zone 2's fuse: a standard blade (ATO/ATC) fuse sized for the strip's wire -- 10 A for 5 m of RGBW on 16 AWG; zone 3's fuse: a standard blade (ATO/ATC) fuse sized for the strip's wire -- 10 A for 5 m of RGBW on 16 AWG; zone 4's fuse: a standard blade (ATO/ATC) fuse sized for the strip's wire -- 10 A for 5 m of RGBW on 16 AWG; J7's fuse: a standard blade (ATO/ATC) fuse -- 10 A for 5 m of WS2815 on 16 AWG; J8's fuse: a standard blade (ATO/ATC) fuse -- 10 A for 5 m of WS2815 on 16 AWG; J9's fuse: a standard blade (ATO/ATC) fuse -- 10 A for 5 m of WS2815 on 16 AWG; J10's fuse: a standard blade (ATO/ATC) fuse -- 10 A for 5 m of WS2815 on 16 AWG
LINK | J1 | RJ45_Amphenol_54602-x08_Horizontal | Amphenol 54602-908LF | 1 | THT (hand solder) | to the sensor board's J6: a straight-through Cat5e/Cat6 patch cable. NOT Ethernet: never plug either end into a network switch or a PoE injector
PIXEL 4 | J10 | PhoenixContact_MSTB_2,5_4-GF-5,08_1x04_P5.08mm_Horizontal_ThreadedFlange | Phoenix Contact 1776524 (MSTB 2,5/ 4-GF-5,08); plug 1778001 (MSTB 2,5/ 4-STF-5,08) | 1 | THT (hand solder) | 12 V addressable strip (WS2815...): 1 +12V, 2 DATA, 3 BI (ground), 4 GND; 12 A per pin
12V IN | J2 | TerminalBlock_MetzConnect_Type703_RT10N02HGLU_1x02_P9.52mm_Horizontal | METZ CONNECT RT10N02HGLU | 1 | THT (hand solder) | the strips' 12 V, 20 A (the terminal is rated 24 A, 10 AWG), from its own 25 A fuse
ZONE 1 | J3 | PhoenixContact_MSTB_2,5_5-GF-5,08_1x05_P5.08mm_Horizontal_ThreadedFlange | Phoenix Contact 1776537 (MSTB 2,5/ 5-GF-5,08); plug 1778014 (MSTB 2,5/ 5-STF-5,08) | 1 | THT (hand solder) | RGBW strip, common anode: 1 +12V, 2 R, 3 G, 4 B, 5 W (PCA9685 outputs 0-3); 12 A per pin
ZONE 2 | J4 | PhoenixContact_MSTB_2,5_5-GF-5,08_1x05_P5.08mm_Horizontal_ThreadedFlange | Phoenix Contact 1776537 (MSTB 2,5/ 5-GF-5,08); plug 1778014 (MSTB 2,5/ 5-STF-5,08) | 1 | THT (hand solder) | RGBW strip, common anode: 1 +12V, 2 R, 3 G, 4 B, 5 W (PCA9685 outputs 4-7); 12 A per pin
ZONE 3 | J5 | PhoenixContact_MSTB_2,5_5-GF-5,08_1x05_P5.08mm_Horizontal_ThreadedFlange | Phoenix Contact 1776537 (MSTB 2,5/ 5-GF-5,08); plug 1778014 (MSTB 2,5/ 5-STF-5,08) | 1 | THT (hand solder) | RGBW strip, common anode: 1 +12V, 2 R, 3 G, 4 B, 5 W (PCA9685 outputs 8-11); 12 A per pin
ZONE 4 | J6 | PhoenixContact_MSTB_2,5_5-GF-5,08_1x05_P5.08mm_Horizontal_ThreadedFlange | Phoenix Contact 1776537 (MSTB 2,5/ 5-GF-5,08); plug 1778014 (MSTB 2,5/ 5-STF-5,08) | 1 | THT (hand solder) | RGBW strip, common anode: 1 +12V, 2 R, 3 G, 4 B, 5 W (PCA9685 outputs 12-15); 12 A per pin
PIXEL 1 | J7 | PhoenixContact_MSTB_2,5_4-GF-5,08_1x04_P5.08mm_Horizontal_ThreadedFlange | Phoenix Contact 1776524 (MSTB 2,5/ 4-GF-5,08); plug 1778001 (MSTB 2,5/ 4-STF-5,08) | 1 | THT (hand solder) | 12 V addressable strip (WS2815...): 1 +12V, 2 DATA, 3 BI (ground), 4 GND; 12 A per pin
PIXEL 2 | J8 | PhoenixContact_MSTB_2,5_4-GF-5,08_1x04_P5.08mm_Horizontal_ThreadedFlange | Phoenix Contact 1776524 (MSTB 2,5/ 4-GF-5,08); plug 1778001 (MSTB 2,5/ 4-STF-5,08) | 1 | THT (hand solder) | 12 V addressable strip (WS2815...): 1 +12V, 2 DATA, 3 BI (ground), 4 GND; 12 A per pin
PIXEL 3 | J9 | PhoenixContact_MSTB_2,5_4-GF-5,08_1x04_P5.08mm_Horizontal_ThreadedFlange | Phoenix Contact 1776524 (MSTB 2,5/ 4-GF-5,08); plug 1778001 (MSTB 2,5/ 4-STF-5,08) | 1 | THT (hand solder) | 12 V addressable strip (WS2815...): 1 +12V, 2 DATA, 3 BI (ground), 4 GND; 12 A per pin

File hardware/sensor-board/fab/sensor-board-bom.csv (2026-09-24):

Comment | Designator | Footprint | MPN | Qty | Mount | Note
100n | C1,C2,C3,C4,C5,C6,C7,C9,C12,C14,C15,C18,C19,C20,C24 | 0805 | CL21B104KBCNNNC | 15 | SMD | ADC input filter; U1 decoupling; U2 decoupling; U4 decoupling; Y1 decoupling; U5 Pi-side decoupling; U5 network-side decoupling; U7 charge pump (VCAP to ANODE); J7 input
10n | C11 | 0805 | CL21B103KBANNNC | 1 | SMD | filters the ring-down after each spark
1u | C16 | 1206 | CL31B105KBHNNNE | 1 | SMD | regulator input (50 V)
4.7u | C17 | 0805 | CL21A475KAQNNNE | 1 | SMD | regulator output; U5's VCC2 bulk (TI: ~4.7 uF)
22u | C21 | 1206 | CL31A226KAHNNNE | 1 | SMD | bulk at the Pi's 5 V pins
100n | C22,C23 | 0402 | CL05B104KO5NNNC | 2 | SMD | U8 decoupling, 3.3 V side; U8 decoupling, cable side
1u | C8,C10,C13 | 0805 | CL21B105KAFNNNE | 3 | SMD | U1 decoupling; U2 decoupling; U4 decoupling
BAT54S | D1,D2,D3,D4,D5,D6,D13 | SOT-23 | BAT54S,215 | 7 | SMD | clamps the divider node between GND and 3V3
SMAJ18A | D10 | SMA | SMAJ18A | 1 | SMD | clamps surges on the network's power
NUP2105L | D11 | SOT-23 | NUP2105LT1G | 1 | SMD | ESD and surge protection for NET-H / NET-L
SMAJ5.0A | D12 | SMA | SMAJ5.0A | 1 | SMD | clamps spikes on the 5 V rail
1N4148W | D7 | SOD-123 | 1N4148W-7-F | 1 | SMD | keeps the ring-down's negative swing off the LED
SS14 | D9 | SMA | SS14 | 1 | SMD | reverse-polarity protection on NET-S
IRLML0030 | Q1 | SOT-23 | IRLML0030TRPBF | 1 | SMD | the ideal diode's switch: source to J7, drain to the Pi; 27 mOhm, VGS +/-20 V
49.9k | R1,R2,R4,R5,R6 | 1206 | RC1206FR-0749K9L | 5 | SMD | tap top resistor (1206 for voltage rating)
1k | R13,R14,R15,R16,R17,R18,R23,R37 | 0805 | RC0805FR-071KL | 8 | SMD | ADC pin series resistor; protects the GPIO
3.3k | R19,R20,R21 | 1206 | RC1206FR-073K3L | 3 | SMD | tach input: 3 in series share the ignition spike
4.7k | R24,R25 | 0805 | RC0805FR-074K7L | 2 | SMD | LED board I2C pull-up (SDA, GPIO5); LED board I2C pull-up (SCL, GPIO6)
120 | R26 | 0805 | RC0805FR-07120RL | 1 | SMD | bench terminator, only with JP1 bridged
620 | R29,R31,R32,R34 | 0402 | RC0402FR-07620RL | 4 | SMD | link SCL pair: bias (pull-up); link SCL pair: bias (pull-down); link SDA pair: bias (pull-up); link SDA pair: bias (pull-down)
47k | R3,R35 | 1206 | RC1206FR-0747KL | 2 | SMD | tap top resistor (1206 for voltage rating)
120 | R30,R33 | 0402 | RC0402FR-07120RL | 2 | SMD | link SCL pair: termination; link SDA pair: termination
10k | R7,R8,R9,R10,R11,R12,R22,R27,R28,R36 | 0805 | RC0805FR-0710KL | 10 | SMD | divider bottom; opto pull-up; keeps U4 deselected while the Pi boots; interrupt pull-up
ADS1115IDGSR | U1,U2 | TSSOP-10 | ADS1115IDGSR | 2 | SMD | I2C 0x48: fuel, trim, battery, gauge supply; I2C 0x49: oil, engine temperature, house battery
EL817 | U3 | SMDIP-4 | EL817S1(C)(TU)-F | 1 | SMD | isolates the Pi from the ignition
MCP2518FD | U4 | SOIC-14 | MCP2518FDT-E/SL | 1 | SMD | SPI CAN FD controller (pin-for-pin successor to the MCP2517FD; Linux driver mcp251xfd)
ISO1044BD | U5 | SOIC-8 | ISO1044BDR | 1 | SMD | isolated CAN transceiver: the Pi side and the network side share no ground
UA78L05 | U6 | SOT-89-3 | UA78L05ACPK | 1 | SMD | 5 V for U5's network side, from NET-S
LM74700-Q1 | U7 | SOT-23-6 | LM74700QDBVRQ1 | 1 | SMD | ideal diode controller: ANODE/EN to J7, CATHODE to the Pi's 5 V
PCA9615DP | U8 | TSSOP-10 | PCA9615DP,118 | 1 | SMD | the LED board's I2C bus (GPIO5/6, 3.3 V) as differential I2C (5 V) on the RJ45
40MHz | Y1 | 3.2x2.5mm | ASE-40.000MHZ-L-C-T | 1 | SMD | U4's clock (oscillator=40000000 in the overlay)
HELM | J1 | PhoenixContact_MC_1,5_8-GF-3.81_1x08_P3.81mm_Horizontal_ThreadedFlange | Phoenix Contact 1827923 (MC 1,5/ 8-GF-3,81); plug 1827761 (MC 1,5/ 8-STF-3,81) | 1 | THT (hand solder) | FUEL/TRIM/OIL/TEMP: that gauge's S terminal; ENG+ / HSE+: the engine / house battery's + terminal (1 A fuse at the battery); IGN: any gauge's I terminal; GND: gauge G / battery -
TACH | J2 | PhoenixContact_MC_1,5_2-GF-3.81_1x02_P3.81mm_Horizontal_ThreadedFlange | Phoenix Contact 1827868 (MC 1,5/ 2-GF-3,81); plug 1827703 (MC 1,5/ 2-STF-3,81) | 1 | THT (hand solder) | TACH: the gray wire (EST coil TACH terminal); GND: the tach gauge's G terminal
RPi GPIO | J4 | PinSocket_2x20_P2.54mm_Vertical | 2x20 female stacking header, 2.54 mm, extra-tall (e.g. Adafruit 1979) | 1 | THT (hand solder) | to the Raspberry Pi
NMEA 2000 | J5 | PhoenixContact_MC_1,5_5-GF-3.81_1x05_P3.81mm_Horizontal_ThreadedFlange | Phoenix Contact 1827897 (MC 1,5/ 5-GF-3,81); plug 1827732 (MC 1,5/ 5-STF-3,81) | 1 | THT (hand solder) | NMEA 2000 drop cable, Micro-C order: 1 shield (bare, not connected), 2 NET-S red, 3 NET-C black, 4 NET-H white, 5 NET-L blue
LIGHTS | J6 | RJ45_Amphenol_54602-x08_Horizontal | Amphenol 54602-908LF | 1 | THT (hand solder) | to the LED board's J1: a straight-through Cat5e/Cat6 patch cable. NOT Ethernet: never plug either end into a network switch or a PoE injector
5V IN | J7 | PhoenixContact_MC_1,5_2-GF-3.81_1x02_P3.81mm_Horizontal_ThreadedFlange | Phoenix Contact 1827868 (MC 1,5/ 2-GF-3,81); plug 1827703 (MC 1,5/ 2-STF-3,81) | 1 | THT (hand solder) | from the 12 V -> 5 V converter (set 5.1-5.2 V, 3 A): 1 +5V, 2 GND

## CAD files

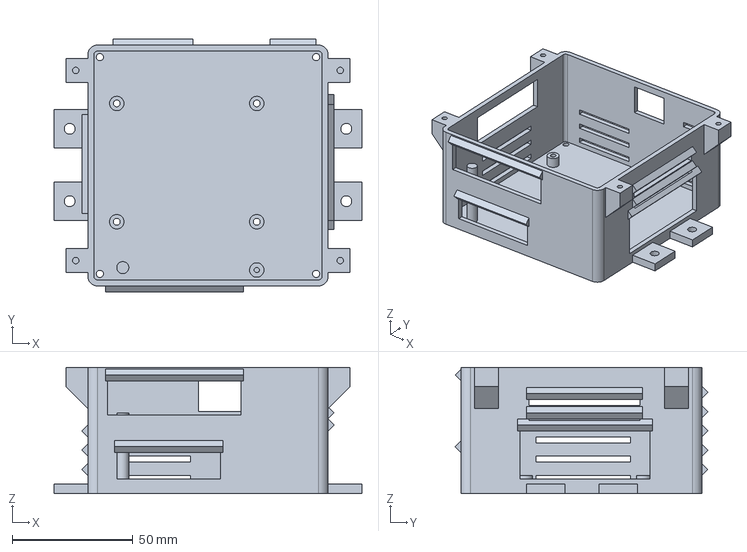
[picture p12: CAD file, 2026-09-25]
hardware/enclosures/out/pi-box-base.step
127.6 x 104.8 x 52.3 mm

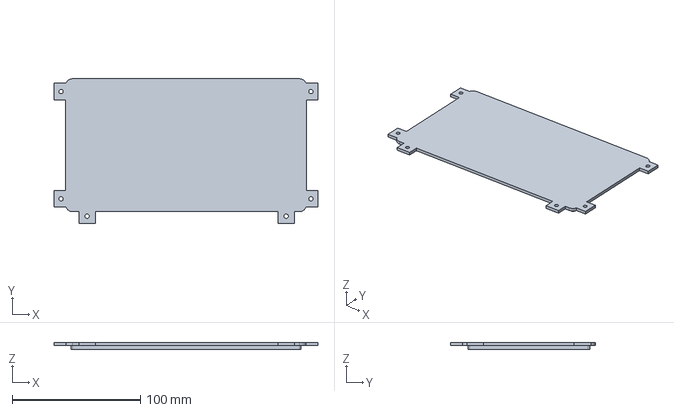
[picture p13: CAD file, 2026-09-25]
hardware/enclosures/out/led-box-lid.step
205.6 x 112.6 x 5.50 mm

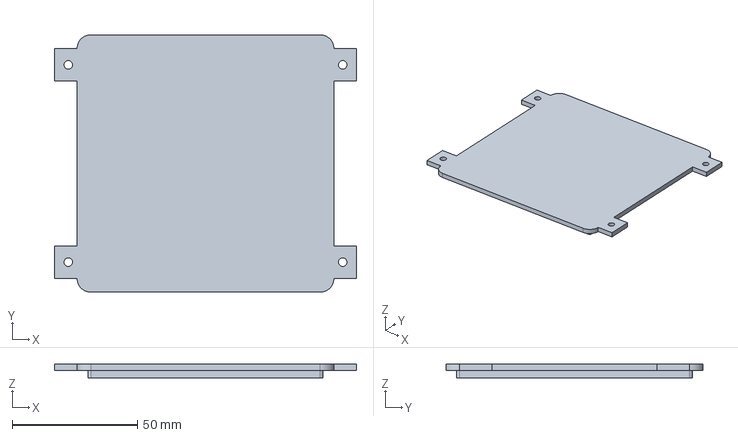
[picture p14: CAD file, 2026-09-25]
hardware/enclosures/out/pi-box-lid.step
120.6 x 102.8 x 5.50 mm

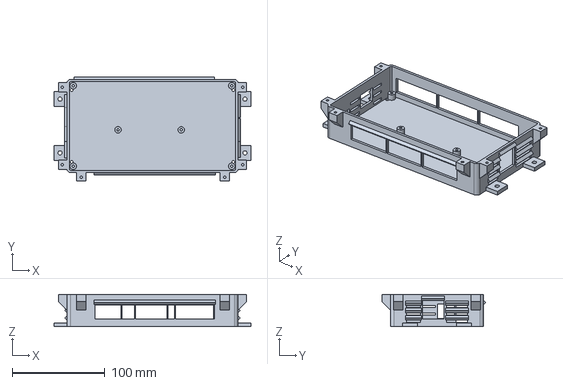
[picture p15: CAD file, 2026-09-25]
hardware/enclosures/out/led-box-base.step
212.6 x 112.1 x 35.0 mm

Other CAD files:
hardware/enclosures/out/led-box-base.3mf
hardware/enclosures/out/led-box-base.stl
hardware/enclosures/out/led-box-lid.3mf
hardware/enclosures/out/led-box-lid.stl
hardware/enclosures/out/pi-box-base.3mf
hardware/enclosures/out/pi-box-base.stl
hardware/enclosures/out/pi-box-lid.3mf
hardware/enclosures/out/pi-box-lid.stl

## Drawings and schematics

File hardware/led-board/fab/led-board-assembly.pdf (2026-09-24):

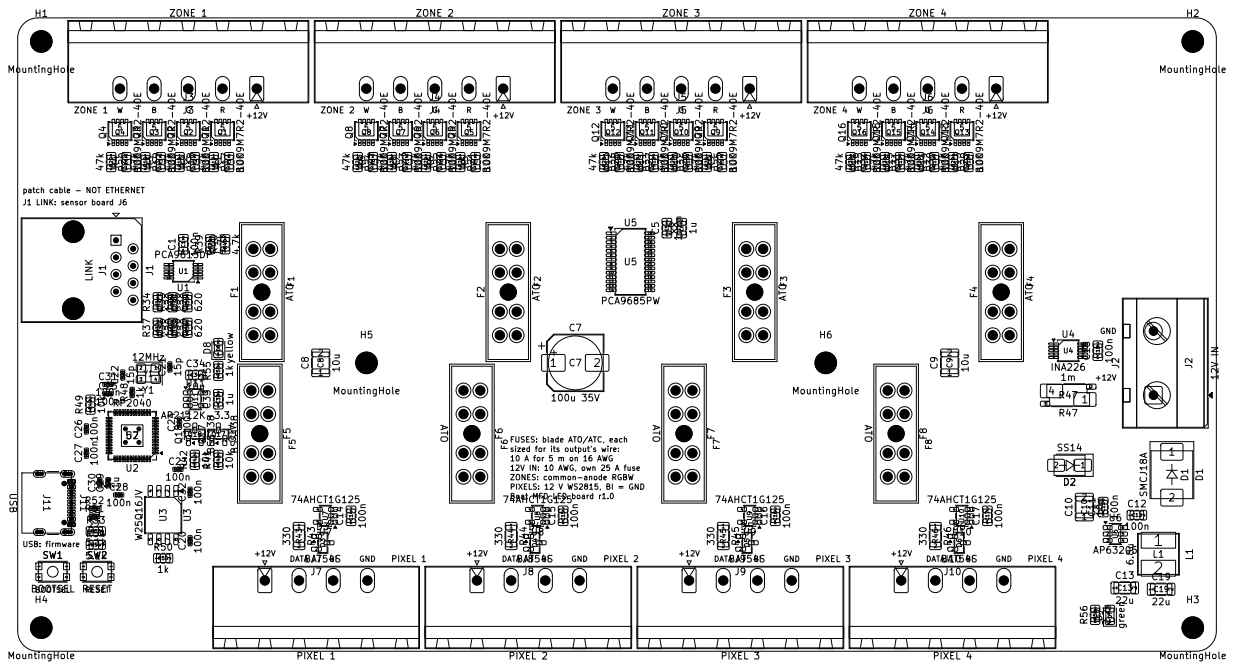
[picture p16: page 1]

patch cable - NOT ETHERNET
J1 LINK: sensor board J6

FUSES: blade ATO/ATC, each
sized for its output's wire: 10 A for 5 m on 16 AWG

12V IN: 10 AWG, own 25 A fuse ZONES: common-anode RGBW

Four RGBW zones and four addressable outputs, 20 A; RJ45 link to the sensor board

Sheet:
File: led-board.kicad_pcb
Title: Boat MFD LED board

Size: A4 | Rev: 1.0
KiCad E.D.A. 10.0.6 | Id: 1/1

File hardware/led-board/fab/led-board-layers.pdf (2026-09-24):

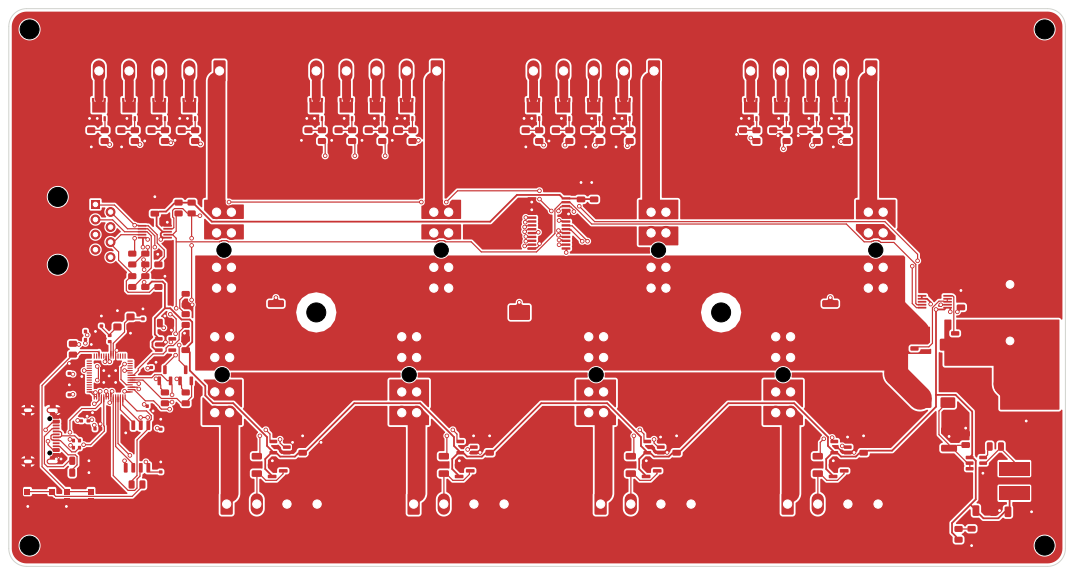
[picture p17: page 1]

Generated from design.py by board.py; edit those, not this file
Four RGBW zones and four addressable outputs, 20 A; RJ45 link to the sensor board

Sheet:
File: led-board.kicad_pcb
Title: Boat MFD LED board

Size: A4 | Rev: 1.0
KiCad E.D.A. 10.0.6 | Id: 1/4

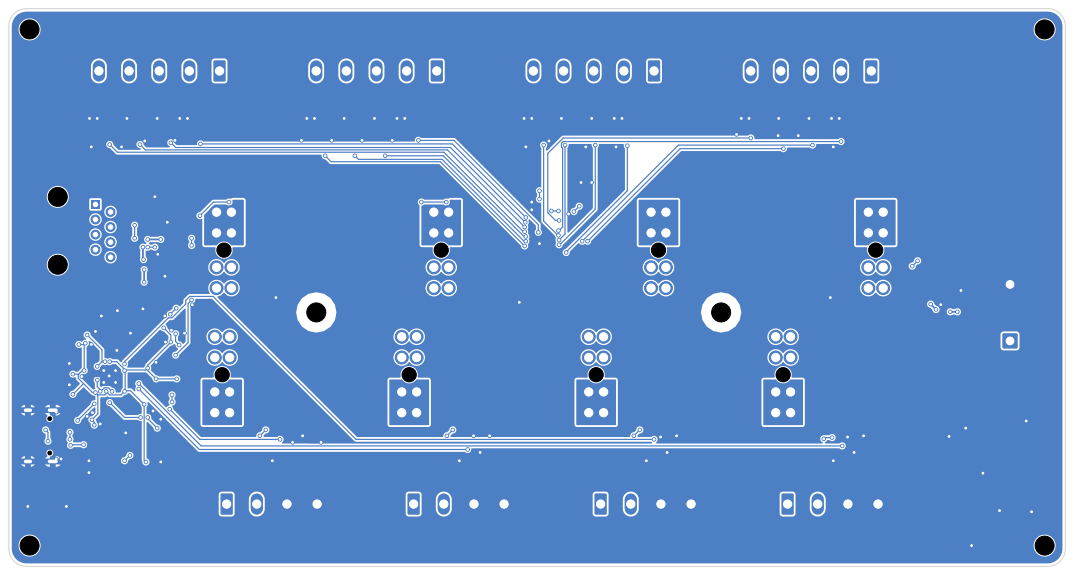
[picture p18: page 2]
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

Sheet:
File: led-board.kicad_pcb
Title: Boat MFD LED board

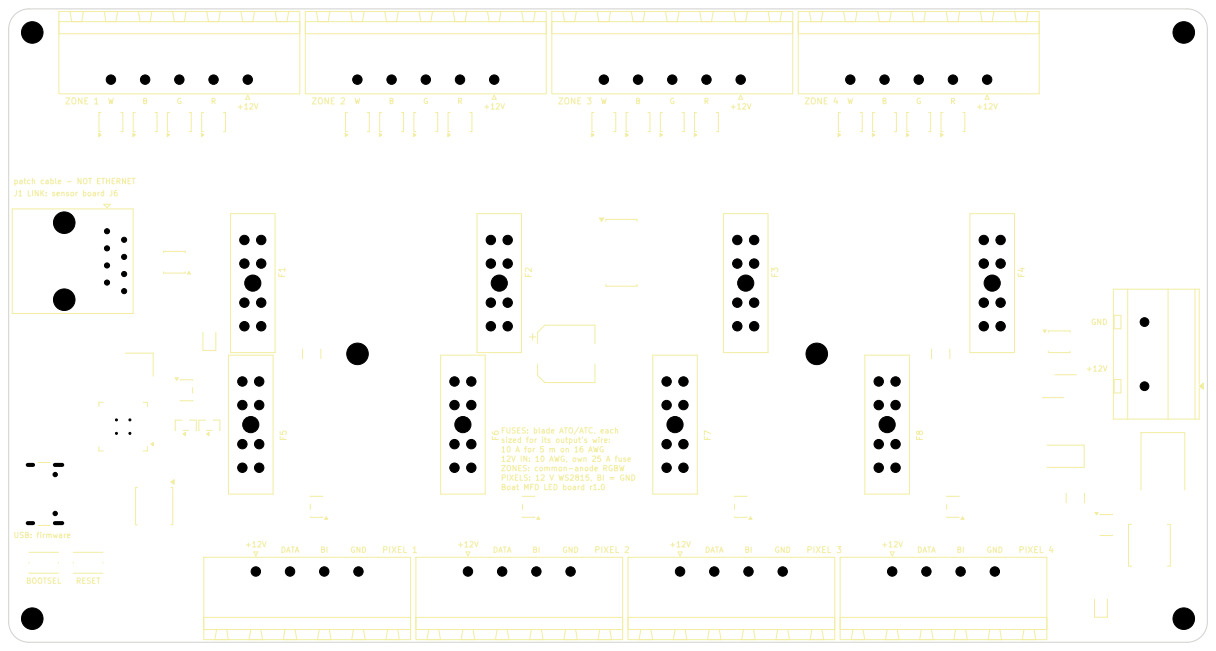
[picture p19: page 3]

patch cable - NOT ETHERNET
J1 LINK: sensor board J6

FUSES: blade ATO/ATC, each
sized for its output's wire: 10 A for 5 m on 16 AWG

12V IN: 10 AWG, own 25 A fuse ZONES: common-anode RGBW

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

Sheet:
File: led-board.kicad_pcb
Title: Boat MFD LED board

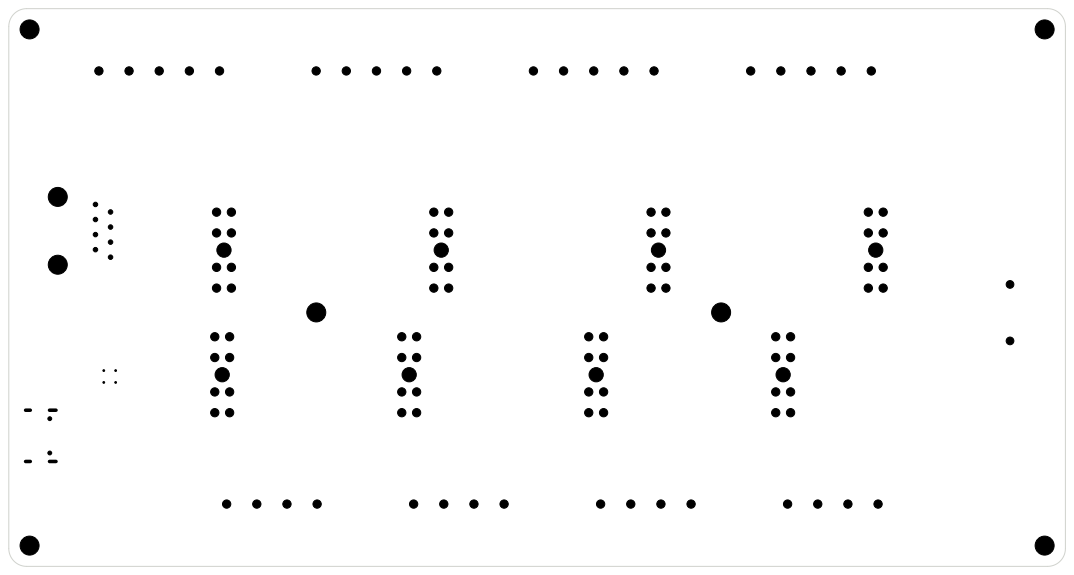
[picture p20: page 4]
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

Sheet:
File: led-board.kicad_pcb
Title: Boat MFD LED board

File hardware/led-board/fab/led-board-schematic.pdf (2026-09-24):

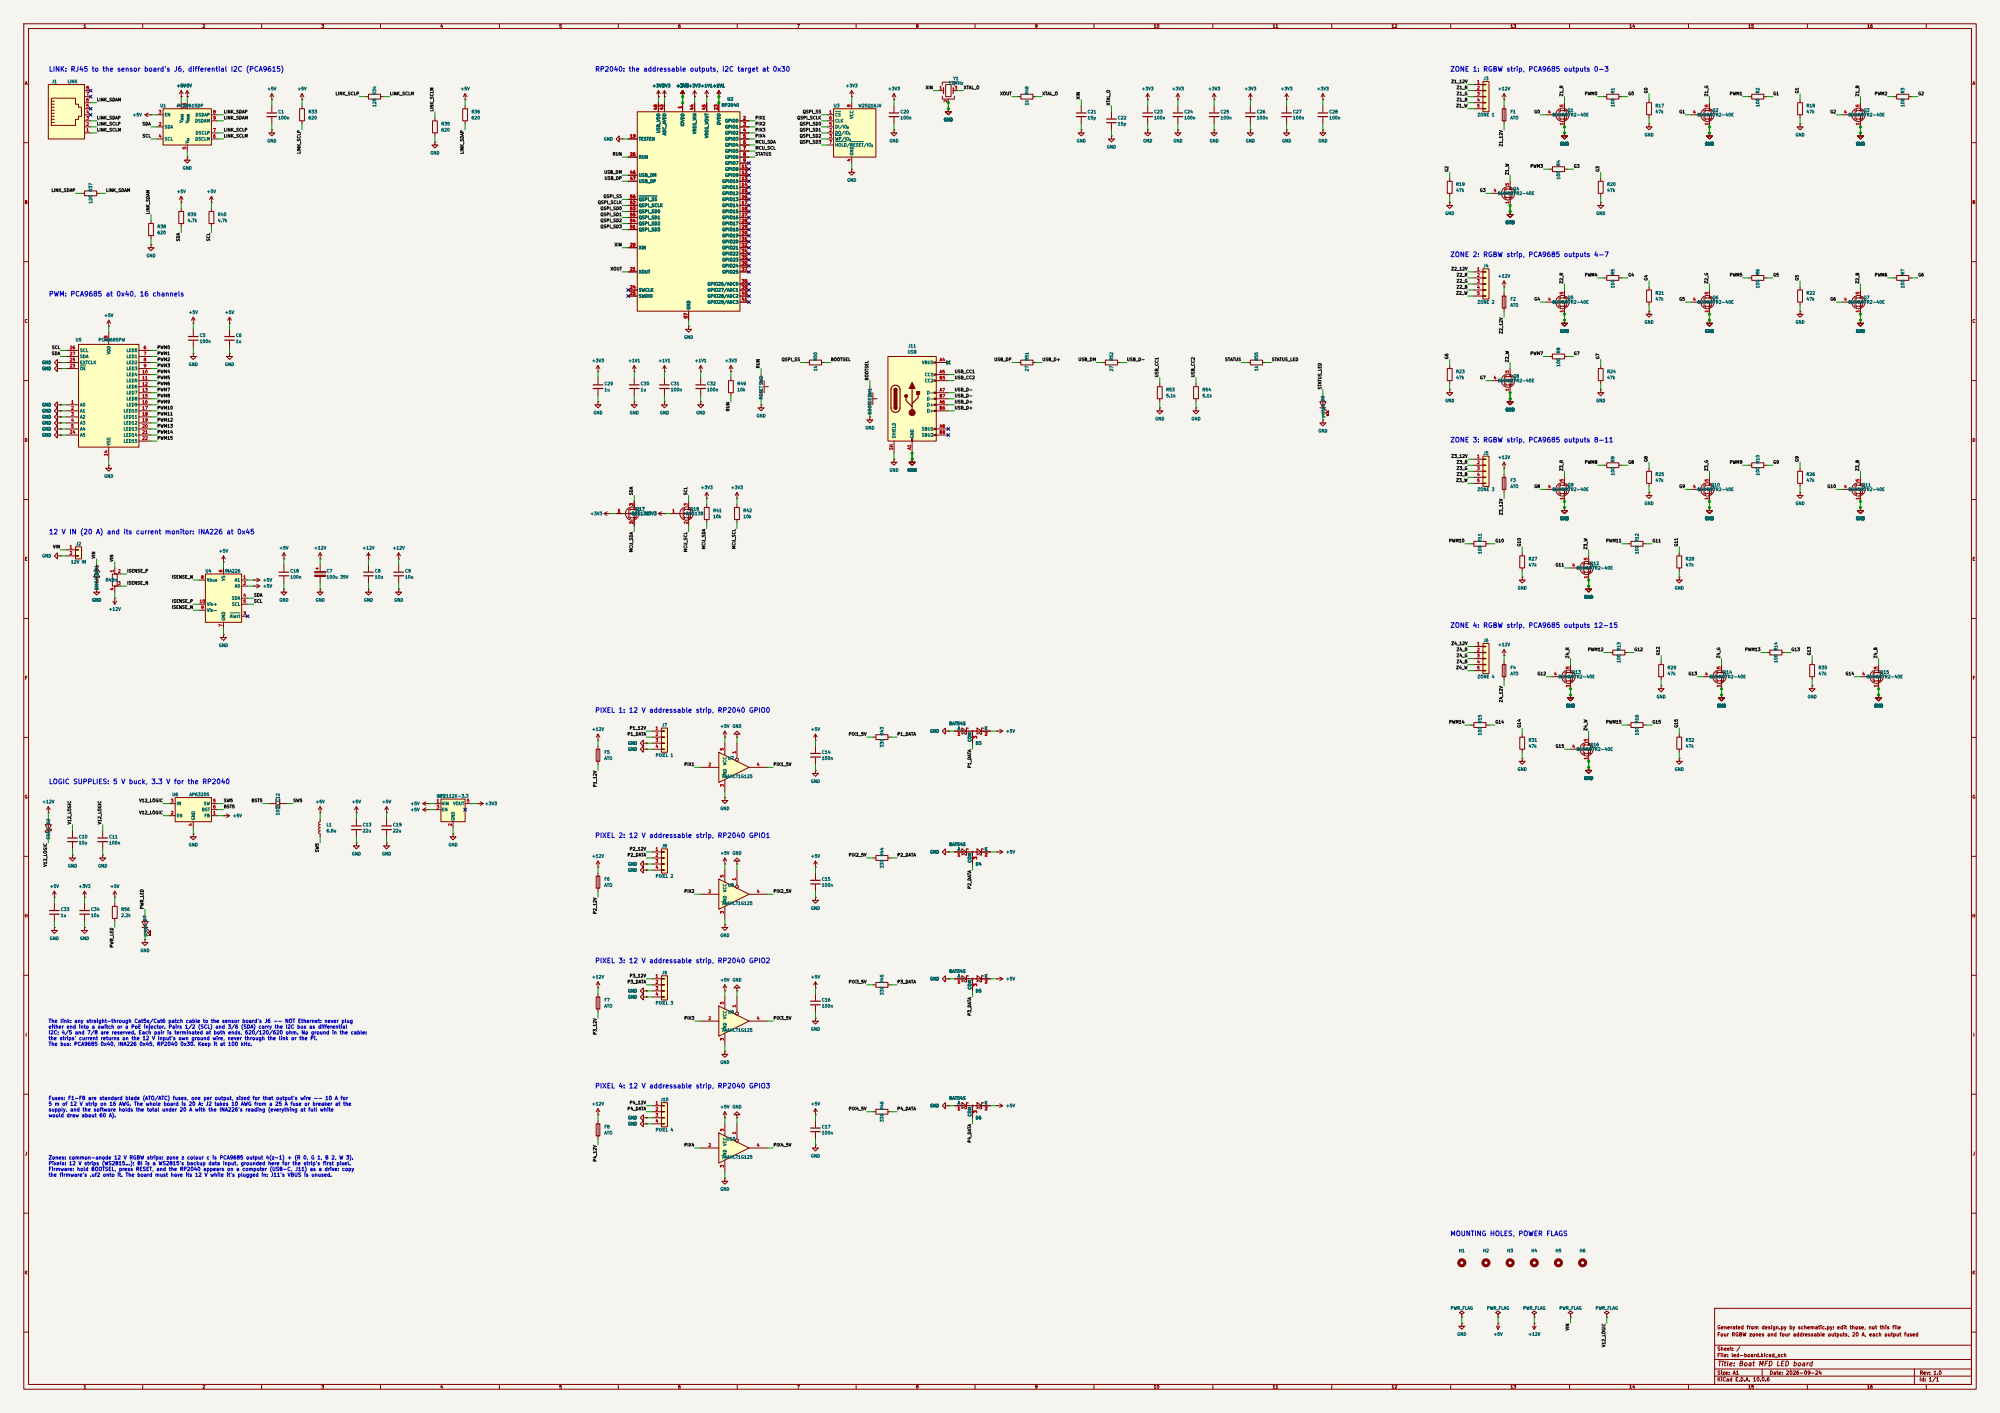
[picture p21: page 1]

LINK: RJ45 to the sensor board's J6, differential I2C (PCA9615)

RP2040: the addressable outputs, I2C target at 0x30

ZONE 1: RGBW strip, PCA9685 outputs 0-3

4 DI/IO0 5 CLK 6 HOLD/RESET/IO3 7 VCC U3 8W25Q16JV C1

VSS 5 DSCLM 6 DSCLP 7 DSDAP 8 DSDAM 9

ZONE 2: RGBW strip, PCA9685 outputs 4-7

ZONE 3: RGBW strip, PCA9685 outputs 8-11

12 V IN (20 A) and its current monitor: INA226 at 0x45

ZONE 4: RGBW strip, PCA9685 outputs 12-15

LOGIC SUPPLIES: 5 V buck, 3.3 V for the RP2040

The link: any straight-through Cat5e/Cat6 patch cable to the sensor board's J6 -- NOT Ethernet: never plug
either end into a switch or a PoE injector. Pairs 1/2 (SCL) and 3/6 (SDA) carry the I2C bus as differential
I2C; 4/5 and 7/8 are reserved. Each pair is terminated at both ends, 620/120/620 ohm. No ground in the cable:
the strips' current returns on the 12 V input's own ground wire, never through the link or the Pi.
The bus: PCA9685 0x40, INA226 0x45, RP2040 0x30. Keep it at 100 kHz.

Fuses: F1-F8 are standard blade (ATO/ATC) fuses, one per output, sized for that output's wire -- 10 A for
5 m of 12 V strip on 16 AWG. The whole board is 20 A: J2 takes 10 AWG from a 25 A fuse or breaker at the
supply, and the software holds the total under 20 A with the INA226's reading (everything at full white
would draw about 60 A).

Zones: common-anode 12 V RGBW strips; zone z colour c is PCA9685 output 4(z-1) + (R 0, G 1, B 2, W 3).
Pixels: 12 V strips (WS2815...); BI is a WS2815's backup data input, grounded here for the strip's first pixel.
Firmware: hold BOOTSEL, press RESET, and the RP2040 appears on a computer (USB-C, J11) as a drive: copy
the firmware's .uf2 onto it. The board must have its 12 V while it's plugged in: J11's VBUS is unused.

MOUNTING HOLES, POWER FLAGS

Generated from design.py by schematic.py; edit those, not this file
Four RGBW zones and four addressable outputs, 20 A, each output fused

Sheet: /
File: led-board.kicad_sch
Title: Boat MFD LED board

Size: A1 | Rev: 1.0
KiCad E.D.A. 10.0.6 | Id: 1/1

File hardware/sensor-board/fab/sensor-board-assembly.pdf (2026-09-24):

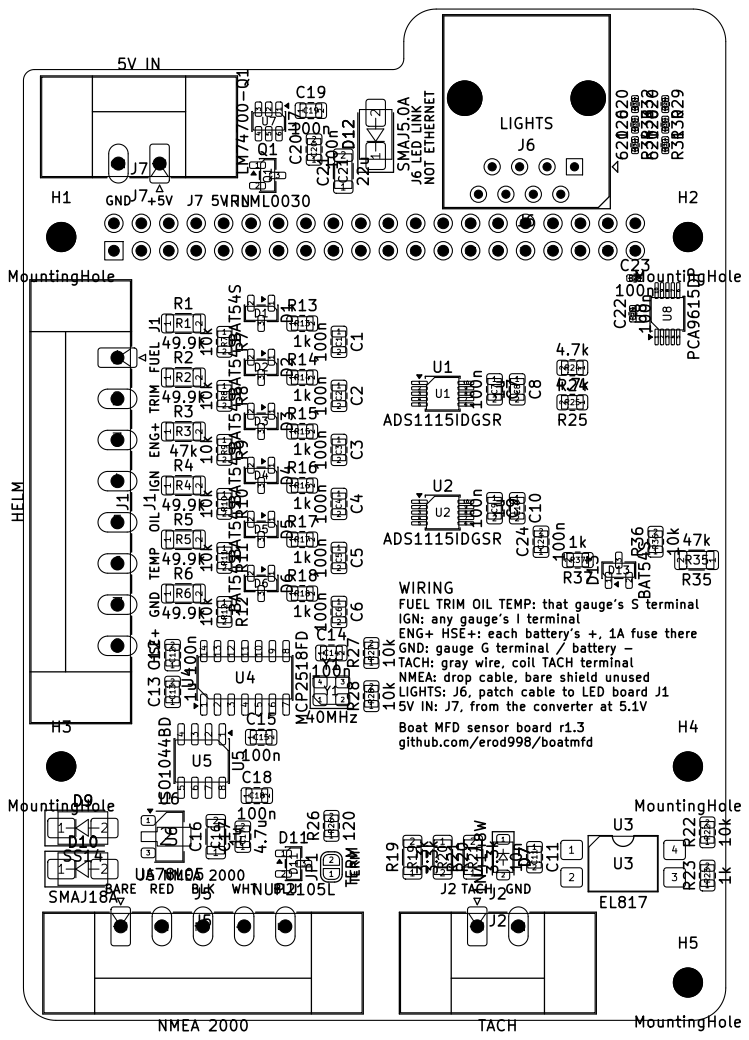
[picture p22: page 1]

github.com/erod998/boatmfd GND

40 FUEL TRIM OIL TEMP: that gauge's S terminal

IGN: any gauge's I terminal ENG+ HSE+: each battery's +, 1A fuse there GND: gauge G terminal / battery -

TACH: gray wire, coil TACH terminal NMEA: drop cable, bare shield unused

LIGHTS: J6, patch cable to LED board J1
5V IN: J7, from the converter at 5.1V Boat MFD sensor board r1.3

Generated from design.py by board.py; edit those, not this file
Passive taps on the existing gauges; Delco EST tach; isolated NMEA 2000

Sheet:
File: sensor-board.kicad_pcb
Title: Boat MFD sensor board

Size: A4 | Rev: 1.3
KiCad E.D.A. 10.0.6 | Id: 1/1

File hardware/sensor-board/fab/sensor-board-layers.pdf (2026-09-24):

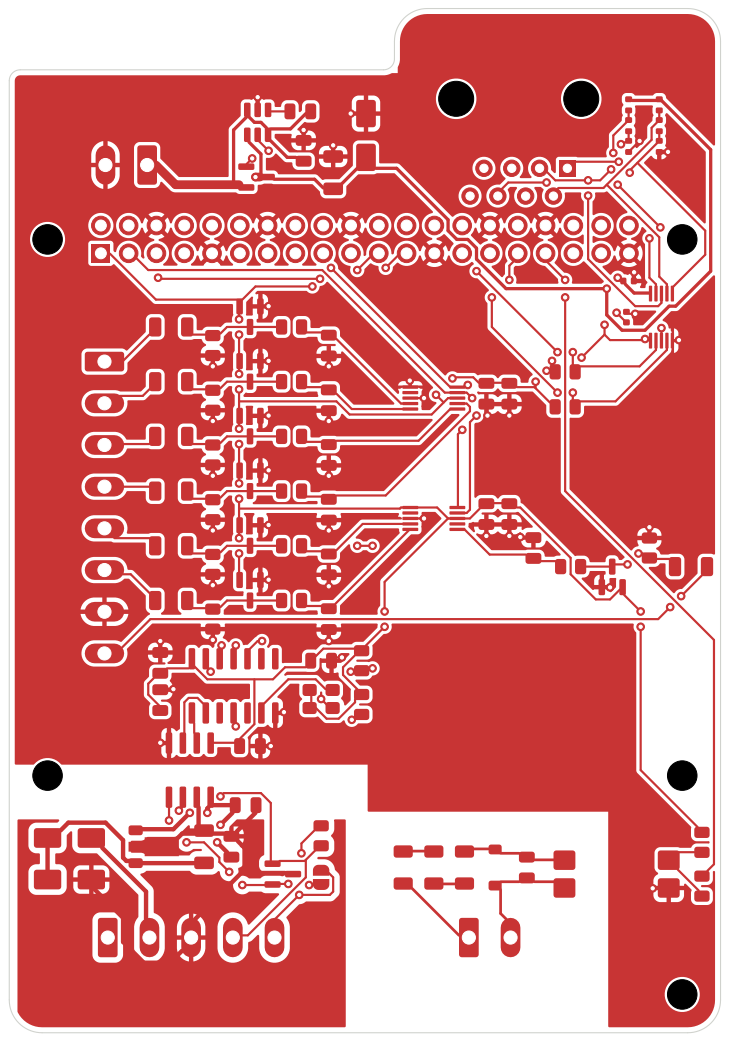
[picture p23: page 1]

Generated from design.py by board.py; edit those, not this file
Passive taps on the existing gauges; Delco EST tach; isolated NMEA 2000

Sheet:
File: sensor-board.kicad_pcb
Title: Boat MFD sensor board

Size: A4 | Rev: 1.3
KiCad E.D.A. 10.0.6 | Id: 1/4

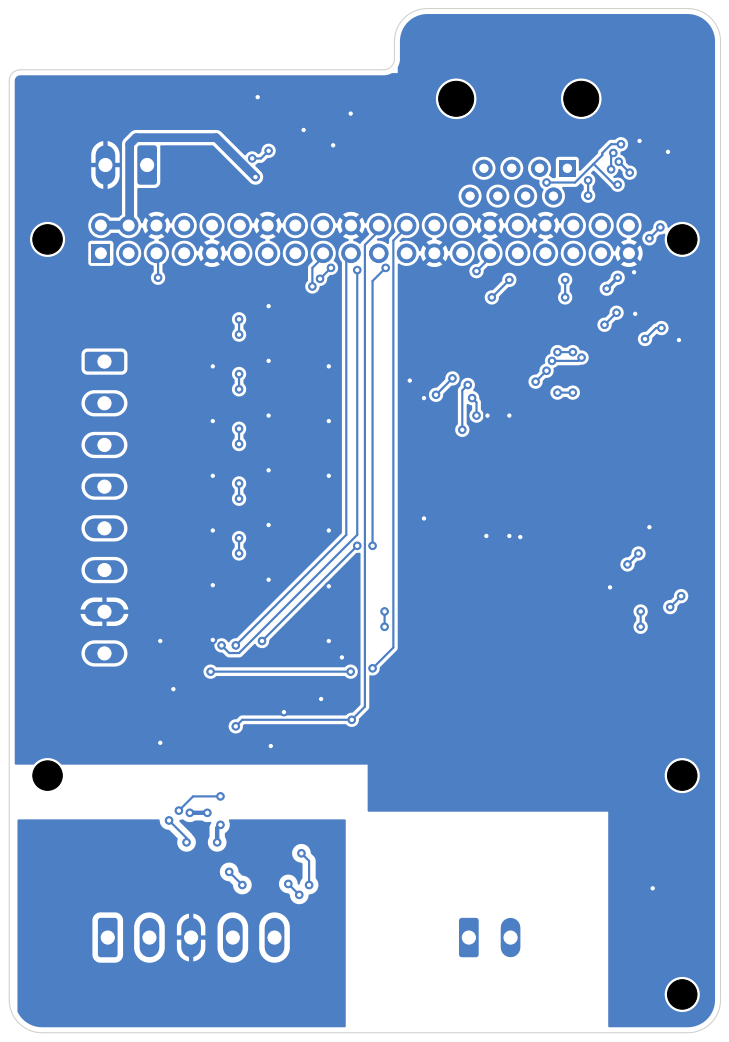
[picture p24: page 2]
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

Sheet:
File: sensor-board.kicad_pcb
Title: Boat MFD sensor board

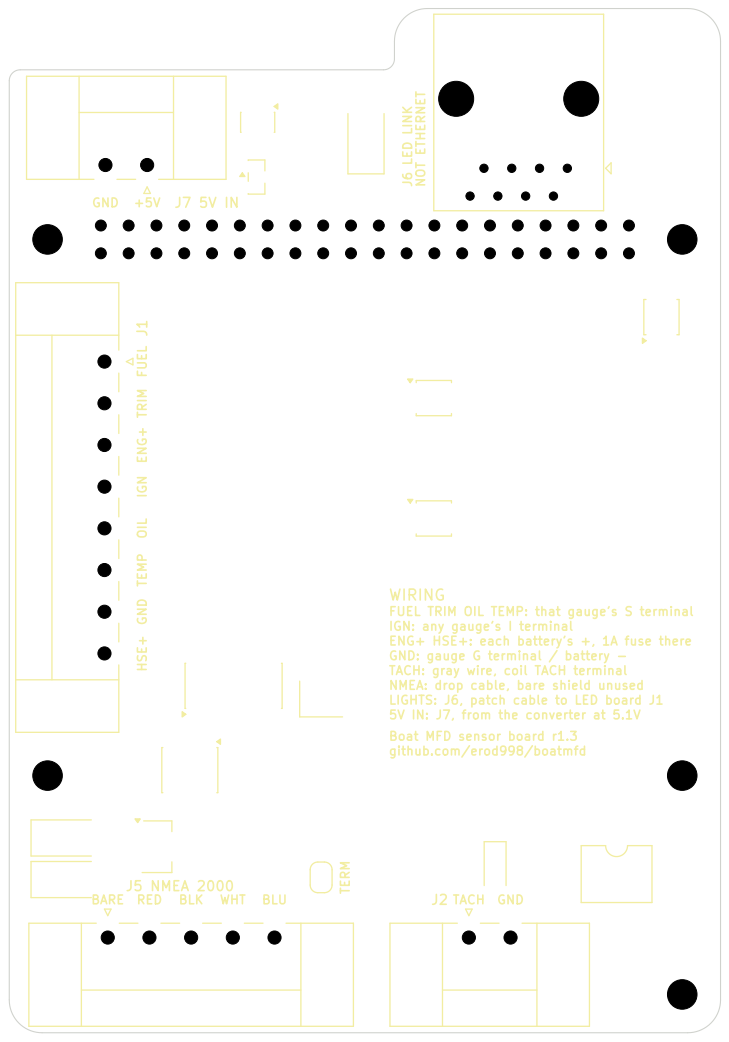
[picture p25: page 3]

github.com/erod998/boatmfd GND

FUEL TRIM OIL TEMP: that gauge's S terminal
IGN: any gauge's I terminal ENG+ HSE+: each battery's +, 1A fuse there GND: gauge G terminal / battery -

TACH: gray wire, coil TACH terminal NMEA: drop cable, bare shield unused

LIGHTS: J6, patch cable to LED board J1
5V IN: J7, from the converter at 5.1V Boat MFD sensor board r1.3

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

Sheet:
File: sensor-board.kicad_pcb
Title: Boat MFD sensor board

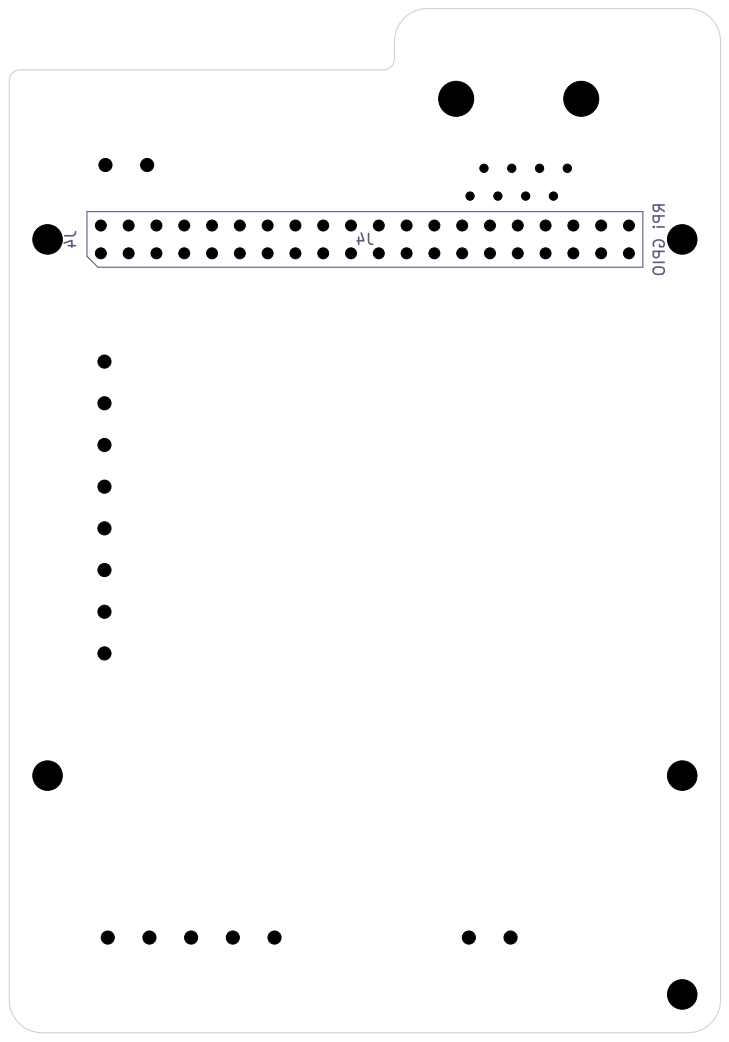
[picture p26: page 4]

Passive taps on the existing gauges; Delco EST tach; isolated NMEA 2000

Sheet:
File: sensor-board.kicad_pcb
Title: Boat MFD sensor board

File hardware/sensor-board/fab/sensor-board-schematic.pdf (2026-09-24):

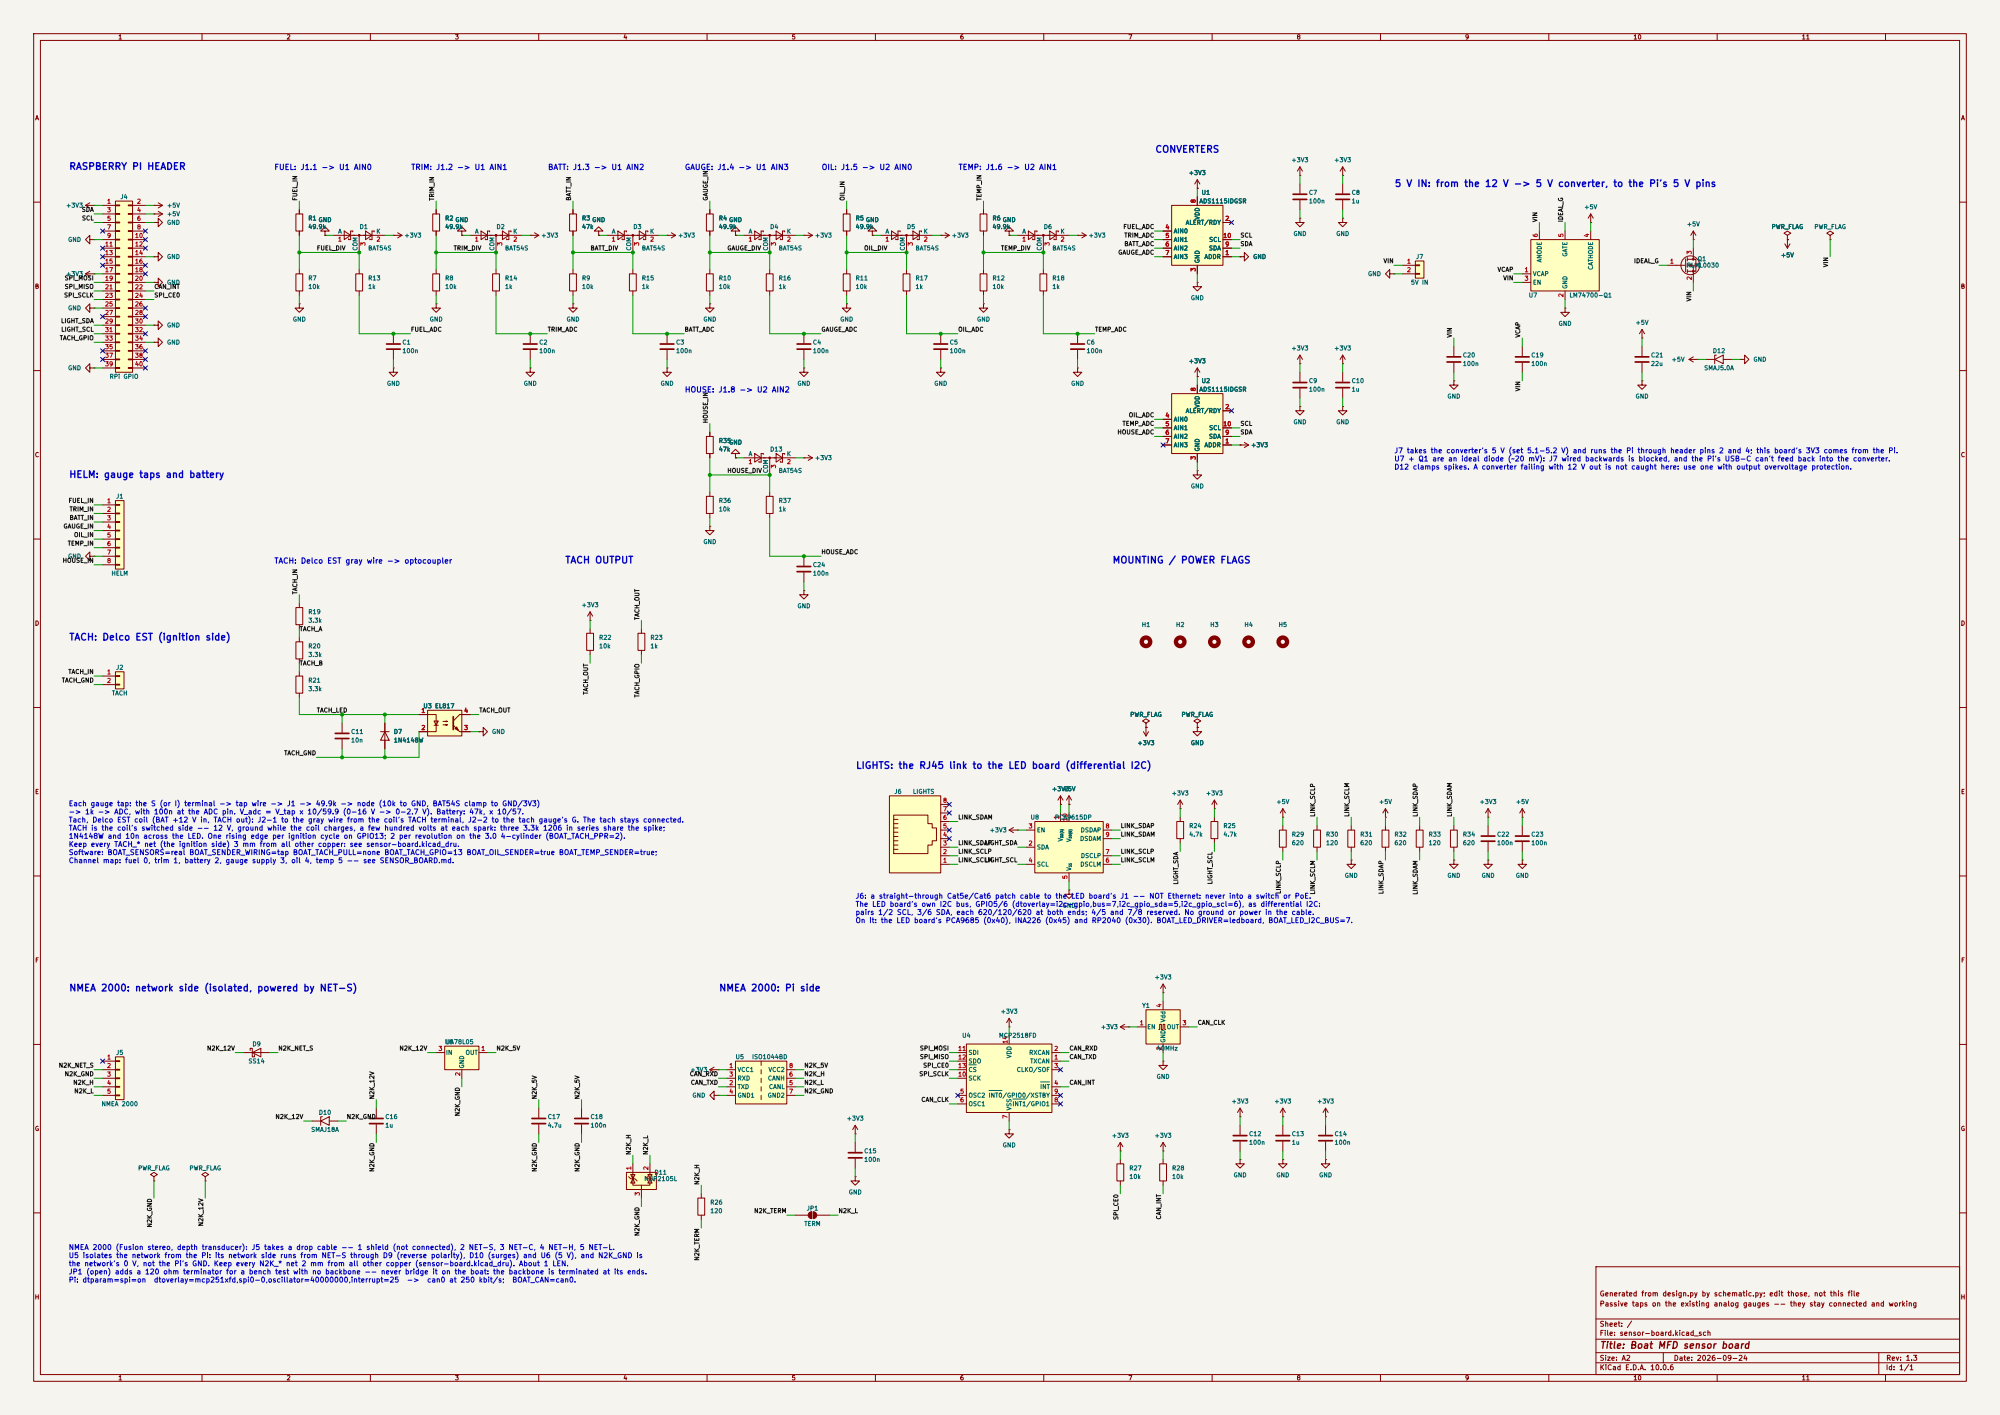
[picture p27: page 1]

5 V IN: from the 12 V -> 5 V converter, to the Pi's 5 V pins

J7 takes the converter's 5 V (set 5.1-5.2 V) and runs the Pi through header pins 2 and 4; this board's 3V3 comes from the Pi.
U7 + Q1 are an ideal diode (~20 mV): J7 wired backwards is blocked, and the Pi's USB-C can't feed back into the converter.
D12 clamps spikes. A converter failing with 12 V out is not caught here: use one with output overvoltage protection.

TACH: Delco EST gray wire -> optocoupler

TACH: Delco EST (ignition side)

LIGHTS: the RJ45 link to the LED board (differential I2C)

Each gauge tap: the S (or I) terminal -> tap wire -> J1 -> 49.9k -> node (10k to GND, BAT54S clamp to GND/3V3) -> 1k -> ADC, with 100n at the ADC pin. V_adc = V_tap x 10/59.9 (0-16 V -> 0-2.7 V). Battery: 47k, x 10/57.

Tach, Delco EST coil (BAT +12 V in, TACH out): J2-1 to the gray wire from the coil's TACH terminal, J2-2 to the tach gauge's G. The tach stays connected.
TACH is the coil's switched side -- 12 V, ground while the coil charges, a few hundred volts at each spark: three 3.3k 1206 in series share the spike;
1N4148W and 10n across the LED. One rising edge per ignition cycle on GPIO13; 2 per revolution on the 3.0 4-cylinder (BOAT_TACH_PPR=2).
Keep every TACH_* net (the ignition side) 3 mm from all other copper: see sensor-board.kicad_dru.
Software: BOAT_SENSORS=real BOAT_SENDER_WIRING=tap BOAT_TACH_PULL=none BOAT_TACH_GPIO=13 BOAT_OIL_SENDER=true BOAT_TEMP_SENDER=true;
Channel map: fuel 0, trim 1, battery 2, gauge supply 3, oil 4, temp 5 -- see SENSOR_BOARD.md.

VSS 5 DSCLM 6 DSCLP 7 DSDAP 8 DSDAM 9

J6: a straight-through Cat5e/Cat6 patch cable to the LED board's J1 -- NOT Ethernet: never into a switch or PoE.
The LED board's own I2C bus, GPIO5/6 (dtoverlay=i2c-gpio,bus=7,i2c_gpio_sda=5,i2c_gpio_scl=6), as differential I2C:
pairs 1/2 SCL, 3/6 SDA, each 620/120/620 at both ends; 4/5 and 7/8 reserved. No ground or power in the cable.
On it: the LED board's PCA9685 (0x40), INA226 (0x45) and RP2040 (0x30). BOAT_LED_DRIVER=ledboard, BOAT_LED_I2C_BUS=7.

NMEA 2000: network side (isolated, powered by NET-S)

NMEA 2000 (Fusion stereo, depth transducer): J5 takes a drop cable -- 1 shield (not connected), 2 NET-S, 3 NET-C, 4 NET-H, 5 NET-L.
U5 isolates the network from the Pi: its network side runs from NET-S through D9 (reverse polarity), D10 (surges) and U6 (5 V), and N2K_GND is
the network's 0 V, not the Pi's GND. Keep every N2K_* net 2 mm from all other copper (sensor-board.kicad_dru). About 1 LEN.
JP1 (open) adds a 120 ohm terminator for a bench test with no backbone -- never bridge it on the boat: the backbone is terminated at its ends.
Pi: dtparam=spi=on dtoverlay=mcp251xfd,spi0-0,oscillator=40000000,interrupt=25 -> can0 at 250 kbit/s; BOAT_CAN=can0.

Generated from design.py by schematic.py; edit those, not this file
Passive taps on the existing analog gauges -- they stay connected and working

Sheet: /
File: sensor-board.kicad_sch
Title: Boat MFD sensor board

Size: A2 | Rev: 1.3
KiCad E.D.A. 10.0.6 | Id: 1/1

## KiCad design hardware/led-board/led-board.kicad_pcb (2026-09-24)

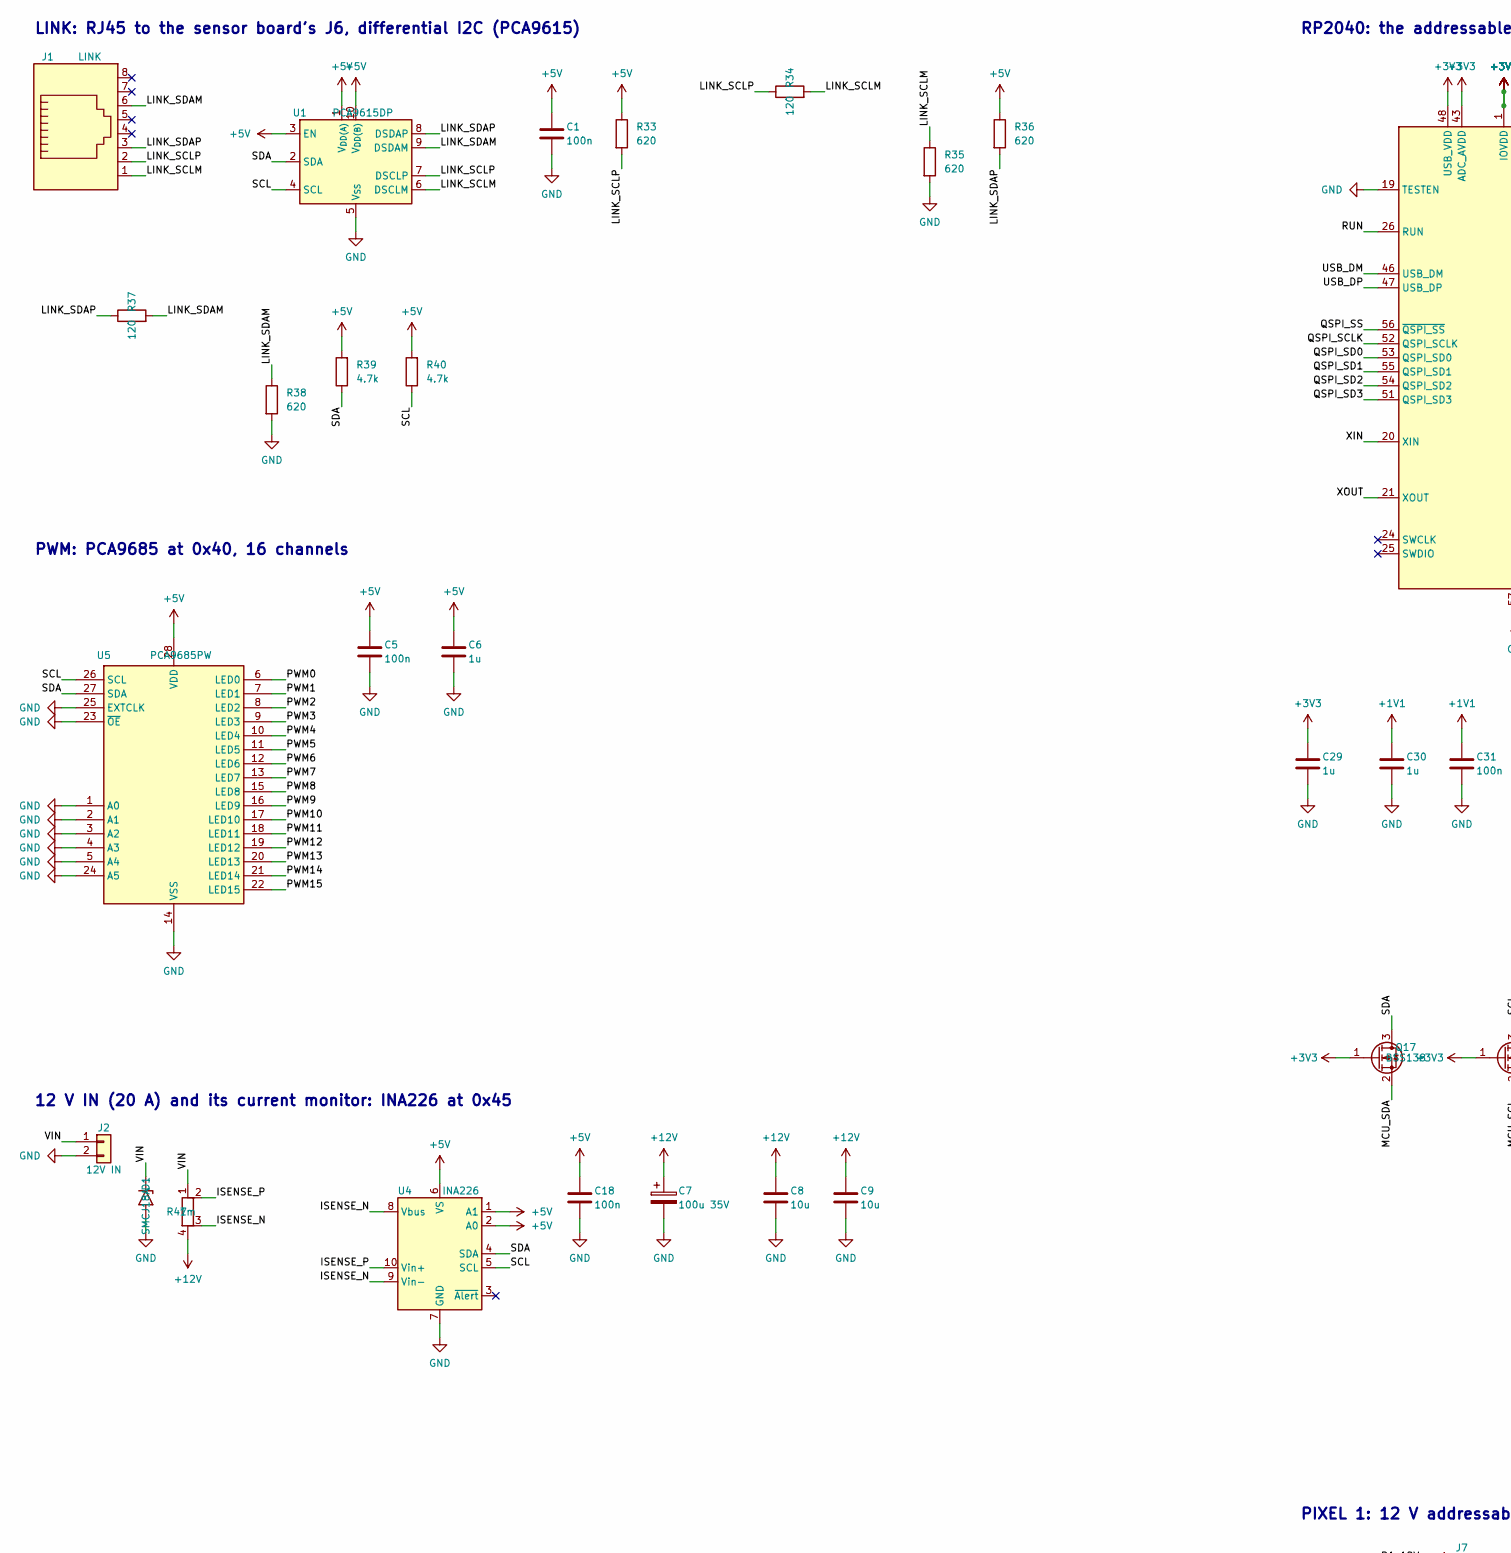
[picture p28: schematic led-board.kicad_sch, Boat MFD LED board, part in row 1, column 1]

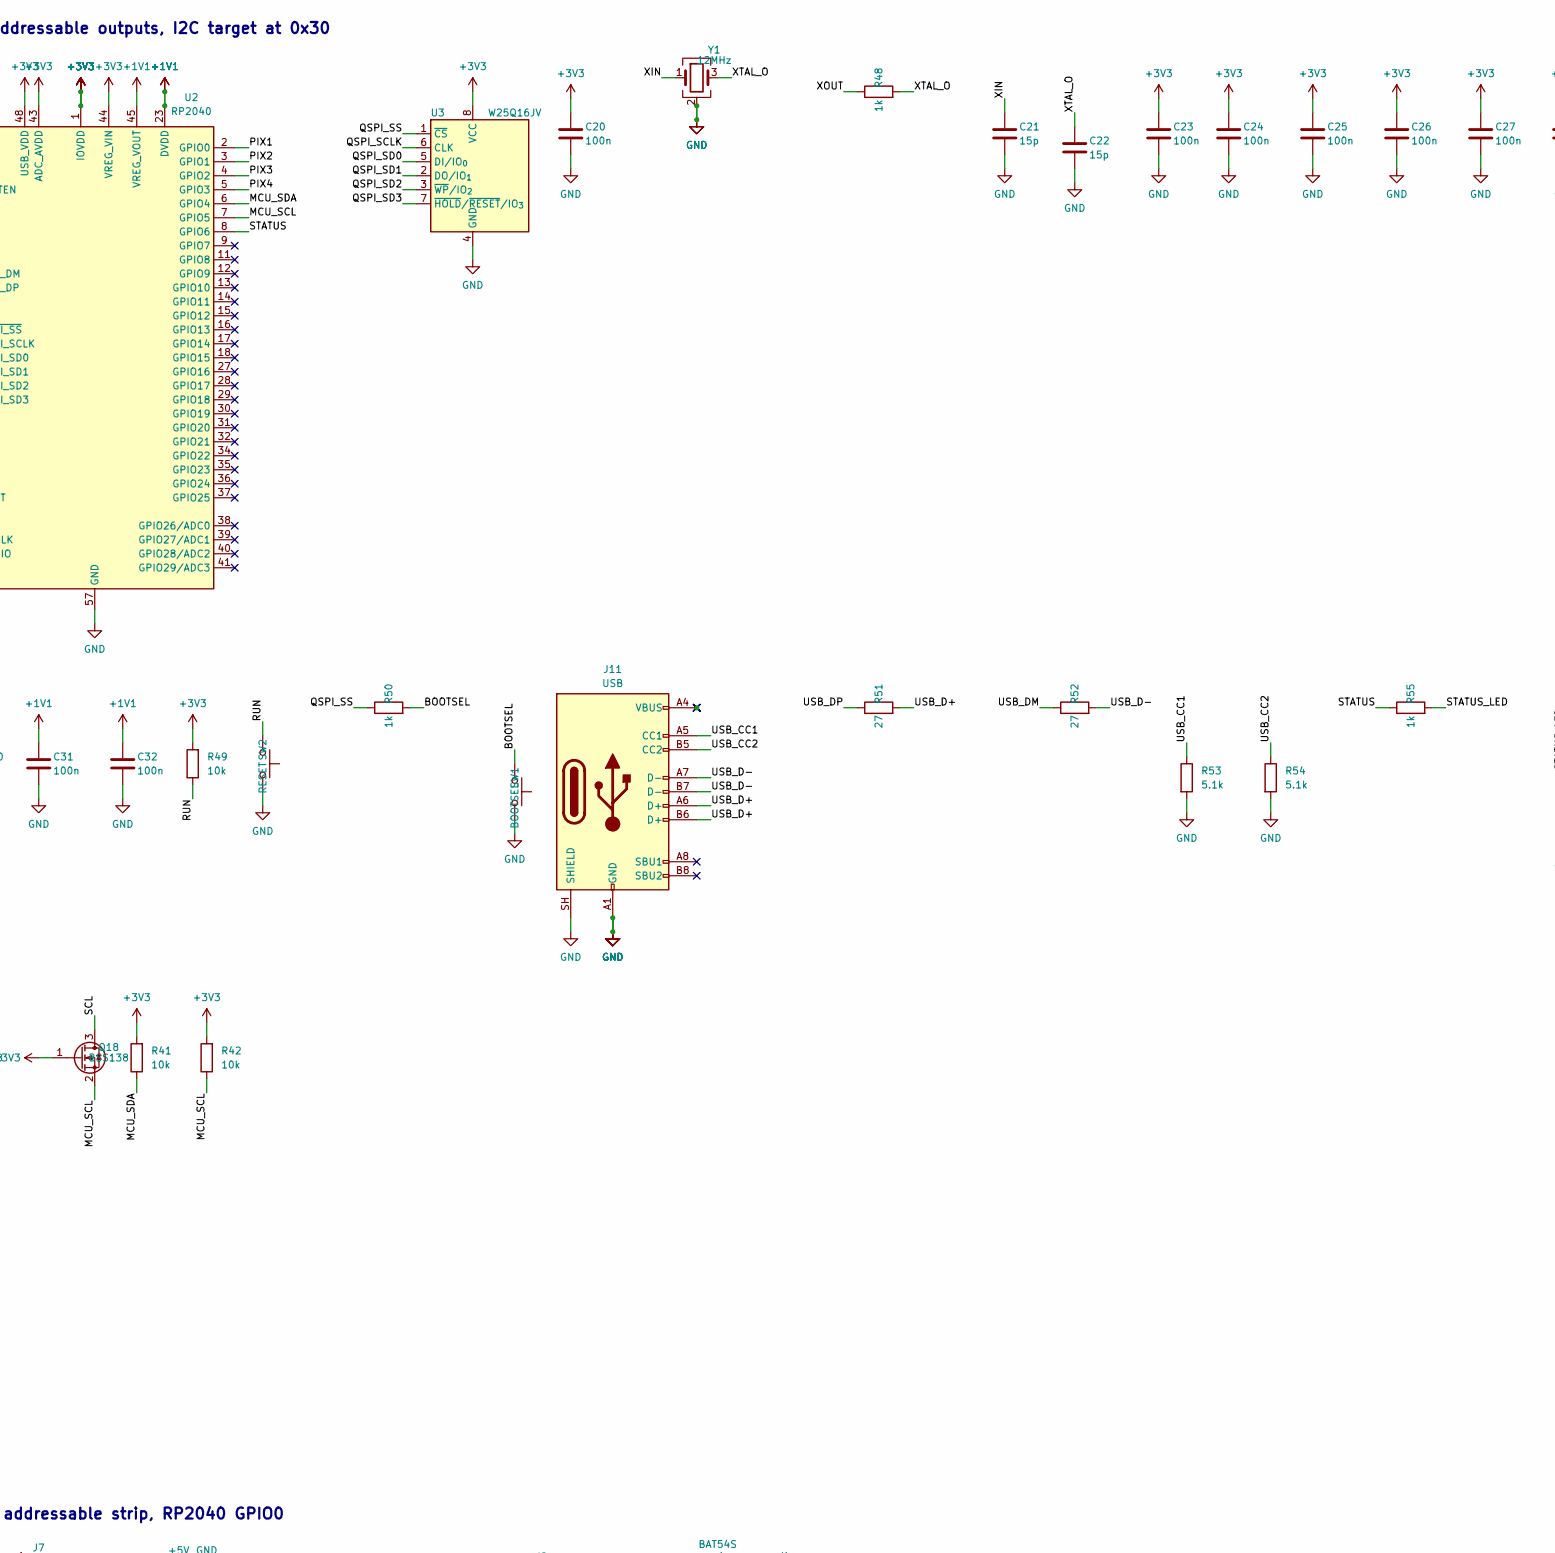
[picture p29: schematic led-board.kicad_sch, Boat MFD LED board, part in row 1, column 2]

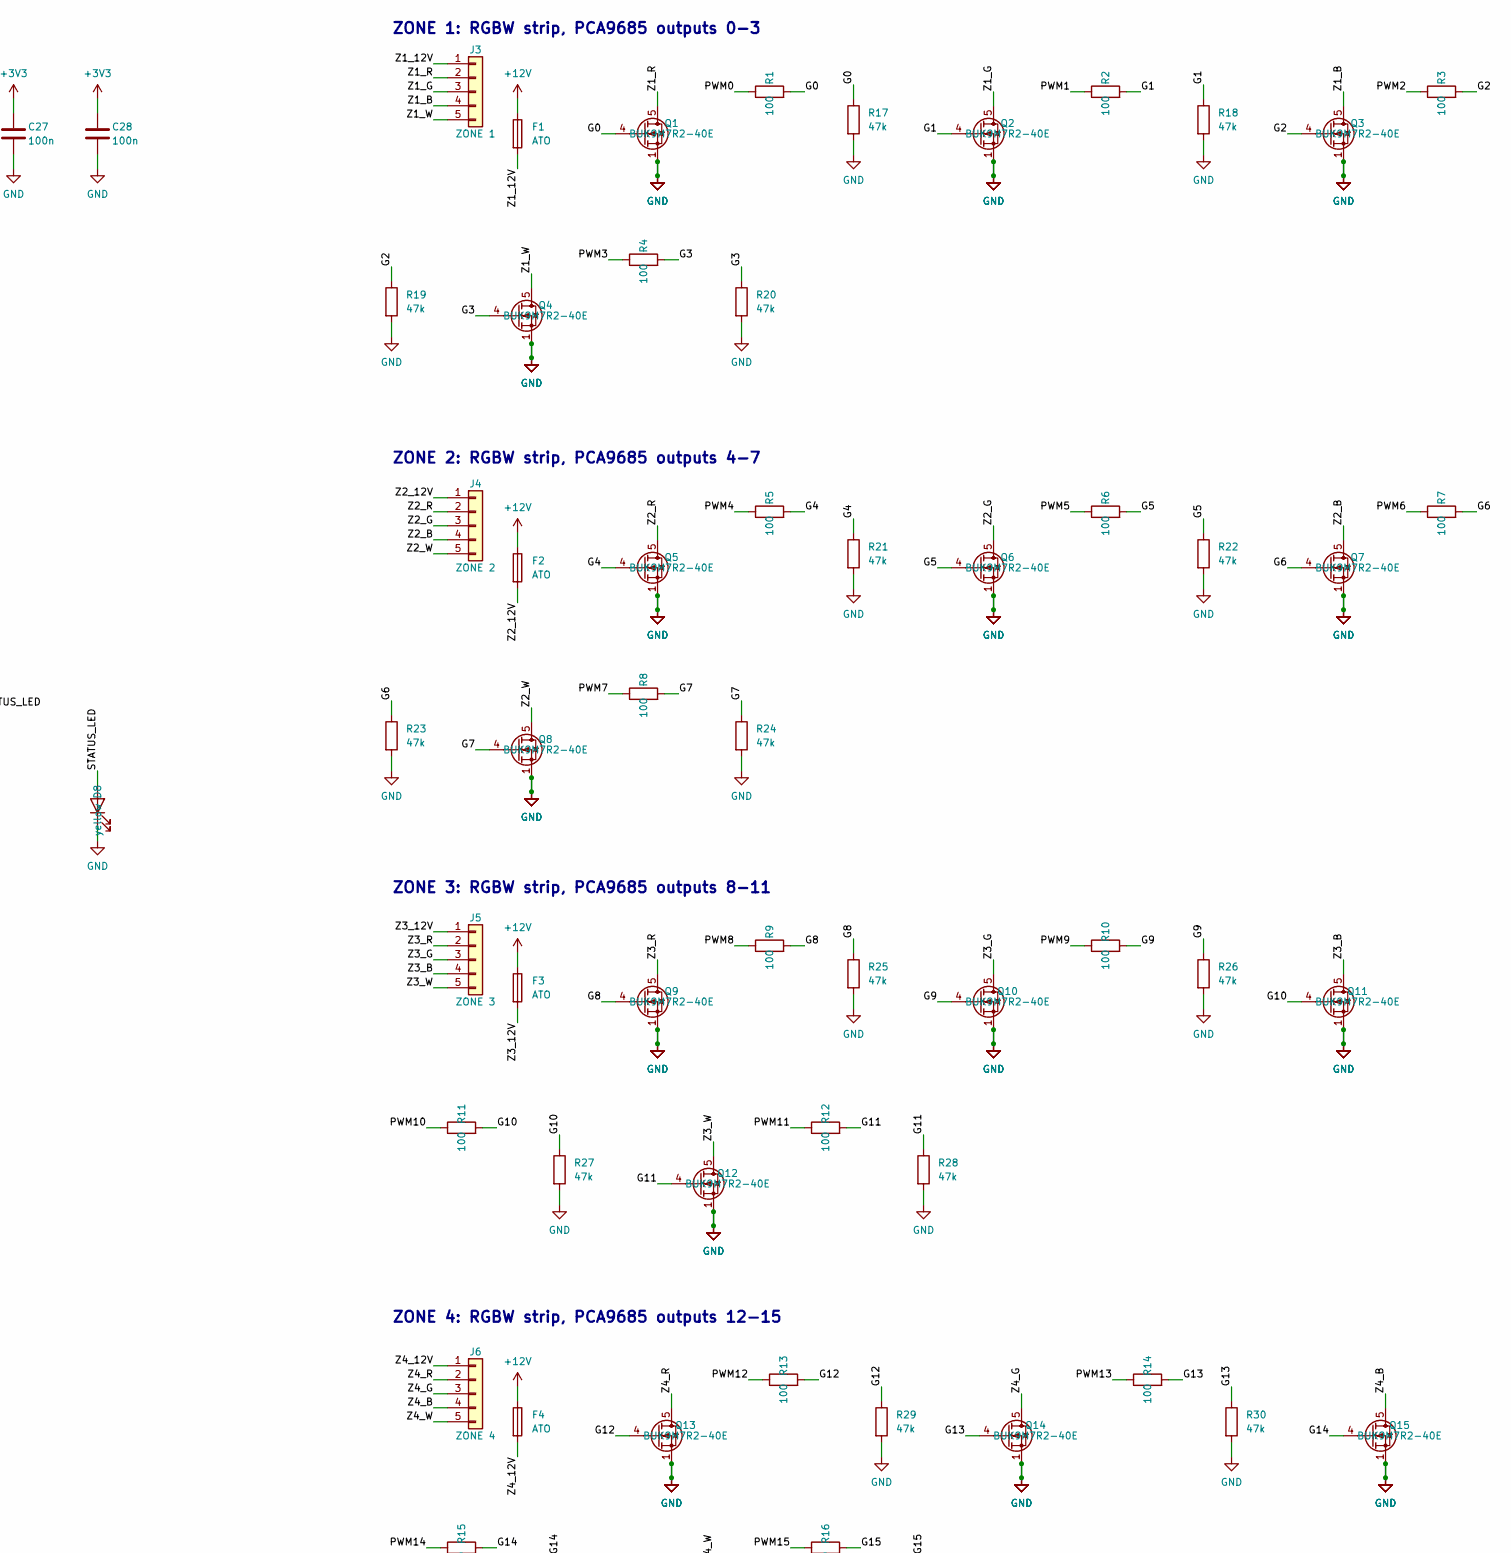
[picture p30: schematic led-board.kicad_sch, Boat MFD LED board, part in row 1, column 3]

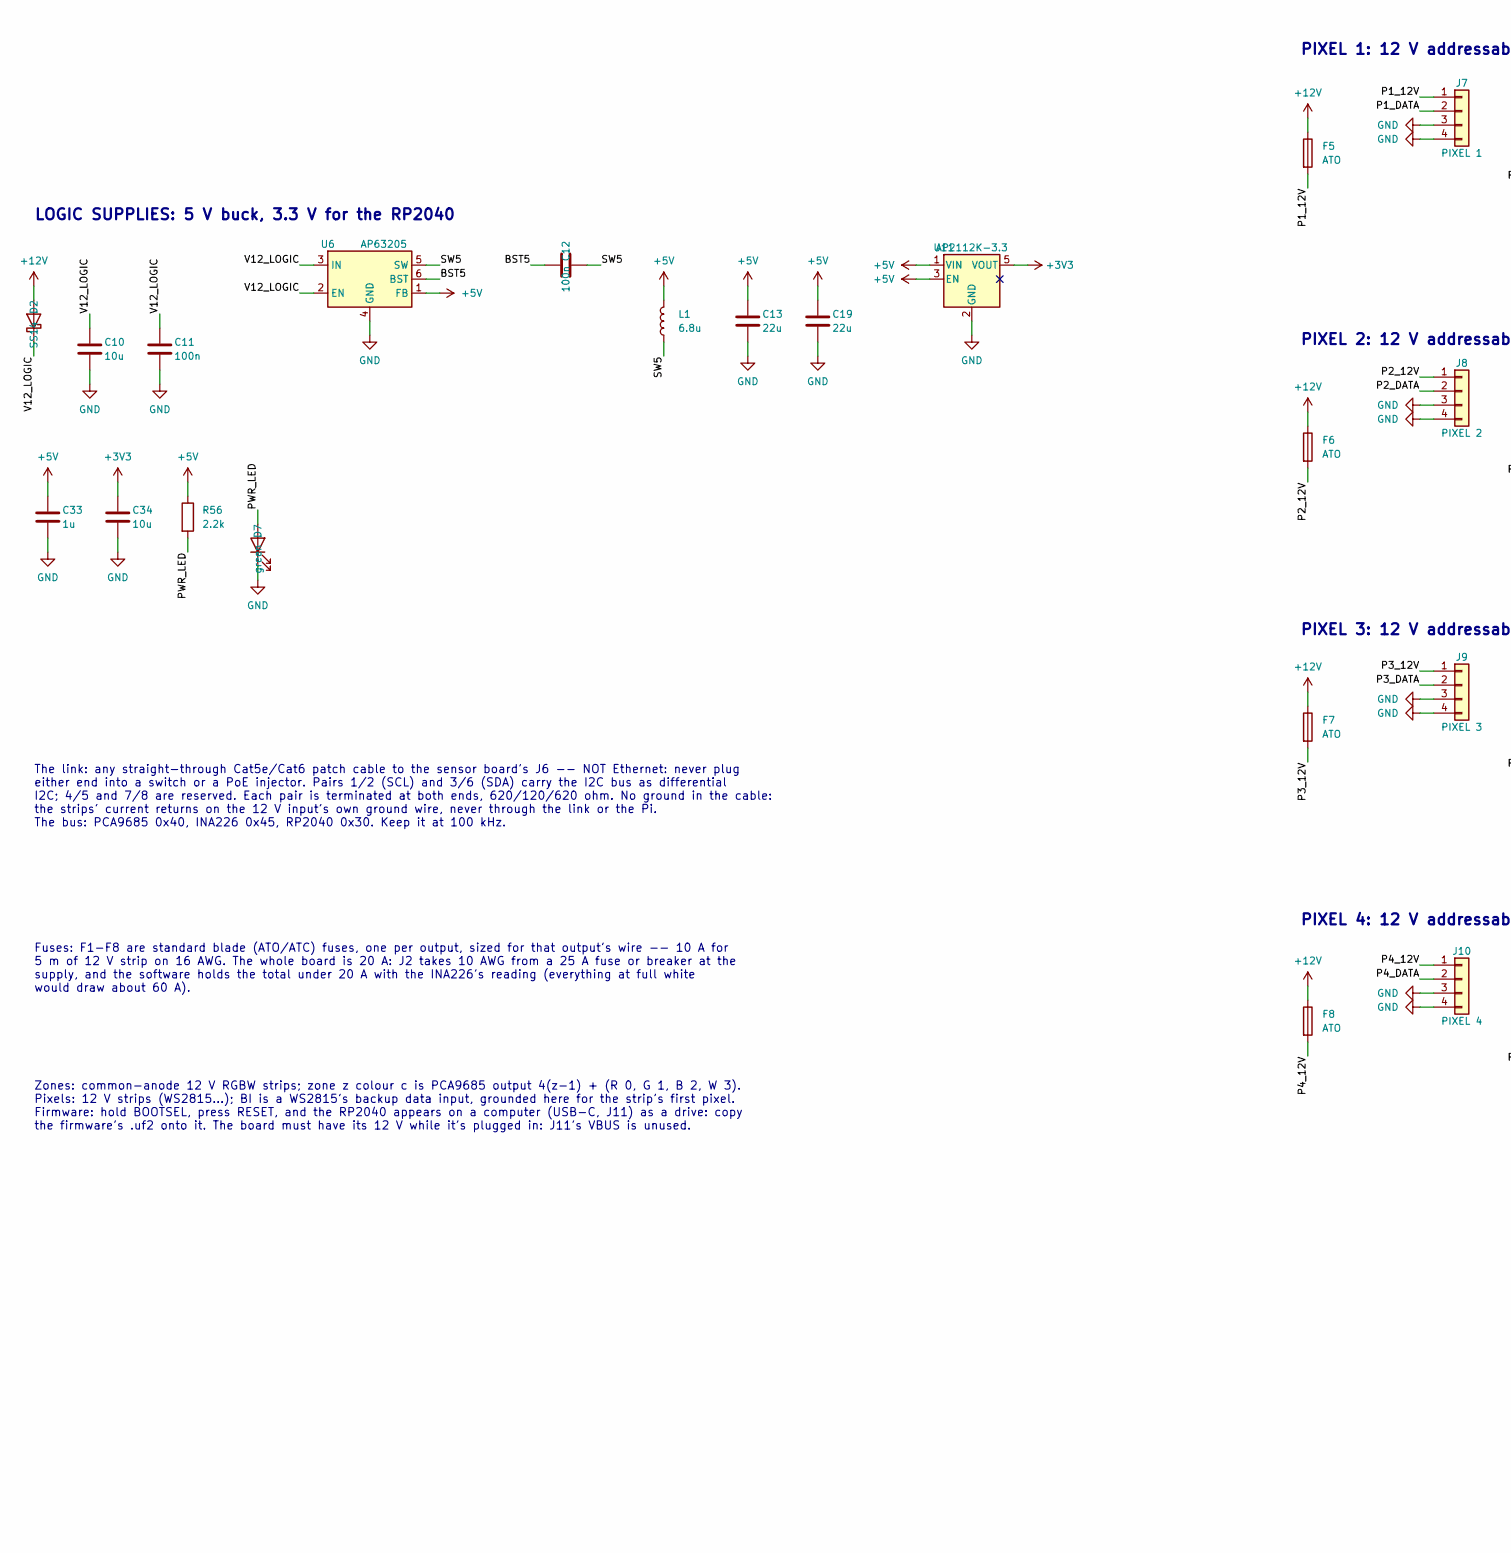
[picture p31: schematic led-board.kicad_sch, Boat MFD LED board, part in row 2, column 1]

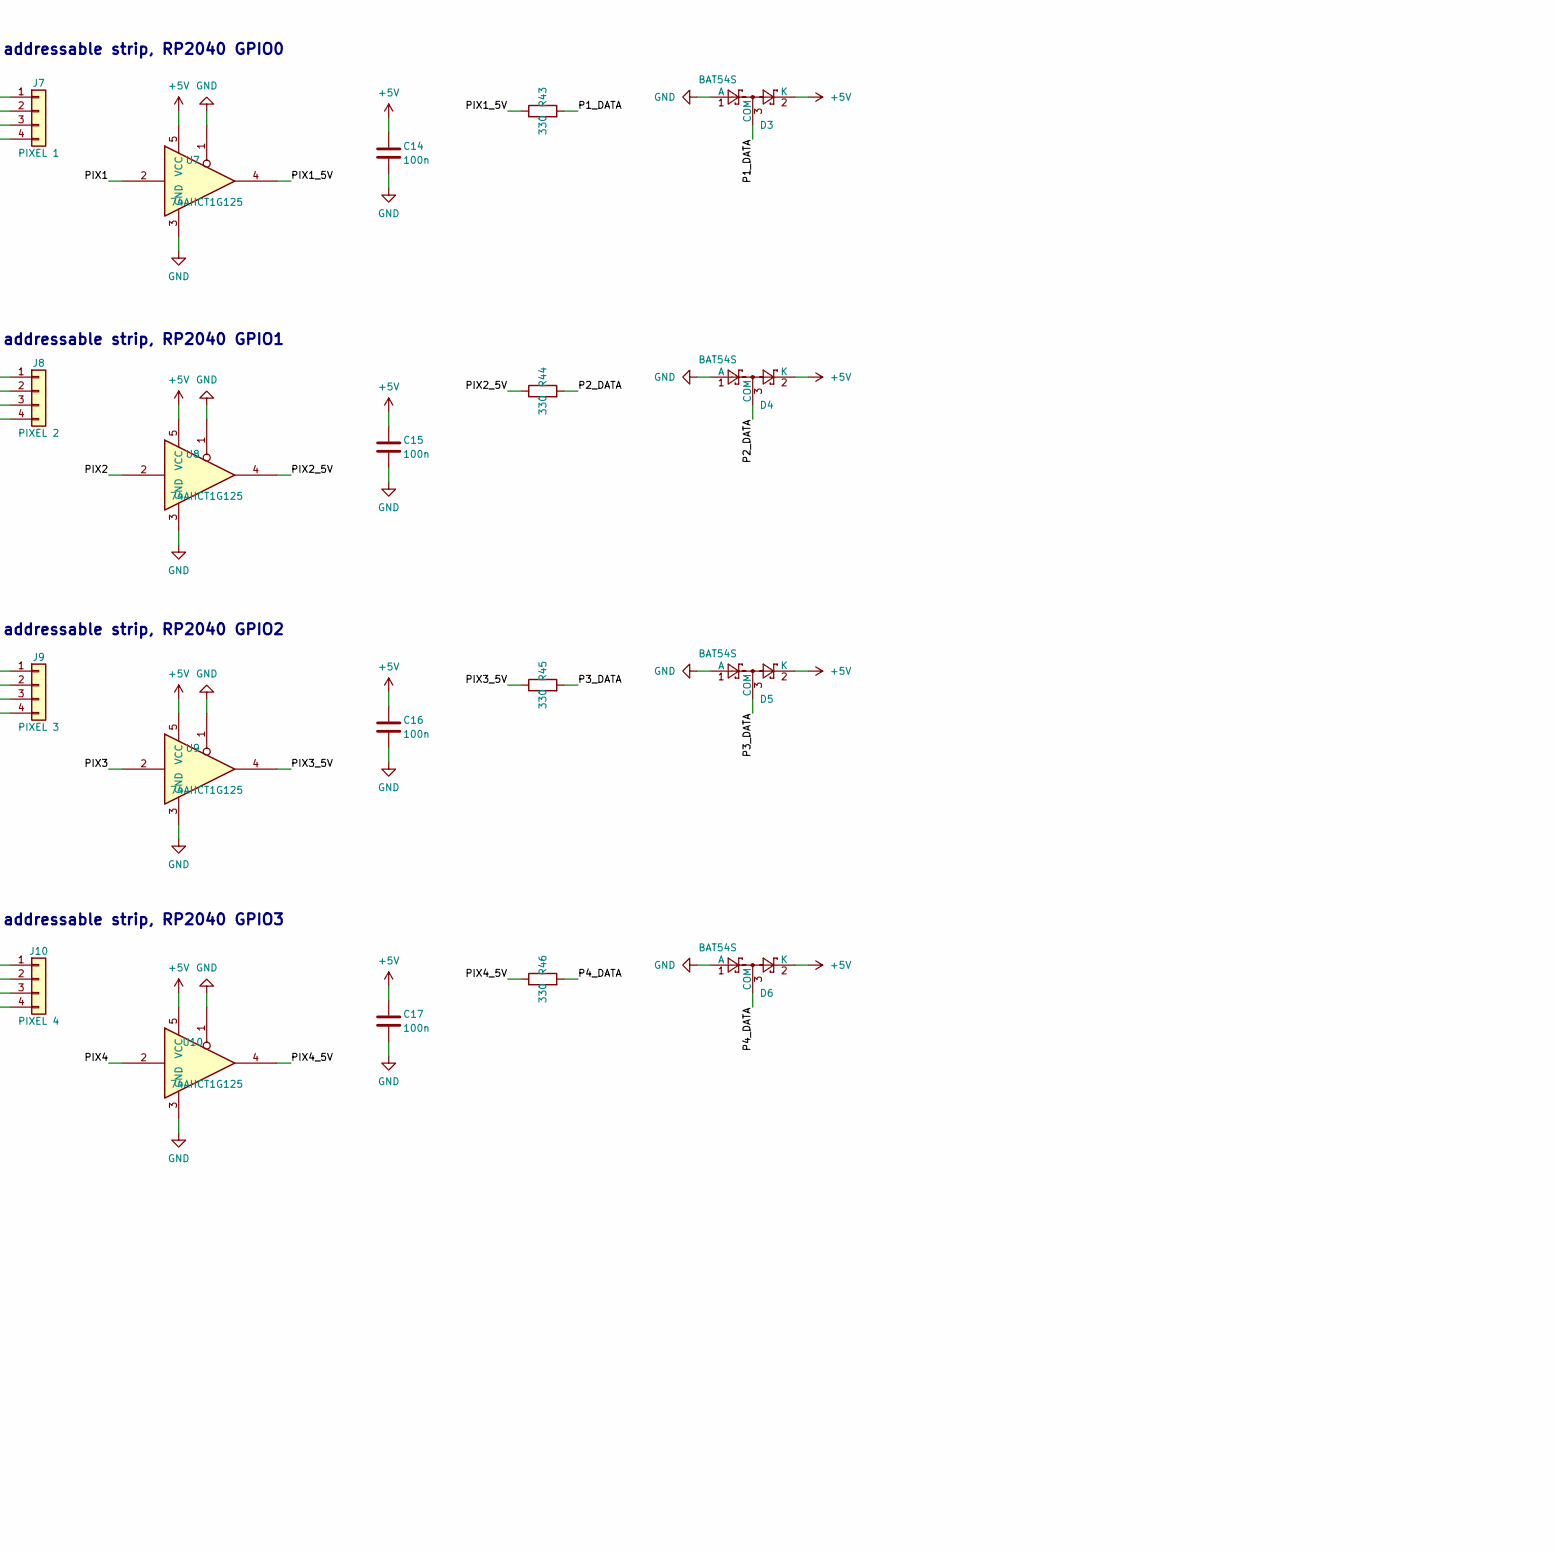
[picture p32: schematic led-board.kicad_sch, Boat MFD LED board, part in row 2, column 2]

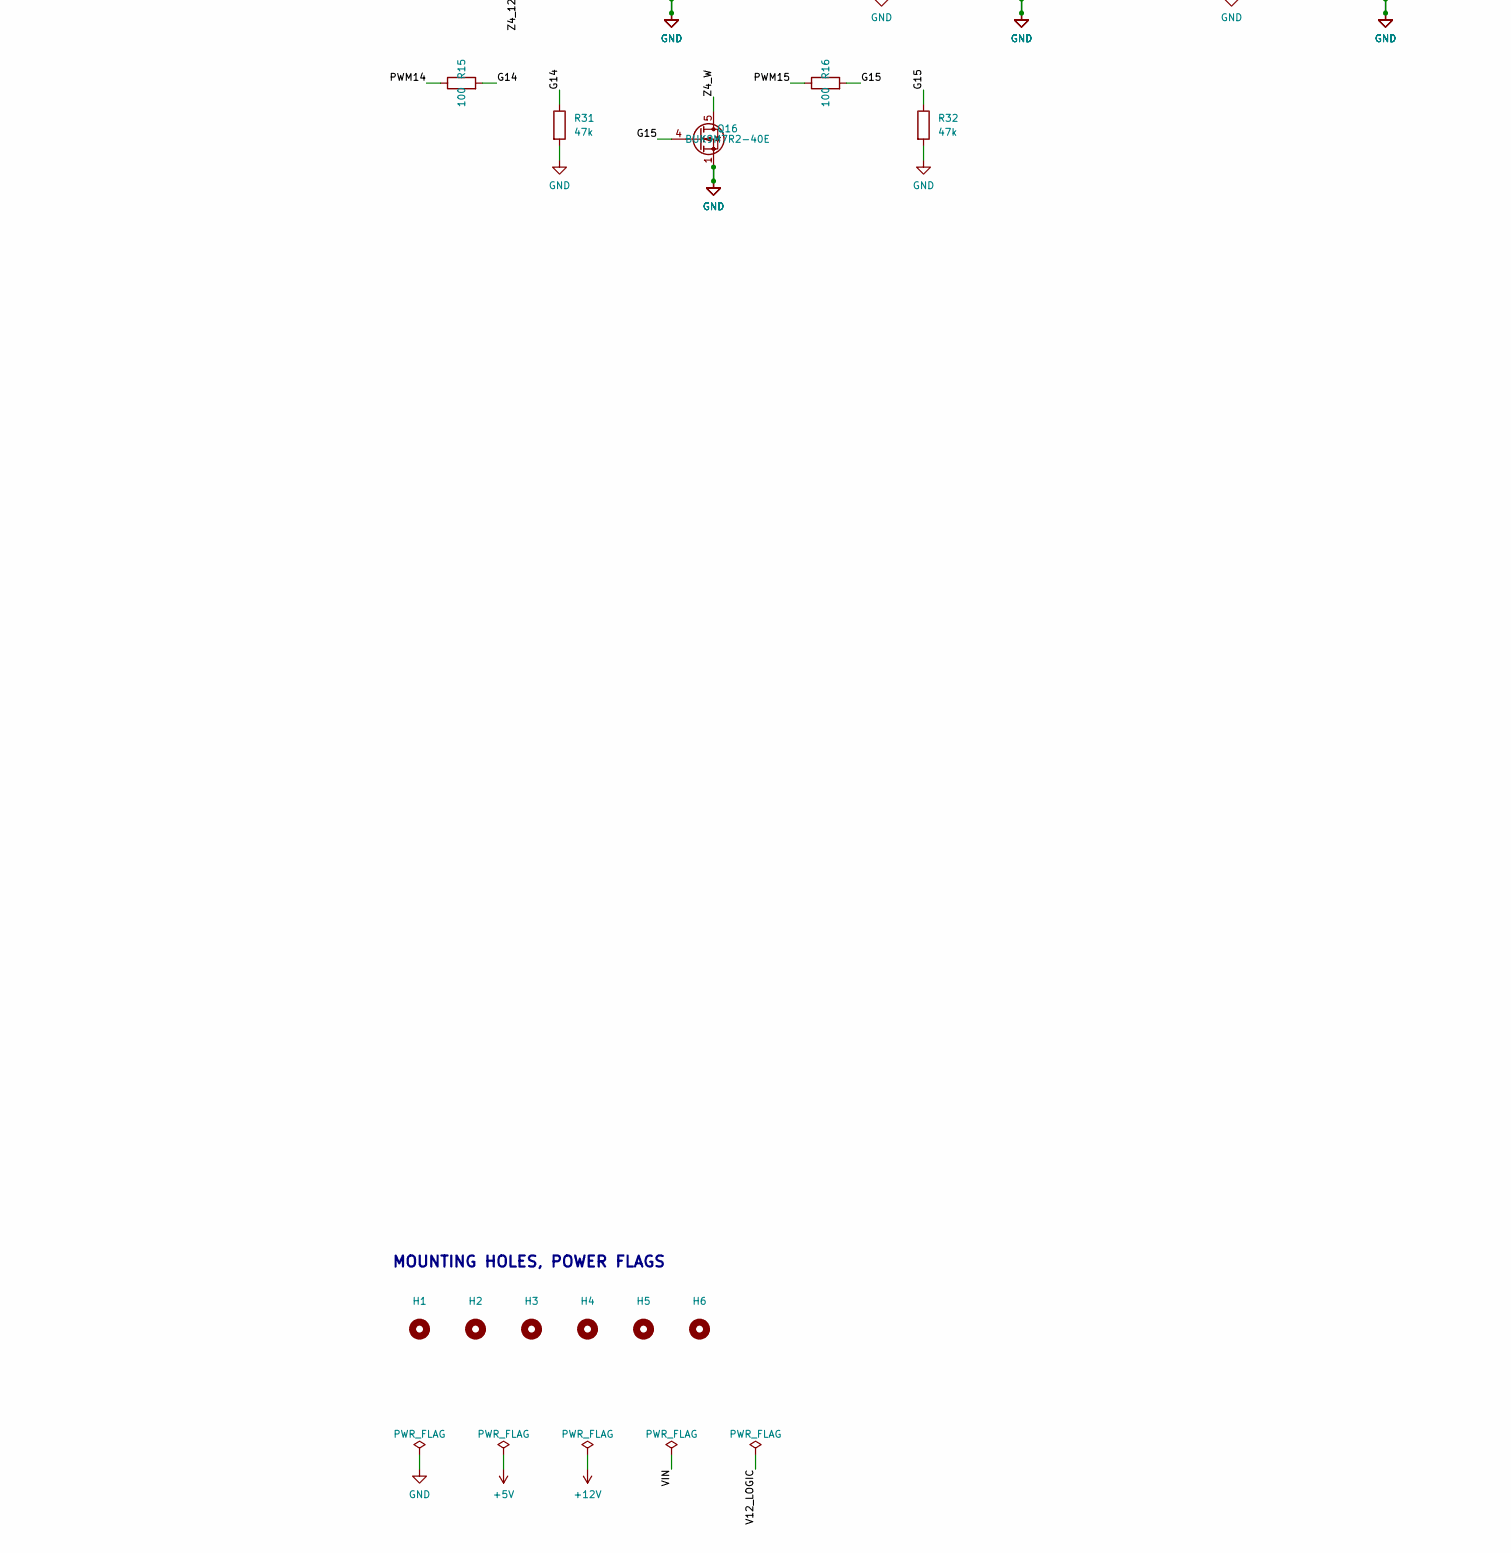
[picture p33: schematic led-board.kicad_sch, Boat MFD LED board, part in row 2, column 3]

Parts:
C1, C5, C11, C12, C14, C15, C16, C17, C18: 100n; C_0805_2012Metric_NoSilk; MPN CL21B104KBCNNNC
C6, C33: 1u; C_0805_2012Metric_NoSilk; MPN CL21B105KAFNNNE
C7: 100u 35V; CP_Elec_8x10; MPN EEE-FK1V101P
C8, C9, C10: 10u; C_1210_3225Metric; MPN CL32B106KBJNNNE
C13, C19: 22u; C_1206_3216Metric_NoSilk; MPN CL31A226KAHNNNE
C20, C23, C24, C25, C26, C27, C28, C31, C32: 100n; C_0402_1005Metric_NoSilk; MPN CL05B104KO5NNNC
C21, C22: 15p; C_0402_1005Metric_NoSilk; MPN CL05C150JB5NNNC
C29, C30: 1u; C_0402_1005Metric_NoSilk; MPN CL05A105KA5NQNC
C34: 10u; C_0805_2012Metric_NoSilk; MPN CL21A106KAYNNNE
D1: SMCJ18A; D_SMC; MPN SMCJ18A
D2: SS14; D_SMA; MPN SS14
D3, D4, D5, D6: BAT54S; SOT-23_NoSilk; MPN BAT54S,215
D7: green; LED_0805_2012Metric; MPN LTST-C171GKT
D8: yellow; LED_0805_2012Metric; MPN LTST-C171YKT
F1, F2, F3, F4, F5, F6, F7, F8: ATO; FuseHolder_Blade_ATO_Littelfuse_FLR_178.6165; MPN Littelfuse 178.6165.0002 (ATO/ATC holde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
H1, H2, H3, H4, H5, H6: MountingHole; MountingHole_3.2mm_M3
J1: LINK; RJ45_Amphenol_54602-x08_Horizontal; MPN Amphenol 54602-908LF
J2: 12V IN; TerminalBlock_MetzConnect_Type703_RT10N02HGLU_1x02_P9.52mm_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; MPN METZ CONNECT RT10N02HGLU
J3: ZONE 1; PhoenixContact_MSTB_2,5_5-GF-5,08_1x05_P5.08mm_Horizontal_T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; MPN Phoenix Contact 1776537 (MSTB 2,5/ 5-GF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
J4: ZONE 2; PhoenixContact_MSTB_2,5_5-GF-5,08_1x05_P5.08mm_Horizontal_T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; MPN Phoenix Contact 1776537 (MSTB 2,5/ 5-GF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
J5: ZONE 3; PhoenixContact_MSTB_2,5_5-GF-5,08_1x05_P5.08mm_Horizontal_T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; MPN Phoenix Contact 1776537 (MSTB 2,5/ 5-GF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
J6: ZONE 4; PhoenixContact_MSTB_2,5_5-GF-5,08_1x05_P5.08mm_Horizontal_T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; MPN Phoenix Contact 1776537 (MSTB 2,5/ 5-GF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
J7: PIXEL 1; PhoenixContact_MSTB_2,5_4-GF-5,08_1x04_P5.08mm_Horizontal_T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; MPN Phoenix Contact 1776524 (MSTB 2,5/ 4-GF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
J8: PIXEL 2; PhoenixContact_MSTB_2,5_4-GF-5,08_1x04_P5.08mm_Horizontal_T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; MPN Phoenix Contact 1776524 (MSTB 2,5/ 4-GF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
J9: PIXEL 3; PhoenixContact_MSTB_2,5_4-GF-5,08_1x04_P5.08mm_Horizontal_T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; MPN Phoenix Contact 1776524 (MSTB 2,5/ 4-GF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
J10: PIXEL 4; PhoenixContact_MSTB_2,5_4-GF-5,08_1x04_P5.08mm_Horizontal_T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; MPN Phoenix Contact 1776524 (MSTB 2,5/ 4-GF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
J11: USB; USB_C_Receptacle_GCT_USB4105-xx-A_16P_TopMnt_Horizontal; MPN GCT USB4105-GF-A
L1: 6.8u; L_Bourns_SRN6045TA; MPN SRN6045TA-6R8M
Q1, Q2, Q3, Q4, Q5, Q6, Q7, Q8, Q9, Q10, Q11, Q12, Q13, Q14, Q15, Q16: BUK9M7R2-40E; LFPAK33; MPN BUK9M7R2-40EX
Q17, Q18: BSS138; SOT-23; MPN BSS138
R1, R2, R3, R4, R5, R6, R7, R8, R9, R10, R11, R12, R13, R14, R15, R16: 100; R_0805_2012Metric_NoSilk; MPN RC0805FR-07100RL
R17, R18, R19, R20, R21, R22, R23, R24, R25, R26, R27, R28, R29, R30, R31, R32: 47k; R_0805_2012Metric_NoSilk; MPN RC0805FR-0747KL
R33, R35, R36, R38: 620; R_0805_2012Metric_NoSilk; MPN RC0805FR-07620RL
R34, R37: 120; R_0805_2012Metric_NoSilk; MPN RC0805FR-07120RL
R39, R40: 4.7k; R_0805_2012Metric_NoSilk; MPN RC0805FR-074K7L
R41, R42, R49: 10k; R_0805_2012Metric_NoSilk; MPN RC0805FR-0710KL
R43, R44, R45, R46: 330; R_1206_3216Metric_NoSilk; MPN RC1206FR-07330RL
R47: 1m; R_Shunt_Vishay_WSK2512_6332Metric_T2.21mm; MPN WSK25121L000FEA
R48: 1k; R_0402_1005Metric_NoSilk; MPN RC0402FR-071KL
R50, R55: 1k; R_0805_2012Metric_NoSilk; MPN RC0805FR-071KL
R51, R52: 27; R_0402_1005Metric_NoSilk; MPN RC0402FR-0727RL
R53, R54: 5.1k; R_0805_2012Metric_NoSilk; MPN RC0805FR-075K1L
R56: 2.2k; R_0805_2012Metric_NoSilk; MPN RC0805FR-072K2L
SW1: BOOTSEL; SW_Push_1P1T_NO_CK_KMR2; MPN KMR221GLFS
SW2: RESET; SW_Push_1P1T_NO_CK_KMR2; MPN KMR221GLFS
U1: PCA9615DP; TSSOP-10_3x3mm_P0.5mm; MPN PCA9615DP,118
U2: RP2040; QFN-56-1EP_7x7mm_P0.4mm_EP3.2x3.2mm_ThermalVias_Drill0.3; MPN RP2040
U3: W25Q16JV; SOIC-8_5.3x5.3mm_P1.27mm; MPN W25Q16JVSSIQ
U4: INA226; TSSOP-10_3x3mm_P0.5mm; MPN INA226AIDGSR
U5: PCA9685PW; TSSOP-28_4.4x9.7mm_P0.65mm; MPN PCA9685PW,118
U6: AP63205; TSOT-23-6; MPN AP63205WU-7
U7, U8, U9, U10: 74AHCT1G125; SOT-23-5; MPN SN74AHCT1G125DBVR
U11: AP2112K-3.3; SOT-23-5; MPN AP2112K-3.3TRG1
Y1: 12MHz; Crystal_SMD_3225-4Pin_3.2x2.5mm; MPN ABM8-272-T3

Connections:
+1V1: C30.1, C31.1, C32.1, U2.23 (DVDD), U2.45 (VREG_VOUT), U2.50 (DVDD)
+3V3: C20.1, C23.1, C24.1, C25.1, C26.1, C27.1, C28.1, C29.1, C34.1, Q17.1 (G), Q18.1 (G), R41.2, R42.2, R49.2, U2.1 (IOVDD), U2.10 (IOVDD), U2.22 (IOVDD), U2.33 (IOVDD), U2.42 (IOVDD), U2.43 (ADC_AVDD), U2.44 (VREG_VIN), U2.48 (USB_VDD), U2.49 (IOVDD), U3.8 (VCC), U11.5 (VOUT)
+5V: C1.1, C5.1, C6.1, C13.1, C14.1, C15.1, C16.1, C17.1, C18.1, C19.1, C33.1, D3.2 (K), D4.2 (K), D5.2 (K), D6.2 (K), L1.2, R33.1, R36.1, R39.2, R40.2, R56.1, U1.1 (V_{DD(A)}), U1.3 (EN), U1.10 (V_{DD(B)}), U4.1 (A1), U4.2 (A0), U4.6 (VS), U5.28 (VDD), U6.1 (FB), U7.5 (VCC), U8.5 (VCC), U9.5 (VCC), U10.5 (VCC), U11.1 (VIN), U11.3 (EN)
+12V: C7.1, C8.1, C9.1, D2.2 (A), F1.1, F2.1, F3.1, F4.1, F5.1, F6.1, F7.1, F8.1, R47.4
/BOOTSEL: R50.2, SW1.1
/BST5: C12.1, U6.6 (BST)
/G0: Q1.4 (G), R1.2, R17.1
/G1: Q2.4 (G), R2.2, R18.1
/G2: Q3.4 (G), R3.2, R19.1
/G3: Q4.4 (G), R4.2, R20.1
/G4: Q5.4 (G), R5.2, R21.1
/G5: Q6.4 (G), R6.2, R22.1
/G6: Q7.4 (G), R7.2, R23.1
/G7: Q8.4 (G), R8.2, R24.1
/G8: Q9.4 (G), R9.2, R25.1
/G9: Q10.4 (G), R10.2, R26.1
/G10: Q11.4 (G), R11.2, R27.1
/G11: Q12.4 (G), R12.2, R28.1
/G12: Q13.4 (G), R13.2, R29.1
/G13: Q14.4 (G), R14.2, R30.1
/G14: Q15.4 (G), R15.2, R31.1
/G15: Q16.4 (G), R16.2, R32.1
/ISENSE_N: R47.3, U4.8 (Vbus), U4.9 (Vin-)
/ISENSE_P: R47.2, U4.10 (Vin+)
/LINK_SCLM: J1.1, R34.2, R35.1, U1.6 (DSCLM)
/LINK_SCLP: J1.2, R33.2, R34.1, U1.7 (DSCLP)
/LINK_SDAM: J1.6, R37.2, R38.1, U1.9 (DSDAM)
/LINK_SDAP: J1.3, R36.2, R37.1, U1.8 (DSDAP)
/MCU_SCL: Q18.2 (S), R42.1, U2.7 (GPIO5)
/MCU_SDA: Q17.2 (S), R41.1, U2.6 (GPIO4)
/P1_12V: F5.2, J7.1
/P1_DATA: D3.3 (COM), J7.2, R43.2
/P2_12V: F6.2, J8.1
/P2_DATA: D4.3 (COM), J8.2, R44.2
/P3_12V: F7.2, J9.1
/P3_DATA: D5.3 (COM), J9.2, R45.2
/P4_12V: F8.2, J10.1
/P4_DATA: D6.3 (COM), J10.2, R46.2
/PIX1: U2.2 (GPIO0), U7.2
/PIX1_5V: R43.1, U7.4
/PIX2: U2.3 (GPIO1), U8.2
/PIX2_5V: R44.1, U8.4
/PIX3: U2.4 (GPIO2), U9.2
/PIX3_5V: R45.1, U9.4
/PIX4: U2.5 (GPIO3), U10.2
/PIX4_5V: R46.1, U10.4
/PWM0: R1.1, U5.6 (LED0)
/PWM1: R2.1, U5.7 (LED1)
/PWM2: R3.1, U5.8 (LED2)
/PWM3: R4.1, U5.9 (LED3)
/PWM4: R5.1, U5.10 (LED4)
/PWM5: R6.1, U5.11 (LED5)
/PWM6: R7.1, U5.12 (LED6)
/PWM7: R8.1, U5.13 (LED7)
/PWM8: R9.1, U5.15 (LED8)
/PWM9: R10.1, U5.16 (LED9)
/PWM10: R11.1, U5.17 (LED10)
/PWM11: R12.1, U5.18 (LED11)
/PWM12: R13.1, U5.19 (LED12)
/PWM13: R14.1, U5.20 (LED13)
/PWM14: R15.1, U5.21 (LED14)
/PWM15: R16.1, U5.22 (LED15)
/PWR_LED: D7.2 (A), R56.2
/QSPI_SCLK: U2.52 (QSPI_SCLK), U3.6 (CLK)
/QSPI_SD0: U2.53 (QSPI_SD0), U3.5 (DI/IO_{0})
/QSPI_SD1: U2.55 (QSPI_SD1), U3.2 (DO/IO_{1})
/QSPI_SD2: U2.54 (QSPI_SD2), U3.3 (~WP/IO_{2})
/QSPI_SD3: U2.51 (QSPI_SD3), U3.7 (~HOLD/~RESET/IO_{3})
/QSPI_SS: R50.1, U2.56 (~QSPI_SS), U3.1 (~CS)
/RUN: R49.1, SW2.1, U2.26 (RUN)
/SCL: Q18.3 (D), R40.1, U1.4 (SCL), U4.5 (SCL), U5.26 (SCL)
/SDA: Q17.3 (D), R39.1, U1.2 (SDA), U4.4 (SDA), U5.27 (SDA)
/STATUS: R55.1, U2.8 (GPIO6)
/STATUS_LED: D8.2 (A), R55.2
/SW5: C12.2, L1.1, U6.5 (SW)
/USB_CC1: J11.A5 (CC1), R53.1
/USB_CC2: J11.B5 (CC2), R54.1
/USB_D+: J11.A6 (D+), J11.B6 (D+), R51.2
/USB_D-: J11.A7 (D-), J11.B7 (D-), R52.2
/USB_DM: R52.1, U2.46 (USB_DM)
/USB_DP: R51.1, U2.47 (USB_DP)
/V12_LOGIC: C10.1, C11.1, D2.1 (K), U6.2 (EN), U6.3 (IN)
/VIN: D1.1 (A1), J2.1, R47.1
/XIN: C21.1, U2.20 (XIN), Y1.1
/XOUT: R48.1, U2.21 (XOUT)
/XTAL_O: C22.1, R48.2, Y1.3
/Z1_12V: F1.2, J3.1
/Z1_B: J3.4, Q3.5 (D)
/Z1_G: J3.3, Q2.5 (D)
/Z1_R: J3.2, Q1.5 (D)
/Z1_W: J3.5, Q4.5 (D)
/Z2_12V: F2.2, J4.1
/Z2_B: J4.4, Q7.5 (D)
/Z2_G: J4.3, Q6.5 (D)
/Z2_R: J4.2, Q5.5 (D)
/Z2_W: J4.5, Q8.5 (D)
/Z3_12V: F3.2, J5.1
/Z3_B: J5.4, Q11.5 (D)
/Z3_G: J5.3, Q10.5 (D)
/Z3_R: J5.2, Q9.5 (D)
/Z3_W: J5.5, Q12.5 (D)
/Z4_12V: F4.2, J6.1
/Z4_B: J6.4, Q15.5 (D)
/Z4_G: J6.3, Q14.5 (D)
/Z4_R: J6.2, Q13.5 (D)
/Z4_W: J6.5, Q16.5 (D)
GND: C1.2, C5.2, C6.2, C7.2, C8.2, C9.2, C10.2, C11.2, C13.2, C14.2, C15.2, C16.2, C17.2, C18.2, C19.2, C20.2, C21.2, C22.2, C23.2, C24.2, C25.2, C26.2, C27.2, C28.2, C29.2, C30.2, C31.2, C32.2, C33.2, C34.2, D1.2 (A2), D3.1 (A), D4.1 (A), D5.1 (A), D6.1 (A), D7.1 (K), D8.1 (K), J2.2, J7.3, J7.4, J8.3, J8.4, J9.3, J9.4, J10.3, J10.4, J11.A1 (GND), J11.A12 (GND), J11.B1 (GND), J11.B12 (GND), J11.SH (SHIELD), Q1.1 (S), Q1.2 (S), Q1.3 (S), Q2.1 (S), Q2.2 (S), Q2.3 (S), Q3.1 (S), Q3.2 (S), Q3.3 (S), Q4.1 (S), Q4.2 (S), Q4.3 (S), Q5.1 (S), Q5.2 (S), Q5.3 (S), Q6.1 (S), Q6.2 (S), Q6.3 (S), Q7.1 (S), Q7.2 (S), Q7.3 (S), Q8.1 (S), Q8.2 (S), Q8.3 (S), Q9.1 (S), Q9.2 (S), Q9.3 (S), Q10.1 (S), Q10.2 (S), Q10.3 (S), Q11.1 (S), Q11.2 (S), Q11.3 (S), Q12.1 (S), Q12.2 (S), Q12.3 (S), Q13.1 (S), Q13.2 (S), Q13.3 (S), Q14.1 (S), Q14.2 (S), Q14.3 (S), Q15.1 (S), Q15.2 (S), Q15.3 (S), Q16.1 (S), Q16.2 (S), Q16.3 (S), R17.2, R18.2, R19.2, R20.2, R21.2, R22.2, R23.2, R24.2, R25.2, R26.2, R27.2, R28.2, R29.2, R30.2, R31.2, R32.2, R35.2, R38.2, R53.2, R54.2, SW1.2, SW2.2, U1.5 (V_{SS}), U2.19 (TESTEN), U2.57 (GND), U3.4 (GND), U4.7 (GND), U5.1 (A0), U5.2 (A1), U5.3 (A2), U5.4 (A3), U5.5 (A4), U5.14 (VSS), U5.23 (~OE), U5.24 (A5), U5.25 (EXTCLK), U6.4 (GND), U7.1, U7.3 (GND), U8.1, U8.3 (GND), U9.1, U9.3 (GND), U10.1, U10.3 (GND), U11.2 (GND), Y1.2 (G), Y1.4 (G)

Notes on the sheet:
LINK: RJ45 to the sensor board's J6, differential I2C (PCA9615)
PWM: PCA9685 at 0x40, 16 channels
12 V IN (20 A) and its current monitor: INA226 at 0x45
LOGIC SUPPLIES: 5 V buck, 3.3 V for the RP2040
RP2040: the addressable outputs, I2C target at 0x30
ZONE 1: RGBW strip, PCA9685 outputs 0-3
ZONE 2: RGBW strip, PCA9685 outputs 4-7
ZONE 3: RGBW strip, PCA9685 outputs 8-11
ZONE 4: RGBW strip, PCA9685 outputs 12-15
PIXEL 1: 12 V addressable strip, RP2040 GPIO0
PIXEL 2: 12 V addressable strip, RP2040 GPIO1
PIXEL 3: 12 V addressable strip, RP2040 GPIO2
PIXEL 4: 12 V addressable strip, RP2040 GPIO3
MOUNTING HOLES, POWER FLAGS
The link: any straight-through Cat5e/Cat6 patch cable to the sensor board's J6 -- NOT Ethernet: never plug either end into a switch or a PoE injector. Pairs 1/2 (SCL) and 3/6 (SDA) carry the I2C bus as differential I2C; 4/5 and 7/8 are reserved. Each pair is terminated at both ends, 620/120/620 ohm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
Fuses: F1-F8 are standard blade (ATO/ATC) fuses, one per output, sized for that output's wire -- 10 A for 5 m of 12 V strip on 16 AWG. The whole board is 20 A: J2 takes 10 AWG from a 25 A fuse or breaker at the supply, and the software holds the total under 20 A with the INA226's reading (everythin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
Zones: common-anode 12 V RGBW strips; zone z colour c is PCA9685 output 4(z-1) + (R 0, G 1, B 2, W 3). Pixels: 12 V strips (WS2815...); BI is a WS2815's backup data input, grounded here for the strip's first pixel. Firmware: hold BOOTSEL, press RESET, and the RP2040 appears on a computer (USB-C, J1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

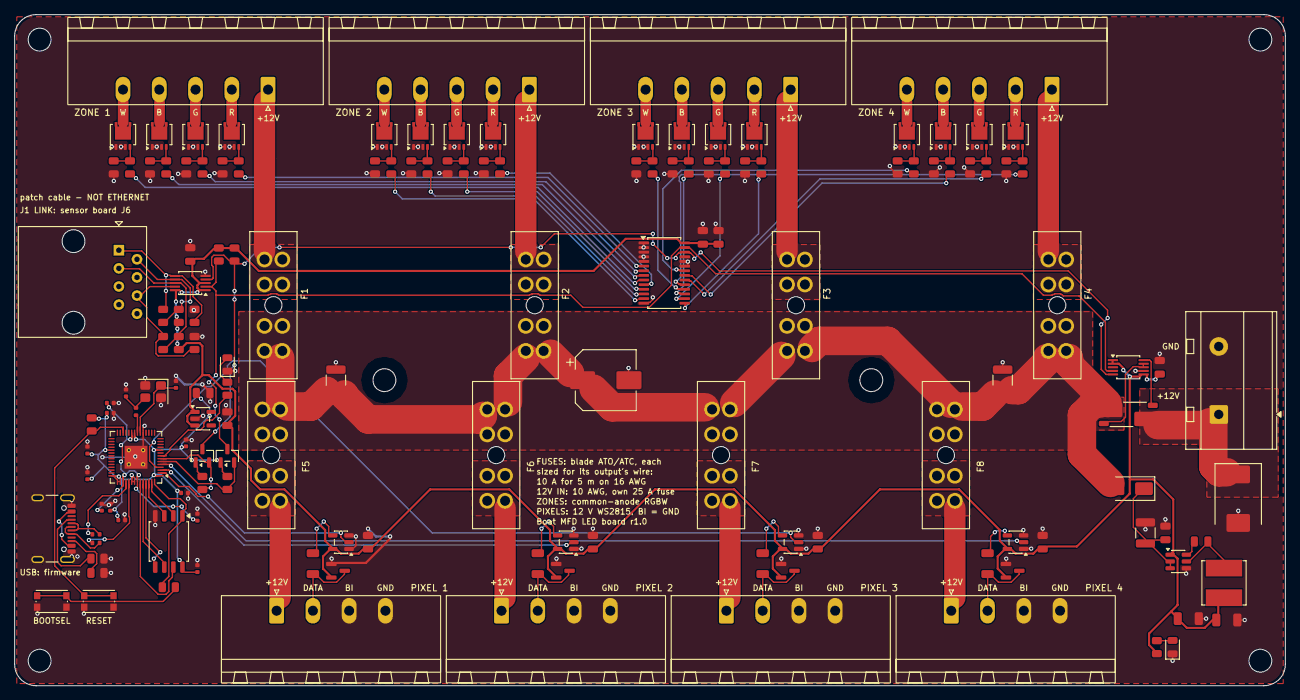
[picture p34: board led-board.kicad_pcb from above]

Board: 2 copper layers, 178.0 x 94.0 mm, 153 parts (0 on the bottom side), 107 nets.

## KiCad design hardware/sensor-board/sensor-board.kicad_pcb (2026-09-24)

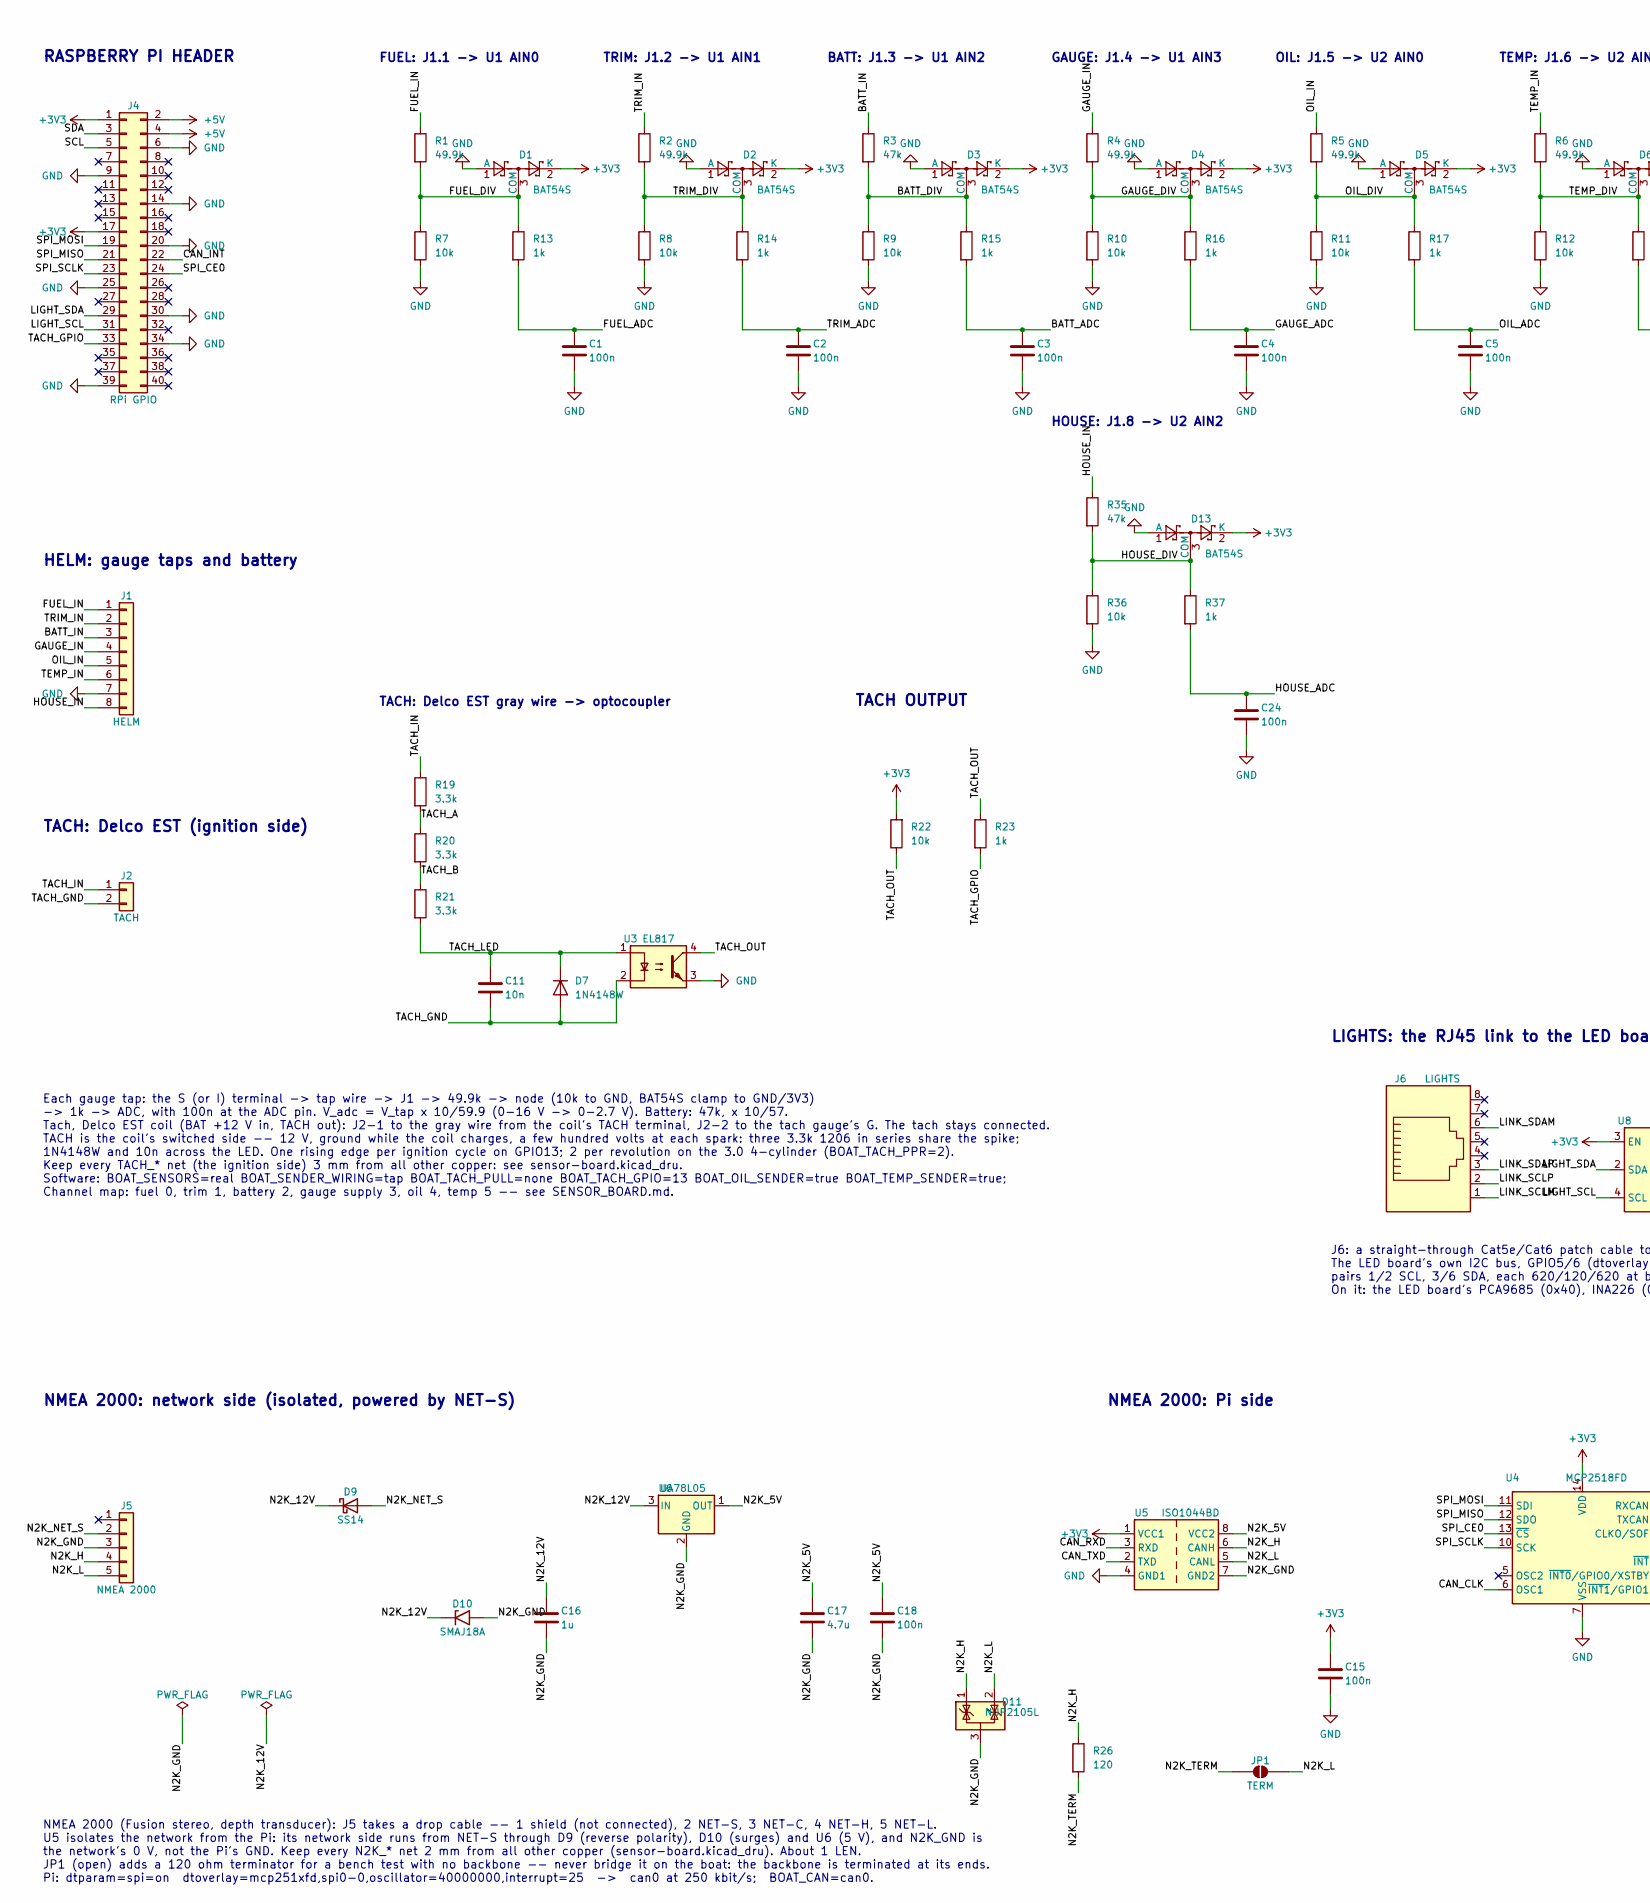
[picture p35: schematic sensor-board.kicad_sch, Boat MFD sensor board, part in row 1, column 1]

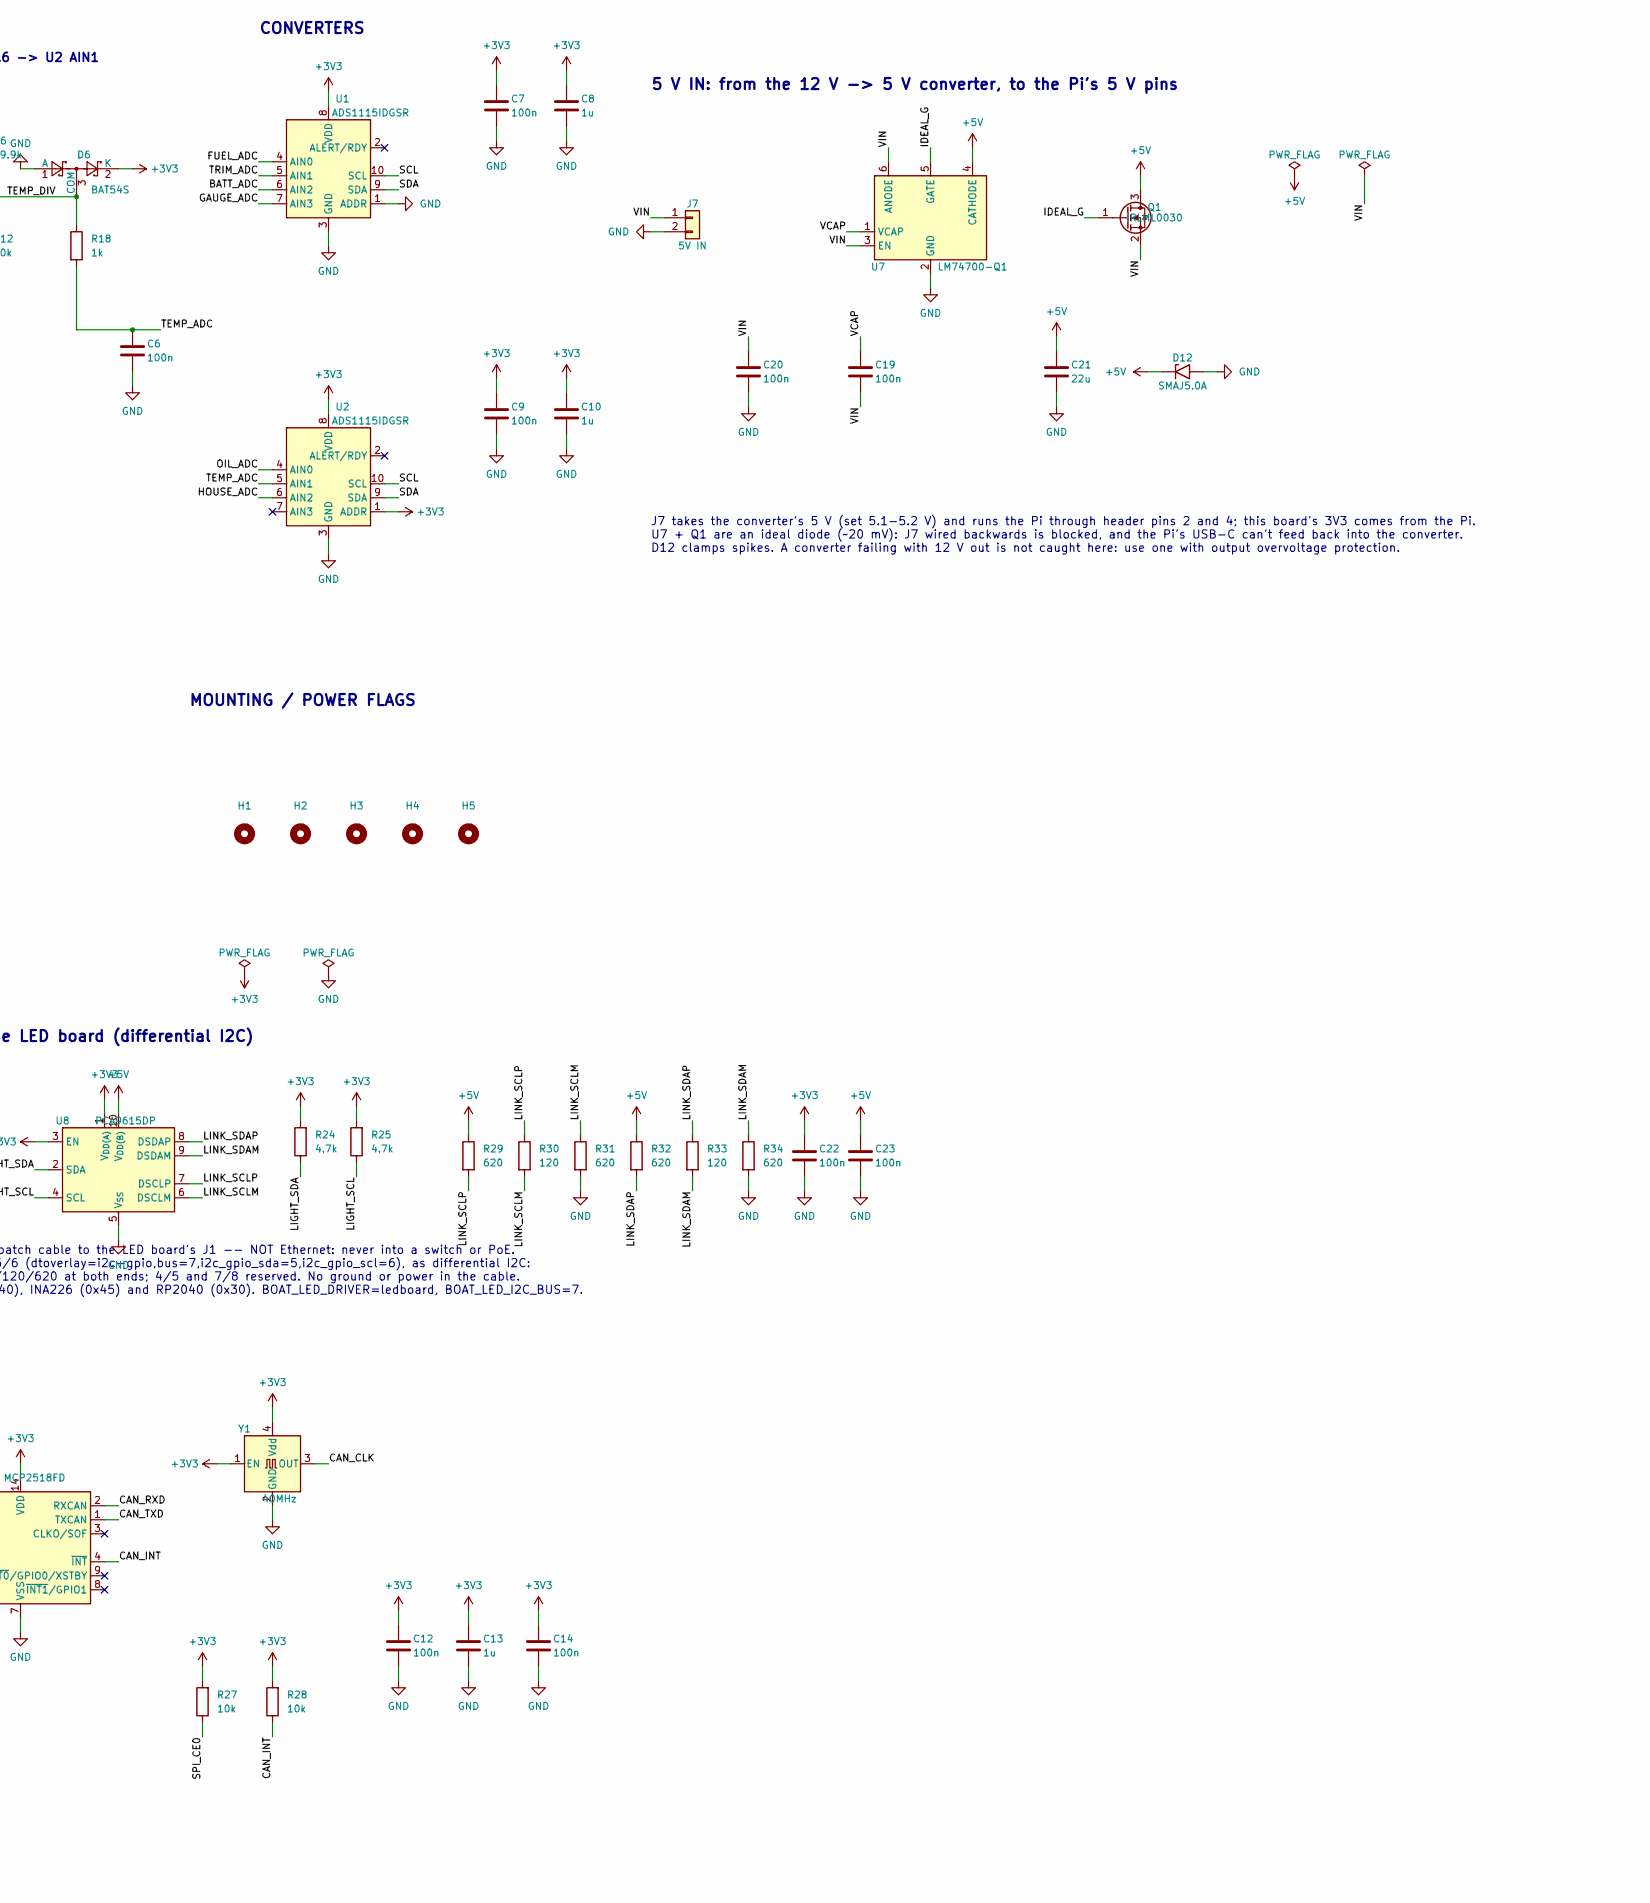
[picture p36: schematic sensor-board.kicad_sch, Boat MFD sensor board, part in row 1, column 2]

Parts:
C1, C2, C3, C4, C5, C6, C7, C9, C12, C14, C15, C18, C19, C20, C24: 100n; C_0805_2012Metric_NoSilk; MPN CL21B104KBCNNNC
C8, C10, C13: 1u; C_0805_2012Metric_NoSilk; MPN CL21B105KAFNNNE
C11: 10n; C_0805_2012Metric_NoSilk; MPN CL21B103KBANNNC
C16: 1u; C_1206_3216Metric_NoSilk; MPN CL31B105KBHNNNE
C17: 4.7u; C_0805_2012Metric_NoSilk; MPN CL21A475KAQNNNE
C21: 22u; C_1206_3216Metric_NoSilk; MPN CL31A226KAHNNNE
C22, C23: 100n; C_0402_1005Metric_NoSilk; MPN CL05B104KO5NNNC
D1, D2, D3, D4, D5, D6, D13: BAT54S; SOT-23_NoSilk; MPN BAT54S,215
D7: 1N4148W; D_SOD-123; MPN 1N4148W-7-F
D9: SS14; D_SMA; MPN SS14
D10: SMAJ18A; D_SMA; MPN SMAJ18A
D11: NUP2105L; SOT-23_NoSilk; MPN NUP2105LT1G
D12: SMAJ5.0A; D_SMA; MPN SMAJ5.0A
H1, H2, H3, H4, H5: MountingHole; MountingHole_2.7mm_M2.5
J1: HELM; PhoenixContact_MC_1,5_8-GF-3.81_1x08_P3.81mm_Horizontal_Thr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; MPN Phoenix Contact 1827923 (MC 1,5/ 8-GF-3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
J2: TACH; PhoenixContact_MC_1,5_2-GF-3.81_1x02_P3.81mm_Horizontal_Thr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; MPN Phoenix Contact 1827868 (MC 1,5/ 2-GF-3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
J4: RPi GPIO; PinSocket_2x20_P2.54mm_Vertical; MPN 2x20 female stacking header, 2.54 mm, e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
J5: NMEA 2000; PhoenixContact_MC_1,5_5-GF-3.81_1x05_P3.81mm_Horizontal_Thr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; MPN Phoenix Contact 1827897 (MC 1,5/ 5-GF-3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
J6: LIGHTS; RJ45_Amphenol_54602-x08_Horizontal; MPN Amphenol 54602-908LF
J7: 5V IN; PhoenixContact_MC_1,5_2-GF-3.81_1x02_P3.81mm_Horizontal_Thr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; MPN Phoenix Contact 1827868 (MC 1,5/ 2-GF-3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
JP1: TERM; SolderJumper-2_P1.3mm_Open_RoundedPad1.0x1.5mm
Q1: IRLML0030; SOT-23; MPN IRLML0030TRPBF
R1, R2, R4, R5, R6: 49.9k; R_1206_3216Metric_NoSilk; MPN RC1206FR-0749K9L
R3, R35: 47k; R_1206_3216Metric_NoSilk; MPN RC1206FR-0747KL
R7, R8, R9, R10, R11, R12, R22, R27, R28, R36: 10k; R_0805_2012Metric_NoSilk; MPN RC0805FR-0710KL
R13, R14, R15, R16, R17, R18, R23, R37: 1k; R_0805_2012Metric_NoSilk; MPN RC0805FR-071KL
R19, R20, R21: 3.3k; R_1206_3216Metric_NoSilk; MPN RC1206FR-073K3L
R24, R25: 4.7k; R_0805_2012Metric_NoSilk; MPN RC0805FR-074K7L
R26: 120; R_0805_2012Metric_NoSilk; MPN RC0805FR-07120RL
R29, R31, R32, R34: 620; R_0402_1005Metric_NoSilk; MPN RC0402FR-07620RL
R30, R33: 120; R_0402_1005Metric_NoSilk; MPN RC0402FR-07120RL
U1, U2: ADS1115IDGSR; TSSOP-10_3x3mm_P0.5mm; MPN ADS1115IDGSR
U3: EL817; SMDIP-4_W9.53mm; MPN EL817S1(C)(TU)-F
U4: MCP2518FD; SOIC-14_3.9x8.7mm_P1.27mm; MPN MCP2518FDT-E/SL
U5: ISO1044BD; SOIC-8_3.9x4.9mm_P1.27mm; MPN ISO1044BDR
U6: UA78L05; SOT-89-3; MPN UA78L05ACPK
U7: LM74700-Q1; SOT-23-6; MPN LM74700QDBVRQ1
U8: PCA9615DP; TSSOP-10_3x3mm_P0.5mm; MPN PCA9615DP,118
Y1: 40MHz; Oscillator_SMD_Abracon_ASE-4Pin_3.2x2.5mm; MPN ASE-40.000MHZ-L-C-T

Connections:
+3V3: C7.1, C8.1, C9.1, C10.1, C12.1, C13.1, C14.1, C15.1, C22.1, D1.2 (K), D2.2 (K), D3.2 (K), D4.2 (K), D5.2 (K), D6.2 (K), D13.2 (K), J4.1, J4.17, R22.2, R24.2, R25.2, R27.2, R28.2, U1.8 (VDD), U2.1 (ADDR), U2.8 (VDD), U4.14 (VDD), U5.1 (VCC1), U8.1 (V_{DD(A)}), U8.3 (EN), Y1.1 (EN), Y1.4 (Vdd)
+5V: C21.1, C23.1, D12.1 (A1), J4.2, J4.4, Q1.3 (D), R29.1, R32.1, U7.4 (CATHODE), U8.10 (V_{DD(B)})
/BATT_ADC: C3.1, R15.2, U1.6 (AIN2)
/BATT_DIV: D3.3 (COM), R3.2, R9.1, R15.1
/BATT_IN: J1.3, R3.1
/CAN_CLK: U4.6 (OSC1), Y1.3 (OUT)
/CAN_INT: J4.22, R28.1, U4.4 (~INT)
/CAN_RXD: U4.2 (RXCAN), U5.3 (RXD)
/CAN_TXD: U4.1 (TXCAN), U5.2 (TXD)
/FUEL_ADC: C1.1, R13.2, U1.4 (AIN0)
/FUEL_DIV: D1.3 (COM), R1.2, R7.1, R13.1
/FUEL_IN: J1.1, R1.1
/GAUGE_ADC: C4.1, R16.2, U1.7 (AIN3)
/GAUGE_DIV: D4.3 (COM), R4.2, R10.1, R16.1
/GAUGE_IN: J1.4, R4.1
/HOUSE_ADC: C24.1, R37.2, U2.6 (AIN2)
/HOUSE_DIV: D13.3 (COM), R35.2, R36.1, R37.1
/HOUSE_IN: J1.8, R35.1
/IDEAL_G: Q1.1 (G), U7.5 (GATE)
/LIGHT_SCL: J4.31, R25.1, U8.4 (SCL)
/LIGHT_SDA: J4.29, R24.1, U8.2 (SDA)
/LINK_SCLM: J6.1, R30.2, R31.1, U8.6 (DSCLM)
/LINK_SCLP: J6.2, R29.2, R30.1, U8.7 (DSCLP)
/LINK_SDAM: J6.6, R33.2, R34.1, U8.9 (DSDAM)
/LINK_SDAP: J6.3, R32.2, R33.1, U8.8 (DSDAP)
/N2K_5V: C17.1, C18.1, U5.8 (VCC2), U6.1 (OUT)
/N2K_12V: C16.1, D9.1 (K), D10.1 (A1), U6.3 (IN)
/N2K_GND: C16.2, C17.2, C18.2, D10.2 (A2), D11.3 (A), J5.3, U5.7 (GND2), U6.2 (GND)
/N2K_H: D11.1 (K), J5.4, R26.1, U5.6 (CANH)
/N2K_L: D11.2 (K), J5.5, JP1.2 (B), U5.5 (CANL)
/N2K_NET_S: D9.2 (A), J5.2
/N2K_TERM: JP1.1 (A), R26.2
/OIL_ADC: C5.1, R17.2, U2.4 (AIN0)
/OIL_DIV: D5.3 (COM), R5.2, R11.1, R17.1
/OIL_IN: J1.5, R5.1
/SCL: J4.5, U1.10 (SCL), U2.10 (SCL)
/SDA: J4.3, U1.9 (SDA), U2.9 (SDA)
/SPI_CE0: J4.24, R27.1, U4.13 (~CS)
/SPI_MISO: J4.21, U4.12 (SDO)
/SPI_MOSI: J4.19, U4.11 (SDI)
/SPI_SCLK: J4.23, U4.10 (SCK)
/TACH_A: R19.2, R20.1
/TACH_B: R20.2, R21.1
/TACH_GND: C11.2, D7.2 (A), J2.2, U3.2
/TACH_GPIO: J4.33, R23.2
/TACH_IN: J2.1, R19.1
/TACH_LED: C11.1, D7.1 (K), R21.2, U3.1
/TACH_OUT: R22.1, R23.1, U3.4
/TEMP_ADC: C6.1, R18.2, U2.5 (AIN1)
/TEMP_DIV: D6.3 (COM), R6.2, R12.1, R18.1
/TEMP_IN: J1.6, R6.1
/TRIM_ADC: C2.1, R14.2, U1.5 (AIN1)
/TRIM_DIV: D2.3 (COM), R2.2, R8.1, R14.1
/TRIM_IN: J1.2, R2.1
/VCAP: C19.1, U7.1 (VCAP)
/VIN: C19.2, C20.1, J7.1, Q1.2 (S), U7.3 (EN), U7.6 (ANODE)
GND: C1.2, C2.2, C3.2, C4.2, C5.2, C6.2, C7.2, C8.2, C9.2, C10.2, C12.2, C13.2, C14.2, C15.2, C20.2, C21.2, C22.2, C23.2, C24.2, D1.1 (A), D2.1 (A), D3.1 (A), D4.1 (A), D5.1 (A), D6.1 (A), D12.2 (A2), D13.1 (A), J1.7, J4.6, J4.9, J4.14, J4.20, J4.25, J4.30, J4.34, J4.39, J7.2, R7.2, R8.2, R9.2, R10.2, R11.2, R12.2, R31.2, R34.2, R36.2, U1.1 (ADDR), U1.3 (GND), U2.3 (GND), U3.3, U4.7 (VSS), U5.4 (GND1), U7.2 (GND), U8.5 (V_{SS}), Y1.2 (GND)

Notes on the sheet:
FUEL: J1.1 -> U1 AIN0
TRIM: J1.2 -> U1 AIN1
BATT: J1.3 -> U1 AIN2
GAUGE: J1.4 -> U1 AIN3
OIL: J1.5 -> U2 AIN0
TEMP: J1.6 -> U2 AIN1
HOUSE: J1.8 -> U2 AIN2
TACH: Delco EST gray wire -> optocoupler
RASPBERRY PI HEADER
HELM: gauge taps and battery
TACH: Delco EST (ignition side)
CONVERTERS
TACH OUTPUT
MOUNTING / POWER FLAGS
LIGHTS: the RJ45 link to the LED board (differential I2C)
5 V IN: from the 12 V -> 5 V converter, to the Pi's 5 V pins
NMEA 2000: network side (isolated, powered by NET-S)
NMEA 2000: Pi side
Each gauge tap: the S (or I) terminal -> tap wire -> J1 -> 49.9k -> node (10k to GND, BAT54S clamp to GND/3V3) -> 1k -> ADC, with 100n at the ADC pin. V_adc = V_tap x 10/59.9 (0-16 V -> 0-2.7 V). Battery: 47k, x 10/57. Tach, Delco EST coil (BAT +12 V in, TACH out): J2-1 to the gray wire from the co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
NMEA 2000 (Fusion stereo, depth transducer): J5 takes a drop cable -- 1 shield (not connected), 2 NET-S, 3 NET-C, 4 NET-H, 5 NET-L. U5 isolates the network from the Pi: its network side runs from NET-S through D9 (reverse polarity), D10 (surges) and U6 (5 V), and N2K_GND is the network's 0 V, not t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
J6: a straight-through Cat5e/Cat6 patch cable to the LED board's J1 -- NOT Ethernet: never into a switch or PoE. The LED board's own I2C bus, GPIO5/6 (dtoverlay=i2c-gpio,bus=7,i2c_gpio_sda=5,i2c_gpio_scl=6), as differential I2C: pairs 1/2 SCL, 3/6 SDA, each 620/120/620 at both ends; 4/5 and 7/8 res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
J7 takes the converter's 5 V (set 5.1-5.2 V) and runs the Pi through header pins 2 and 4; this board's 3V3 comes from the Pi. U7 + Q1 are an ideal diode (~20 mV): J7 wired backwards is blocked, and the Pi's USB-C can't feed back into the converter. D12 clamps spikes. A converter failing with 12 V o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

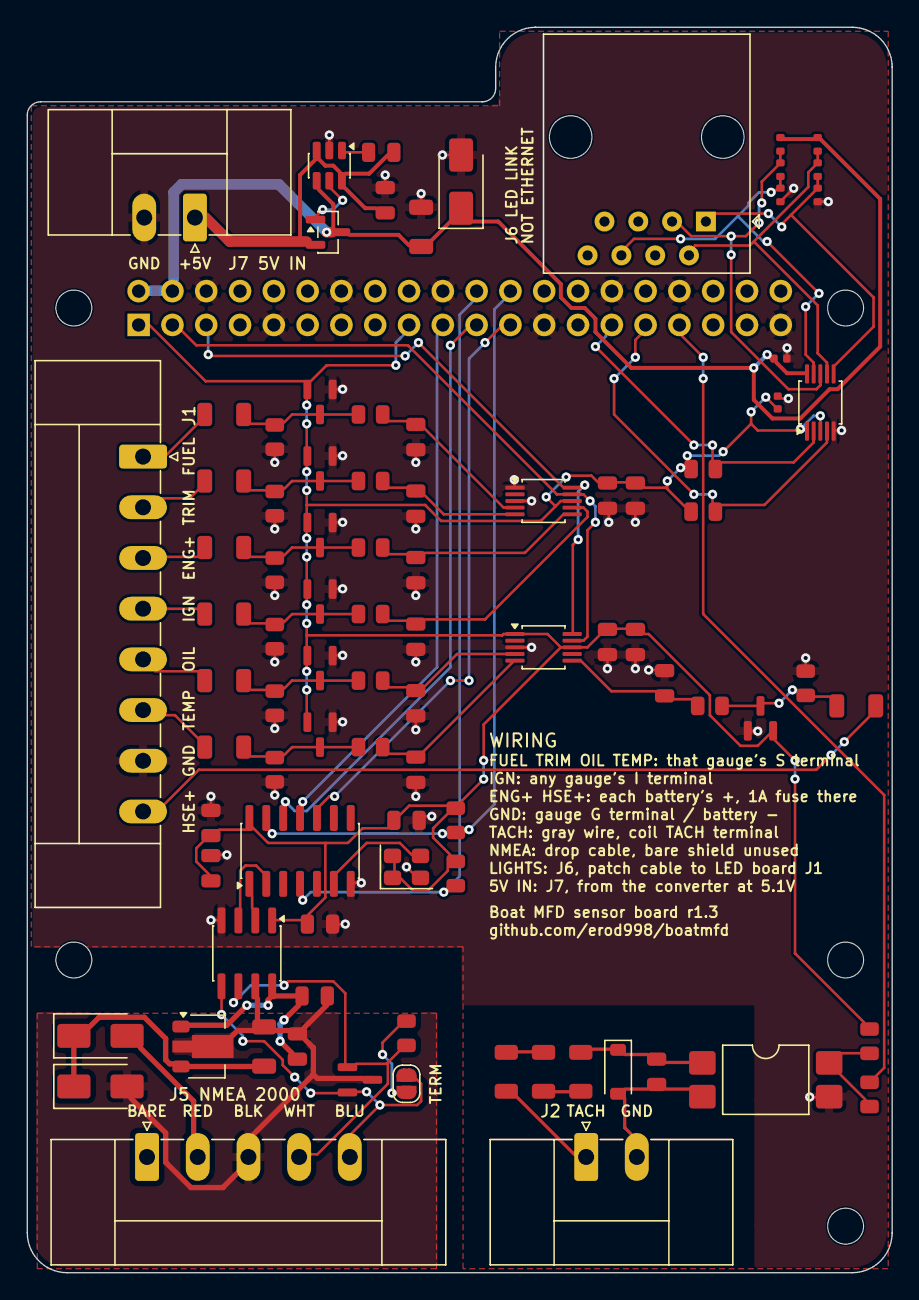
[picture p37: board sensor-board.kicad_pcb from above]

Board: 2 copper layers, 65.0 x 93.6 mm, 95 parts (1 on the bottom side), 57 nets.

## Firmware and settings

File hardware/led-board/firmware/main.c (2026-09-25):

/*
 * Boat MFD LED board: the RP2040's firmware.
 *
 * The RP2040 runs the board's four addressable outputs (J7-J10, 12 V WS2815-type strips). It is
 * an I2C target at 0x30 on the board's bus -- the same bus as the PCA9685 (0x40) and the INA226
 * (0x45), reached from the Pi over the RJ45 link -- and the Pi tells it what each output shows:
 * a mode (off, a solid colour, a rainbow), a colour, a brightness, the strip's length. It draws
 * the frames itself, so the link only ever carries a few bytes, and the rainbow keeps moving
 * smoothly whatever the Pi is doing.
 *
 * Registers (8-bit addresses; a write or read runs on through consecutive registers):
 *   0x00-0x01  'L' 'B'                      read-only: identifies the board
 *   0x02-0x03  firmware version, major/minor read-only
 *   0x04       status: bit 0 running        read-only
 *   0x05       frame counter                read-only, wraps at 255
 *   0x08       limit, 0-255 (default 255)   scales every output's current, linearly: the Pi
 *                                           lowers it to hold the board under its current budget
 *   0x10 + 0x10*n, output n = 0..3 (J7..J10):
 *     +0 mode        0 off, 1 solid, 2 rainbow
 *     +1..+3 R G B   the solid colour
 *     +4 brightness  0-255 (colour x brightness is gamma-corrected, 2.2, as the Pi's PWM zones
 *                    are, so a colour and a brightness look the same on both)
 *     +5 speed       rainbow: full colour cycles per minute (default 9)
 *     +6 order       the strip's byte order: 0 GRB (WS2812/WS2815), 1 RGB, 2 BRG, 3 RBG, 4 GBR, 5 BGR
 *     +7 flags       bit 0: run the rainbow the other way along the strip
 *     +8..+9 count   pixels on the strip, little-endian, up to 600
 *   0x7E       write 0xB0: restart as a USB drive, to load new firmware (needs USB-C plugged in)
 *   0x7F       write 0x5A: restart
 *
 * A write takes effect when the transfer ends (the I2C stop), so an output's registers change
 * together. Everything starts off: the strips stay dark until the Pi sets them, and the Pi
 * repeats its settings every two seconds, so a restart here recovers on its own.
 *
 * Pins (hardware/led-board/design.py): GPIO0-3 the four outputs' data (J7-J10), GPIO4/5 I2C0
 * SDA/SCL (through the BSS138 level shift) (buffered to 5 V by U7-U10), GPIO6 the status LED (D8).
 */
#include <math.h>
#include <string.h>

#include "hardware/clocks.h"
#include "hardware/dma.h"
#include "hardware/gpio.h"
#include "hardware/i2c.h"
#include "hardware/pio.h"
#include "hardware/sync.h"
#include "hardware/watchdog.h"
#include "pico/bootrom.h"
#include "pico/i2c_slave.h"
#include "pico/stdlib.h"
#include "ws2812.pio.h"

#define VERSION_MAJOR 1
#define VERSION_MINOR 1

#define I2C_ADDRESS 0x30
#define PIN_SDA 4
#define PIN_SCL 5
#define PIN_STATUS 6
#define OUTPUTS 4
#define MAX_PIXELS 600
#define BIT_RATE 800000

static const uint PIXEL_PIN[OUTPUTS] = {0, 1, 2, 3};

enum {
    REG_ID = 0x00, REG_VERSION = 0x02, REG_STATUS = 0x04, REG_FRAME = 0x05, REG_LIMIT = 0x08,
    REG_OUTPUT = 0x10, OUTPUT_STRIDE = 0x10, REG_BOOTSEL = 0x7E, REG_RESTART = 0x7F, REG_COUNT = 0x80,
};
enum { O_MODE, O_R, O_G, O_B, O_BRIGHTNESS, O_SPEED, O_ORDER, O_FLAGS, O_COUNT_L, O_COUNT_H };
enum { MODE_OFF, MODE_SOLID, MODE_RAINBOW };

// The registers as the Pi sees them (written from the I2C interrupt), and the copy the frames are
// drawn from, taken when a write finishes.
static volatile uint8_t regs[REG_COUNT];
static uint8_t live[REG_COUNT];
static volatile bool written;

static struct {
    uint8_t address;
    bool have_address;
    bool wrote;
} xfer;

static bool writable(uint8_t reg) {
    return reg >= REG_LIMIT;
}

static void i2c_handler(i2c_inst_t *i2c, i2c_slave_event_t event) {
    switch (event) {
    case I2C_SLAVE_RECEIVE:
        if (!xfer.have_address) {
            xfer.address = i2c_read_byte_raw(i2c) % REG_COUNT;
            xfer.have_address = true;
        } else {
            uint8_t value = i2c_read_byte_raw(i2c);
            if (writable(xfer.address)) {
                regs[xfer.address] = value;
                xfer.wrote = true;
            }
            xfer.address = (xfer.address + 1) % REG_COUNT;
        }
        break;
    case I2C_SLAVE_REQUEST:
        i2c_write_byte_raw(i2c, regs[xfer.address]);
        xfer.address = (xfer.address + 1) % REG_COUNT;
        break;
    case I2C_SLAVE_FINISH:
        if (xfer.wrote) {
            written = true;
        }
        xfer.have_address = false;
        xfer.wrote = false;
        break;
    default:
        break;
    }
}

static void defaults(void) {
    regs[REG_ID] = 'L';
    regs[REG_ID + 1] = 'B';
    regs[REG_VERSION] = VERSION_MAJOR;
    regs[REG_VERSION + 1] = VERSION_MINOR;
    regs[REG_LIMIT] = 255;
    for (int n = 0; n < OUTPUTS; n++) {
        volatile uint8_t *o = &regs[REG_OUTPUT + OUTPUT_STRIDE * n];
        o[O_MODE] = MODE_OFF;
        o[O_BRIGHTNESS] = 153;
        o[O_SPEED] = 9;
        o[O_ORDER] = 0;
    }
    for (int i = 0; i < REG_COUNT; i++) {
        live[i] = regs[i];
    }
}

// ---------------------------------------------------------------- drawing
static uint32_t frame_buf[OUTPUTS][MAX_PIXELS];

// A fully saturated colour for a hue 0-255, as the app's rainbow (red, yellow, green, cyan,
// blue, magenta, and round to red).
static void hue_to_rgb(uint8_t hue, uint8_t rgb[3]) {
    uint8_t region = hue / 43;
    uint8_t rise = (uint8_t)((hue - region * 43) * 6);
    uint8_t fall = 255 - rise;
    switch (region) {
    case 0: rgb[0] = 255; rgb[1] = rise; rgb[2] = 0; break;
    case 1: rgb[0] = fall; rgb[1] = 255; rgb[2] = 0; break;
    case 2: rgb[0] = 0; rgb[1] = 255; rgb[2] = rise; break;
    case 3: rgb[0] = 0; rgb[1] = fall; rgb[2] = 255; break;
    case 4: rgb[0] = rise; rgb[1] = 0; rgb[2] = 255; break;
    default: rgb[0] = 255; rgb[1] = 0; rgb[2] = fall; break;
    }
}

// Which of R, G, B goes out first, second and third, for each byte order.
static const uint8_t ORDER[6][3] = {{1, 0, 2}, {0, 1, 2}, {2, 0, 1}, {0, 2, 1}, {1, 2, 0}, {2, 1, 0}};

// Perceived level to LED duty: the same 2.2 gamma as the Pi applies to the zones' PWM
// (app/lighting.py), so orange is the same orange, and 60 % the same 60 %, on both.
static uint8_t gamma_table[256];

static void gamma_init(void) {
    for (int i = 0; i < 256; i++) {
        gamma_table[i] = (uint8_t)(powf(i / 255.0f, 2.2f) * 255.0f + 0.5f);
    }
}

// A channel: gamma-correct the colour at this brightness, then scale by the current limit, which
// is linear in current (the Pi's budget works in amps).
static uint32_t level(uint8_t value, uint8_t brightness, uint8_t limit) {
    return (uint32_t)gamma_table[value * brightness / 255] * limit / 255;
}

static uint32_t pack(const uint8_t rgb[3], uint8_t brightness, uint8_t limit, uint8_t order) {
    const uint8_t *o = ORDER[order < 6 ? order : 0];
    uint32_t a = level(rgb[o[0]], brightness, limit), b = level(rgb[o[1]], brightness, limit),
             c = level(rgb[o[2]], brightness, limit);
    return (a << 24) | (b << 16) | (c << 8);    // the PIO shifts out the top 24 bits, MSB first
}

static uint pixel_count(const uint8_t *o) {
    uint count = o[O_COUNT_L] | (o[O_COUNT_H] << 8);
    return count > MAX_PIXELS ? MAX_PIXELS : count;
}

static void draw(int n, uint64_t now_us) {
    const uint8_t *o = &live[REG_OUTPUT + OUTPUT_STRIDE * n];
    uint count = pixel_count(o);
    uint8_t brightness = o[O_BRIGHTNESS], limit = live[REG_LIMIT];
    uint8_t rgb[3];
    if (o[O_MODE] == MODE_SOLID) {
        rgb[0] = o[O_R];
        rgb[1] = o[O_G];
        rgb[2] = o[O_B];
        uint32_t word = pack(rgb, brightness, limit, o[O_ORDER]);
        for (uint i = 0; i < count; i++) {
            frame_buf[n][i] = word;
        }
    } else if (o[O_MODE] == MODE_RAINBOW) {
        // The whole strip spans one turn of the colour wheel, which moves `speed` turns a minute.
        uint8_t offset = (uint8_t)((now_us / 1000 * o[O_SPEED] * 256) / 60000);
        bool reverse = o[O_FLAGS] & 1;
        for (uint i = 0; i < count; i++) {
            uint k = reverse ? count - 1 - i : i;
            hue_to_rgb((uint8_t)(k * 256 / count + offset), rgb);
            frame_buf[n][i] = pack(rgb, brightness, limit, o[O_ORDER]);
        }
    } else {
        memset(frame_buf[n], 0, count * sizeof(uint32_t));
    }
}

// ---------------------------------------------------------------- sending
static PIO pio = pio0;
static int dma[OUTPUTS];

static void outputs_init(void) {
    uint offset = pio_add_program(pio, &ws2812_program);
    float div = (float)clock_get_hz(clk_sys) / (BIT_RATE * (ws2812_T1 + ws2812_T2 + ws2812_T3));
    for (int n = 0; n < OUTPUTS; n++) {
        uint sm = n, pin = PIXEL_PIN[n];
        pio_gpio_init(pio, pin);
        pio_sm_set_consecutive_pindirs(pio, sm, pin, 1, true);
        pio_sm_config c = ws2812_program_get_default_config(offset);
        sm_config_set_sideset_pins(&c, pin);
        sm_config_set_out_shift(&c, false, true, 24);
        sm_config_set_fifo_join(&c, PIO_FIFO_JOIN_TX);
        sm_config_set_clkdiv(&c, div);
        pio_sm_init(pio, sm, offset, &c);
        pio_sm_set_enabled(pio, sm, true);

        dma[n] = dma_claim_unused_channel(true);
        dma_channel_config d = dma_channel_get_default_config(dma[n]);
        channel_config_set_transfer_data_size(&d, DMA_SIZE_32);
        channel_config_set_read_increment(&d, true);
        channel_config_set_write_increment(&d, false);
        channel_config_set_dreq(&d, pio_get_dreq(pio, sm, true));
        dma_channel_configure(dma[n], &d, &pio->txf[sm], frame_buf[n], 0, false);
    }
}

static void send(void) {
    for (int n = 0; n < OUTPUTS; n++) {
        uint count = pixel_count(&live[REG_OUTPUT + OUTPUT_STRIDE * n]);
        if (count) {
            dma_channel_transfer_from_buffer_now(dma[n], frame_buf[n], count);
        }
    }
    for (int n = 0; n < OUTPUTS; n++) {
        dma_channel_wait_for_finish_blocking(dma[n]);
        while (!pio_sm_is_tx_fifo_empty(pio, n)) {
            tight_loop_contents();
        }
    }
    // The last pixel's bits are still going out of the shift register; then the line must stay
    // low for a WS2815's reset (280 us) before the next frame.
    sleep_us(60 + 300);
}

// ---------------------------------------------------------------- the loop
static void commands(void) {
    if (live[REG_BOOTSEL] == 0xB0) {
        reset_usb_boot(0, 0);
    }
    if (live[REG_RESTART] == 0x5A) {
        watchdog_reboot(0, 0, 0);
    }
}

int main(void) {
    gpio_init(PIN_STATUS);
    gpio_set_dir(PIN_STATUS, GPIO_OUT);
    defaults();
    gamma_init();

    gpio_init(PIN_SDA);
    gpio_init(PIN_SCL);
    gpio_set_function(PIN_SDA, GPIO_FUNC_I2C);
    gpio_set_function(PIN_SCL, GPIO_FUNC_I2C);
    // The bus is pulled up on the board (R41/R42); no internal pull-ups.
    i2c_init(i2c0, 100 * 1000);
    i2c_slave_init(i2c0, I2C_ADDRESS, &i2c_handler);

    outputs_init();
    watchdog_enable(1000, true);

    uint8_t frame = 0;
    regs[REG_STATUS] = 1;
    while (true) {
        watchdog_update();
        if (written) {
            uint32_t irq = save_and_disable_interrupts();
            written = false;
            for (int i = 0; i < REG_COUNT; i++) {
                live[i] = regs[i];
            }
            regs[REG_BOOTSEL] = regs[REG_RESTART] = 0;
            restore_interrupts(irq);
            commands();
        }
        uint64_t now = time_us_64();
        for (int n = 0; n < OUTPUTS; n++) {
            draw(n, now);
        }
        send();
        regs[REG_FRAME] = ++frame;
        gpio_put(PIN_STATUS, (now / 500000) & 1);    // blinks once a second while this loop runs
    }
}

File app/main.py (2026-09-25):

"""Boat dashboard backend — FastAPI app serving the web UI, REST control
endpoints, and a WebSocket telemetry stream.

One background task per rate builds the frames once and sends them to every
connected screen: engine and boat readings (with the alarms) five times a
second, so the gauges can move smoothly, and the full frame (GPS, nav, trip,
stereo, lights, track) once a second.

Run: uvicorn app.main:app --host 0.0.0.0 --port 8090
"""
import asyncio
import contextlib
import gzip
import json
import math
import os
import time
from dataclasses import asdict
from datetime import datetime
from pathlib import Path
from typing import Annotated, Literal, Optional

from fastapi import FastAPI, Request, WebSocket, WebSocketDisconnect
from fastapi.middleware.gzip import GZipMiddleware
from fastapi.responses import FileResponse, Response
from fastapi.staticfiles import StaticFiles
from pydantic import BaseModel, Field, field_validator

from .alarms import AlarmManager
from .boundaries import BoundaryManager
from .celestial import moon_phase, sun_times
from .chart_data import DETAIL_OFFSETS, ChartStore
from .gps import make_gps_source
from .guidance import GuidedPath
from .lighting import COLOR_PRESETS, LedBoardDriver, LightingController, PRESET_NAMES, Pca9685RgbDriver, WS281xDriver
from .media import make_media_source
from .n2k import make_n2k_node
from .nav import relative_bearing
from .nav_alarms import NavAlarmManager
from .nmea_out import NmeaServer, sentences as nmea_sentences
from .offline_check import report as report_offline_assets
from .quickdraw import QuickdrawRecorder
from .routes import RouteTracker
from .sensors import make_sensor_sources
from .state import Settings
from .storage import read_dict, write_json
from .switching import SwitchingPanel
from .telemute import AlarmMute
from .tracks import SavedTracks
from .trips import TripTracker
from .volume_boost import VolumeBoost
from .waypoints import SavedWaypoints

BASE_DIR = Path(__file__).resolve().parent.parent
STATIC_DIR = BASE_DIR / "static"
# Where the boat's own records live (tracks, waypoints, settings), and the charts. Both default to
# data/ in the checkout; the Pi image (image/) keeps the program read-only and points these at its
# writable storage and at the charts it was built with.
DATA_DIR = Path(os.environ.get("BOAT_DATA_DIR") or BASE_DIR / "data")
CHARTS_DIR = Path(os.environ.get("BOAT_CHARTS_DIR") or DATA_DIR / "charts")

settings = Settings()
gps_source = make_gps_source(settings)
n2k_node = make_n2k_node(settings)  # one NMEA 2000 node shared by the Fusion stereo and the fuel sensor
engine_info, boat_info, sensor_hub = make_sensor_sources(settings, DATA_DIR, n2k_node)
media_source = make_media_source(settings, n2k_node)
trip_tracker = TripTracker(DATA_DIR / "trips.json")
alarms = AlarmManager(DATA_DIR / "alarms.json")
volume_boost = VolumeBoost(DATA_DIR / "volume_boost.json", media_source, settings.redline_rpm)
telemute = AlarmMute(DATA_DIR / "telemute.json", media_source)
saved_tracks = SavedTracks(DATA_DIR / "tracks.json")
saved_waypoints = SavedWaypoints(DATA_DIR / "waypoints.json")
route_tracker = RouteTracker(DATA_DIR / "routes.json")
boundaries = BoundaryManager(DATA_DIR / "boundaries.json")
switching = SwitchingPanel(DATA_DIR / "switching.json")
quickdraw = QuickdrawRecorder(DATA_DIR / "quickdraw.json")
nav_alarms = NavAlarmManager(DATA_DIR / "nav_alarms.json")
chart_store = ChartStore(CHARTS_DIR)
# A chart app of its own on the helm display, in the chart's place (kiosk/chart-app.py): the
# kiosk page reports where its chart is, and the app reads the boat's position and depth as
# NMEA 0183 over TCP (nmea_out.py).
CHART_APP = os.environ.get("BOAT_CHART_APP", "")
NMEA_TCP_PORT = int(os.environ.get("BOAT_NMEA_TCP_PORT") or (10110 if CHART_APP else 0))
nmea_server = NmeaServer(os.environ.get("BOAT_NMEA_TCP_HOST", "127.0.0.1"), NMEA_TCP_PORT) if NMEA_TCP_PORT else None
chart_app_rect = {"visible": False, "x": 0, "y": 0, "w": 0, "h": 0}


def make_led_driver(settings):
    """Return (driver or None for the preview-only mock, pixel count)."""
    # A PWM strip is one color at a time; so is the LED board, whose addressable strips run their effects themselves.
    pixels = 1 if settings.led_driver in ("pwm", "ledboard") else settings.led_pixel_count
    try:
        if settings.led_driver == "ledboard":
            return LedBoardDriver(bus_number=settings.led_i2c_bus, pca_address=settings.pca9685_address,
                                  pixel_counts=[int(n) for n in settings.led_board_pixels.split(",")],
                                  color_order=settings.led_board_order, max_amps=settings.led_board_max_amps,
                                  zone_amps=settings.led_board_zone_amps, pixel_ma=settings.led_board_pixel_ma,
                                  white=settings.led_board_white), pixels
        if settings.led_driver == "ws281x":
            return WS281xDriver(pixels, settings.led_gpio_pin), pixels
        if settings.led_driver == "pwm":
            channels = tuple(int(c) for c in settings.led_pwm_channels.split(","))
            return Pca9685RgbDriver(address=settings.pca9685_address, channels=channels, bus_number=settings.led_i2c_bus), pixels
    except Exception as exc:  # pragma: no cover - hardware-dependent
        print(f"[lighting] could not start the '{settings.led_driver}' LED driver ({exc}); the strip preview will work but no lights will")
    return None, pixels


led_driver, led_pixels = make_led_driver(settings)
lighting = LightingController(led_pixels, driver=led_driver)

FAST_PERIOD_S = 0.2   # engine + boat readings and alarms: 5 frames a second
FULL_PERIOD_S = 1.0   # everything else
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

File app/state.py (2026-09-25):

"""App settings and simulated boat sensors (battery, depth, water temp, engine).

Real sensors (battery voltage divider on an ADC, NMEA depth sounder, an
NMEA 2000 engine gateway, etc.) plug in by replacing BoatInfo.read() /
EngineInfo.read() with real reads — the dashboard/API shape stays the same.
"""
import math
import os
import random
import time
from dataclasses import dataclass
from typing import Optional


@dataclass
class Settings:
    gps_port: str = os.environ.get("BOAT_GPS_PORT", "")  # e.g. /dev/serial0 — empty = simulator
    gps_baud: int = int(os.environ.get("BOAT_GPS_BAUD", "9600"))
    led_pixel_count: int = int(os.environ.get("BOAT_LED_COUNT", "30"))
    led_gpio_pin: int = int(os.environ.get("BOAT_LED_GPIO", "18"))
    led_driver: str = os.environ.get("BOAT_LED_DRIVER", "mock")  # mock | ws281x (addressable) | pwm (12 V RGB strip) | ledboard
    pca9685_address: int = int(os.environ.get("BOAT_PCA9685_ADDR", "0x40"), 0)
    # The I2C bus the LED board's PCA9685s are on. The sensor board gives them one of their own on
    # GPIO5/6, apart from its converters: dtoverlay=i2c-gpio,bus=7,i2c_gpio_sda=5,i2c_gpio_scl=6 and
    # BOAT_LED_I2C_BUS=7. Without the board they share the main bus, BOAT_I2C_BUS.
    led_i2c_bus: int = int(os.environ.get("BOAT_LED_I2C_BUS", os.environ.get("BOAT_I2C_BUS", "1")))
    led_pwm_channels: str = os.environ.get("BOAT_LED_PWM_CHANNELS", "0,1,2")  # PCA9685 outputs for R,G,B
    # The LED board (BOAT_LED_DRIVER=ledboard, LED_BOARD.md): each addressable output's pixel count
    # (J7-J10), their byte order, and the budget it holds the whole board to. zone/pixel figures are
    # a zone's full-white draw and one pixel's, for working out what a scene will draw before it's sent.
    led_board_pixels: str = os.environ.get("BOAT_LED_PIXELS", "300,300,300,300")
    led_board_order: str = os.environ.get("BOAT_LED_ORDER", "GRB")
    led_board_max_amps: float = float(os.environ.get("BOAT_LED_MAX_AMPS", "20"))
    led_board_zone_amps: float = float(os.environ.get("BOAT_LED_ZONE_AMPS", "8"))
    led_board_pixel_ma: float = float(os.environ.get("BOAT_LED_PIXEL_MA", "25"))
    led_board_white: bool = os.environ.get("BOAT_LED_WHITE", "true").lower() == "true"  # RGBW zones: light whites with W
    # sim | n2k (engine data from a NMEA 2000 converter such as the CX5003) | real (the Pi reads senders, tach and probes itself)
    sensors: str = os.environ.get("BOAT_SENSORS", "sim")
    battery_adc: bool = os.environ.get("BOAT_BATTERY_ADC", "false").lower() == "true"  # with n2k: measure the battery on an ADS1115
    # The sensor board's second battery input (J1.8, HSE+: the house battery, on the second ADS1115's
    # AIN2), beside the engine battery on J1.3.
    house_battery: bool = os.environ.get("BOAT_HOUSE_BATTERY", "false").lower() == "true"
    i2c_bus: int = int(os.environ.get("BOAT_I2C_BUS", "1"))
    ads1115_address: int = int(os.environ.get("BOAT_ADS1115_ADDR", "0x48"), 0)
    tach_gpio: int = int(os.environ.get("BOAT_TACH_GPIO", "17"))
    tach_ppr: int = int(os.environ.get("BOAT_TACH_PPR", "2"))  # pulses per revolution: 2 for a 4-cyl distributor engine
    redline_rpm: int = int(os.environ.get("BOAT_REDLINE_RPM", "4800"))
    oil_sender: bool = os.environ.get("BOAT_OIL_SENDER", "false").lower() == "true"
    # How the Pi reads the senders when BOAT_SENSORS=real:
    #   reference -- it takes each sender over through its own 240 ohm reference resistor, and the
    #                analog gauge on that sender must be disconnected
    #   tap       -- it only listens to the wire each analog gauge already drives, so the gauges stay
    #                connected and keep working (the sensor board in SENSOR_BOARD.md)
    sender_wiring: str = os.environ.get("BOAT_SENDER_WIRING", "reference")
    ads1115_address2: int = int(os.environ.get("BOAT_ADS1115_ADDR2", "0x49"), 0)  # the board's second ADC (oil, temp)
    # Is the engine temperature gauge tapped (the sensor board's J1.6, TEMP)? Its sender then gives
    # the coolant temperature, ahead of a clip-on probe.
    temp_sender: bool = os.environ.get("BOAT_TEMP_SENDER", "false").lower() == "true"
    # Each tap's divider on the sensor board: 49.9k over 10k. (Rev 1.0-1.1 boards had 39k on the
    # board and a 10k at the gauge end of each tap wire: BOAT_TAP_R_TOP=49000 for those.)
    tap_r_top: float = float(os.environ.get("BOAT_TAP_R_TOP", "49900"))
    tap_r_bottom: float = float(os.environ.get("BOAT_TAP_R_BOTTOM", "10000"))
    # The tach GPIO's internal pull: down for the resistor+zener input, none for the sensor board's
    # optocoupler input (which has its own pull-up), up if a board needs it.
    tach_pull: str = os.environ.get("BOAT_TACH_PULL", "down")
    # Is the analog fuel-level sender wired to the ADC? Set false if fuel level comes from NMEA 2000 instead.
    fuel_sender: bool = os.environ.get("BOAT_FUEL_SENDER", "true").lower() == "true"
    n2k_engine_instance: int = int(os.environ.get("BOAT_N2K_ENGINE_INSTANCE", "0"))  # for the engine converter and fuel-flow sensor
    n2k_fuel_tank_instance: int = int(os.environ.get("BOAT_N2K_FUEL_TANK_INSTANCE", "0"))  # for the converter's fuel input or a tank-level adapter
    n2k_temp_field: str = os.environ.get("BOAT_N2K_TEMP", "engine")  # which NMEA 2000 temperature is the coolant: engine | oil
    # Which depth transducer, by its NMEA 2000 source address, when there is more than one; empty = any
    # (the freshest). Depth messages carry no instance number to choose by.
    n2k_depth_source: Optional[int] = int(os.environ["BOAT_N2K_DEPTH_SOURCE"]) if os.environ.get("BOAT_N2K_DEPTH_SOURCE") else None
    sender_ref_ohms: float = float(os.environ.get("BOAT_SENDER_REF_OHMS", "240"))  # reference resistor above each sender
    rail_volts: float = float(os.environ.get("BOAT_RAIL_VOLTS", "3.3"))
    batt_r_top: float = float(os.environ.get("BOAT_BATT_R_TOP", "47000"))
    batt_r_bottom: float = float(os.environ.get("BOAT_BATT_R_BOTTOM", "10000"))
    w1_dir: str = os.environ.get("BOAT_W1_DIR", "/sys/bus/w1/devices")  # DS18B20 temperature probes
    # Tank size, so a fuel percentage can become gallons remaining -- and from there the
    # Fuel Remaining, Economy and Range data fields a GPSMAP shows.
    fuel_capacity_gal: float = float(os.environ.get("BOAT_FUEL_CAPACITY_GAL", "40"))
    engine_hp: float = float(os.environ.get("BOAT_ENGINE_HP", "135"))  # for the fuel-burn estimate
    engine_wot_rpm: float = float(os.environ.get("BOAT_ENGINE_WOT_RPM", "4600"))
    # The CAN interface to the NMEA 2000 network (engine converter, Fusion stereo, fuel sensor), e.g. can0. Empty = simulated stereo.
    # BOAT_FUSION_CAN is the old name and still works.
    can_channel: str = os.environ.get("BOAT_CAN") or os.environ.get("BOAT_FUSION_CAN", "")
    can_interface: str = os.environ.get("BOAT_CAN_INTERFACE", "socketcan")
    n2k_address: int = int(os.environ.get("BOAT_N2K_ADDRESS", "42"))
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

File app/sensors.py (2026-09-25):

"""Real boat sensors on a Raspberry Pi: engine data from NMEA 2000, or straight from analog senders.

Enabled with BOAT_SENSORS=n2k or BOAT_SENSORS=real; otherwise the simulators in
state.py are used. When real sensors are enabled, anything that can't be read
shows as no data (None): the dashboard never falls back to made-up numbers.

BOAT_SENSORS=n2k: an engine-data converter on the NMEA 2000 bus (for example the
Matsutec CX5003, which reads the boat's analog senders) supplies RPM, trim, oil
pressure, coolant temperature and fuel level. Battery voltage comes from an
ADS1115 on the Pi (BOAT_BATTERY_ADC=true) or the converter's alternator volts.

BOAT_SENSORS=real: the Pi reads the senders itself.
- ADS1115 (I2C 16-bit ADC) reads the resistive senders (fuel, trim, optional
  oil pressure) through a divider fed from the 3.3 V rail, and the battery
  through a resistor divider. With the sensor board (BOAT_SENDER_WIRING=tap) it
  listens to the analog gauges' own sender wires instead, engine temperature's
  included (BOAT_TEMP_SENDER=true).
- The tach is an edge counter on a GPIO fed by a conditioned copy of the
  ignition coil's negative (tach) signal.
- DS18B20 probes on the Pi's 1-Wire bus give engine (coolant) temperature -- when
  no temperature sender is tapped, or it can't be read -- and, optionally, water
  temperature.

In both modes a NMEA 2000 fuel-flow sensor gives measured GPH (otherwise GPH is
estimated from RPM and corrected against real fill-ups), and a value heard on
the bus beats the same value read locally. A NMEA 2000 depth transducer (see
n2k_env.py) works the same way in both modes: depth, and sea temperature if the
transducer sends it, come from the bus whenever one is present.

Calibration is captured on the boat from /calibrate and stored in
data/calibration.json.
"""
import json
import threading
import time
from collections import deque
from pathlib import Path

from . import sender_tap
from .n2k_engine import N2kEngineData
from .n2k_env import N2kEnvData
from .state import BoatInfo, EngineInfo, estimate_gph
from .storage import read_dict, write_json

N2K_OIL_FULL_PSI = 145.04  # engine converters such as the CX5003 read oil senders as 0-10 bar (10-184 ohm)


class ADS1115:
    """Single-shot reads of a single-ended input, +/-4.096 V range, 128 SPS."""

    REG_CONVERSION = 0x00
    REG_CONFIG = 0x01
    FULL_SCALE_V = 4.096

    def __init__(self, bus, address=0x48, sleep=time.sleep):
        self.bus = bus
        self.address = address
        self._sleep = sleep

    def read_volts(self, channel):
        # OS=1 (start), MUX=100+channel (AINx vs GND), PGA=001 (+/-4.096 V), MODE=1 (single shot),
        # DR=100 (128 SPS), comparator off. Channel 0 gives the well-known 0xC383.
        config = 0x8000 | ((4 + channel) << 12) | 0x0200 | 0x0100 | 0x0080 | 0x0003
        self.bus.write_i2c_block_data(self.address, self.REG_CONFIG, [config >> 8, config & 0xFF])
        self._sleep(0.009)
        for _ in range(10):  # wait for the conversion-complete bit
            if self.bus.read_i2c_block_data(self.address, self.REG_CONFIG, 2)[0] & 0x80:
                break
            self._sleep(0.002)
        raw = int.from_bytes(bytes(self.bus.read_i2c_block_data(self.address, self.REG_CONVERSION, 2)), "big", signed=True)
        return raw * self.FULL_SCALE_V / 32768.0


def ohms_from_divider(v_node, v_rail, r_ref):
    """Sender to ground, r_ref up to the rail: v_node = v_rail * r_sender / (r_ref + r_sender)."""
    if v_node >= v_rail * 0.98:
        return None  # sender open or disconnected
    return r_ref * max(v_node, 0.0) / (v_rail - v_node)


class ADS1115Pair:
    """The sensor board's two converters as one eight-input device: 0-3 on the first, 4-7 on the second."""

    def __init__(self, first, second=None):
        self.first, self.second = first, second

    def read_volts(self, channel):
        if channel >= 4:
            if self.second is None:
                raise OSError("no second ADS1115 on this board")
            return self.second.read_volts(channel - 4)
        return self.first.read_volts(channel)


def linear_percent(value, at_0, at_100):
    span = at_100 - at_0
    if span == 0:
        return None
    return max(0.0, min(100.0, (value - at_0) / span * 100.0))


class TachCounter:
    """Turns ignition pulses into RPM.

    Count one edge per spark: the rising edge when the coil fires. The ring-down
    right after each spark can make extra edges, so after an accepted edge all
    edges are ignored for max(min_interval_s, half the recent interval).
    ppr is pulses per crankshaft revolution: 2 for a 4-cylinder, 4-stroke engine
    with a distributor (one spark per cylinder every two revolutions).
    """

    def __init__(self, ppr=2, min_interval_s=0.0025, stale_s=1.5, window=4, clock=time.monotonic):
        self.ppr = ppr
        self.min_interval_s = min_interval_s
        self.stale_s = stale_s
        self._clock = clock
        self._intervals = deque(maxlen=window)
        self._last_t = None
        self._last_seen = None
        self._lock = threading.Lock()

    def edge(self, t_ns):
        """Feed one edge with its timestamp in nanoseconds."""
        t = t_ns / 1e9
        with self._lock:
            if self._last_t is not None:
                dt = t - self._last_t
                recent = sum(self._intervals) / len(self._intervals) if self._intervals else 0.0
                if dt < max(self.min_interval_s, 0.5 * recent):
                    return
                if dt > self.stale_s:
                    self._intervals.clear()  # engine was stopped; start over
                else:
                    self._intervals.append(dt)
            self._last_t = t
            self._last_seen = self._clock()

    def rpm(self):
        with self._lock:
            if not self._intervals or self._clock() - self._last_seen > self.stale_s:
                return 0.0
            return 60.0 / ((sum(self._intervals) / len(self._intervals)) * self.ppr)


class LgpioEdgeInput:
    """Rising-edge timestamps from a GPIO via lgpio (works on every Pi, including the Pi 5)."""

    def __init__(self, gpio, on_edge, chip=0, pull="down"):
        import lgpio

        self._lgpio = lgpio
        self._handle = lgpio.gpiochip_open(chip)
        flags = {"down": lgpio.SET_PULL_DOWN, "up": lgpio.SET_PULL_UP, "none": lgpio.SET_PULL_NONE}[pull]
        lgpio.gpio_claim_alert(self._handle, gpio, lgpio.RISING_EDGE, flags)
        self._callback = lgpio.callback(self._handle, gpio, lgpio.RISING_EDGE, lambda chip, g, level, ts: on_edge(ts))
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

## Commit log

2026-09-22 Make the alarm sound reachable on a phone/tablet viewing over WiFi
    Browsers block Web Audio until the page is touched once; a Pi's own kiosk
    Chromium is launched with a flag that skips this, but a phone or tablet
    loading the dashboard over WiFi hits it and would sit through a real alarm
    in total silence with no clue why. Add a one-time "tap anywhere to enable
    alarm sound" hint that shows if sound is still locked a couple seconds
    after load, and make the beep itself louder and two-toned so it reads
    more like an alarm.
2026-09-22 Smooth zooming, a faster sim cruise, a reworked Media layout, and dev convenience
    - Chart: warm the browser's tile cache for the next zoom level (in and out)
    right after a zoom settles, so the black squares from the ArcGIS export
    service's slow per-tile renders mostly disappear on the next zoom.
    - Chart: skip the boat-lock panBy() while Leaflet's own zoom animation is
    running (isZooming) -- calling it mid-animation was fighting the in-
    progress transform and made the boat icon visibly snap during a zoom.
    - Simulator: cruise at ~40 mph / ~4200 RPM with natural fluctuation instead
    of a top-end ~9 kn / ~2600 RPM lake-idle pace.
    - Media (full): Master plus the per-zone rows now sit in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
    [gps.py, main.py, state.py]
2026-09-22 Replace the Windows update script with one that actually runs on the Pi
    run.ps1 assumed running the server locally on the dev machine; the real
    workflow is SSH into the Pi (which has no PowerShell) and restart the
    systemd service that's already running there. update.sh does that: git
    pull, then systemctl restart boat-dashboard. Also pins *.sh/*.py to LF
    line endings via .gitattributes so a future edit on Windows can't quietly
    break the shebang line on Linux.
2026-09-22 Make Test sound self-diagnosing, and fix a silent-first-test race
    resume() on a suspended AudioContext is async; test() was firing the beep
    pattern in the same tick, so a context that was still "suspended" at that
    exact instant made beep() silently no-op -- no sound, no error, nothing
    to go on. test() now waits for resume() to actually land before a
    one-shot test. Test sound also now alerts the AudioContext's state
    (supported/created/state/sample rate/last error) after playing, since
    there's no way to attach a debugger to someone's iPad remotely -- this
    was built specifically to chase down why alarm sound wasn't audible on
    one.
2026-09-22 Dead-reckon boat position instead of easing toward a once-a-second target, and color the LED brightness bar to the strip's own color
    The chart's "why does it tick forward, stop, and go again" report: the
    boat's on-screen position eased toward a target that only moves once a
    second (a GPS fix's own rate). That's a front-loaded exponential curve --
    fast at first, asymptotically slower -- so it sprints to cover the whole
    second's travel early, then visibly creeps/sits for the remainder of that
    second waiting on the next fix. Fine at a lake-idle 6-9 kn where the jump
    was small; obvious at a 40 mph cruise where it isn't. Replaced with actual
    dead reckoning: project forward every frame from the la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
2026-09-22 Cache chart tiles locally, plus track-line zoom flicker, editable pinned screens, waypoint search, and an LED brightness fix
    The big one: the browser used to hit ienccloud.us directly for every tile,
    every time -- a live dynamic render, not a cached tile, needing internet
    for a chart to show at all. The boat has WiFi at the dock, not on the
    water. Tiles now go through this app's own backend (/api/tiles/z/x/y.png,
    app/chart_tiles.py), which serves from data/tiles/ on disk when it's
    there (measured: ~300ms cold vs ~1ms warm) and only reaches upstream on a
    cache miss, saving the result for next time. app/seed_tiles.py
    pre-downloads a whole area over WiFi ahead of time, with a dry-run mode
    and a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
    [main.py]
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2026-09-22 Draw the chart from S-57 vectors instead of caching rendered tiles
    The tile cache was solving the wrong problem. Real chartplotters don't
    download pictures of charts -- they ship the vector chart data and render
    it. That's why they work offline, stay sharp at any zoom, and can tell you
    what a buoy is.
    The same USACE service that was rendering tiles exposes every S-57 feature
    class as a queryable layer (capabilities "Map,Query,Data"), so the chart
    can be fetched as actual GeoJSON. For Old Hickory Lake:
    raster tiles vectors
    requests ~4,500 throttled ~60, once
    time ~3.75 hours 36 seconds
    on disk 88 MB 2.1 MB
    z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
    [chart_data.py, fetch_charts.py, main.py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]
2026-09-22 Fail loudly when static/ depends on the internet
    The CDN Leaflet was invisible to everything: tests passed, the chart drew, and
    it would have failed only out of WiFi range, where nothing can be fixed. Nothing
    in the suite was looking for that class of bug, so add something that does.
    app/offline_check.py scans static/ for references that need the internet --
    HTML src/href, CSS url() and @import, and URLs in JS string literals. Scanning
    literals rather than raw text means a URL cited in a comment is free, which
    matters because every file here cites its sources; xmlns SVG namespaces are
    allowlisted for the same reason, since chrome.js and dials.js both declare one
    and neither is ever fetched.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
    [main.py, offline_check.py]
2026-09-23 Close the biggest GPSMAP feature gaps, and bound every API input
    A pass over the whole codebase against what a real GPSMAP does. The code itself
    held up -- no bare excepts, no mutable defaults, divisions guarded, and the
    telemetry loops (non-drifting pacing, blocking GPS reads off the event loop,
    stalled clients dropped) are sound. The gaps were in features and in what the
    REST layer would accept.
    Navigation math (app/nav.py, now with its own tests):
    - VMG, the field that was missing entirely. Time To Destination is computed
    from it rather than from speed, because sliding sideways past a waypoint at
    20 kn is not arriving at 20 kn, and it reads "--" rather than a negative
    number when t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
    [main.py, nav.py, routes.py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]
2026-09-23 Stop a power cut from silently destroying saved data
    Every waypoint, route, track, trip, setting and calibration value lives in a
    small JSON file on the Pi's SD card, and the battery switch cuts power with
    no shutdown. Nine of the thirteen writers used write_text, which truncates
    and then writes; power lost in between leaves the file empty or half-written.
    The loaders then treated the damage as "nothing saved yet" -- sensible for
    not crashing at boot -- and the next save wrote defaults straight over it.
    Every waypoint gone, no message anywhere, with the most frequently rewritten
    file (sensor calibration, flushed every minute) the most exposed.
    app/storage.py: writes go to a temp file, are f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
    [boundaries.py, nav_alarms.py, quickdraw.py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]
2026-09-23 Make the real hardware paths survive real hardware
    The simulator runs everywhere except the boat, so none of this code had ever
    run against a real device. Each fix below has a test that fails on the old
    code and passes on the new (checked by running the tests against the
    previous commit).
    GPS (app/gps.py): a silent GPS was reported as a live fix forever, because
    every read was stamped current whether or not anything arrived. An RMC with
    status V parses as lat/lon 0.0 and was applied -- a void sentence after a good
    GGA gave a *valid* fix at 0N 0E, off Africa. Line noise raised ValueError past
    the only except. An unplugged USB GPS raised out of every frame, freezing the
    chart, nav, trip, ster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
    [alarms.py, gps.py, main.py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]
2026-09-23 Read the engine off the existing gauges, which keep working
    A passive-tap mode (BOAT_SENSORS=real, BOAT_SENDER_WIRING=tap) and the sensor
    board to go with it (SENSOR_BOARD.md): fuel, trim, oil, battery and RPM read by
    listening to the wires the analog gauges already drive. Nothing is
    disconnected, so with the Pi off or broken the helm is a normal helm. Replaces
    buying an engine-data converter.
    The voltage on a gauge's sender terminal is not linear in level -- the gauge
    and the sender form a divider, and a straight line between an empty and a
    full reading is ~20 points out at half a tank (capturing "empty" would also
    mean running the tank dry). A resistive gauge seen from its sender terminal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
    [sender_tap.py, sensors.py, state.py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]
2026-09-23 Sensor board: KiCad schematic, PCB and fab files for the passive-tap HAT
    A 65 x 56 mm Raspberry Pi HAT that listens to the existing analog gauges
    (fuel, trim, oil, battery, gauge supply, spare) through two ADS1115s, reads
    RPM from the Delco EST ignition's gray tach wire through an optocoupler, and
    carries the 1-Wire temperature probes.
    Everything is generated from hardware/sensor-board/design.py:
    - schematic.py draws the schematic; board.py places, routes (router.py),
    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
    [sensor-board-bom.csv, sensor-board.kicad_pcb, sensor-board.kicad_sch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]
2026-09-23 Chart: whole lake, real surveyed depths, names, and Heading Up that turns
    Coverage: Old Hickory from the dam to Cordell Hull Dam (it stopped at
    Gallatin), plus marinas, docks, restricted areas, notice marks, the lock,
    roads, railroads and the named places a chart prints. One request every 3 s;
    point layers fetched once for both detail levels.
    Depths: the Corps chart only has 0-9 ft and 9 ft+ here. New
    app/survey_depths.py + fetch_depths turn the Corps' eHydro channel surveys
    (river miles 216-225 and 297-313) into a 25 ft depth grid and soundings,
    shaded on the chart and read by the cursor, relative to a shared Lake level
    setting (Map Settings), like a Garmin with lake charts.
    Fixes:
    - Head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
    [chart_data.py, fetch_charts.py, fetch_depths.py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]
2026-09-23 Sensor board rev 1.1: isolated NMEA 2000 on the board
    The Fusion stereo (and the depth transducer) now reach the Pi through the
    sensor board itself, not a separate CAN HAT:
    - MCP2518FD CAN FD controller on SPI0 (GPIO 8-11), interrupt on GPIO 25,
    40 MHz oscillator: Raspberry Pi OS's mcp251xfd overlay makes it can0
    - ISO1044 isolated transceiver; the network side is powered from NET-S
    through reverse-polarity, surge and ESD protection and a 5 V regulator,
    referenced to the network's own ground (about 1 LEN)
    - J5, a 5-pin locking plug for a drop cable, Micro-C pin order; a 120 ohm
    bench-only terminator behind an open solder jumper
    - the network side is its own island: 2 mm from all oth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
    [sensor-board-bom.csv, sensor-board.kicad_pcb, sensor-board.kicad_sch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]
2026-09-23 Sensor board: pre-order review and PCBWay order package
    Checked against the manufacturers' datasheets rather than KiCad's library:
    ISO1044 (TI), MCP2518FD (Microchip Table 1-1), uA78L05 SOT-89 (TI),
    NUP2105L (onsemi), EL817 incl. its SMD land pattern (Everlight), Abracon ASE.
    Changes from the review:
    - U6 is now TI's UA78L05ACPK, whose SOT-89 pinout (1 out, 2 gnd, 3 in) was
    read from TI's datasheet; ST's could not be retrieved to confirm
    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
    [sensor-board-bom.csv, sensor-board-pcbway-bom.csv, sensor-board-pcbway-centroid.csv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]
2026-09-23 Chart: draw from map tiles, depth numbers from zoom 15, survey outlines
    The chart was thousands of Leaflet vector layers, and Leaflet re-projected
    all 170,000 vertices of the lake on every zoom: ~80 ms per zoom step on a
    desktop, a visible stall on the iPad. It is now cut into map tiles in the
    browser (geojson-vt 3.2.1, vendored): each tile is drawn once and reused, so
    a zoom step costs ~12 ms here. Aids to navigation stay tappable markers; the
    cursor reads the raw features. The chart loads once at full detail (the
    tiles simplify per zoom), so there is no reload when crossing zoom 13.
    Tile fading is off -- a chartplotter doesn't fade its chart in.
    Surveyed depths: soundings show from zoom 1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
2026-09-23 Sensor board rev 1.2: every connector pin labelled on the board
    Each pin of J1, J2, J3 and J5 now has its connection printed beside it, on
    the wire side of the connector: FUEL TRIM BAT+ IGN OIL SPARE GND GND on the
    helm connector, TACH/GND on the tach, 3V3/DATA/GND on the probes, and the
    NMEA 2000 drop cable's wire colours on J5. The numbered pinout block in the
    middle is replaced by a WIRING block that says where each kind of wire goes.
    Tach wording is for the newer EST coil only (BAT in, TACH out). The input
    itself is unchanged: the coil's TACH terminal is its switched side and
    spikes to a few hundred volts, which is what the optocoupler input is for.
    Parts moved to make room for the lab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
    [sensor-board-bom.csv, sensor-board-pcbway-centroid.csv, sensor-board.kicad_pcb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]
2026-09-23 Sensor board: J6 LIGHTS connector for a separate LED board
    The LED controllers stay off this board (strip current next to the gauge
    taps, and a shorted strip taking the engine data down with it). J6 gives
    a future LED board what it needs from the Pi and nothing it switches:
    3V3 for its logic, the I2C bus for PCA9685 PWM channels (as many as
    needed), GPIO18 and GPIO19 (PWM0/PWM1) for two addressable strips, GPIO21
    spare, and two grounds. JST GH 8-way, latching, SMD on the right edge
    between the probe connector and the mounting hole; pins labelled on the
    silkscreen.
    The two lines from the header's far corner route on the bottom layer so
    they don't wall off the header's GND pin 39 from the top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
    [sensor-board-bom.csv, sensor-board-pcbway-bom.csv, sensor-board-pcbway-centroid.csv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]
2026-09-23 Engine temperature from the temp gauge's own sender (J1.6 is now TEMP)
    The boat has a temperature gauge with a sender on the engine, so the
    board's spare tap becomes TEMP (same circuit; label, net names, docs).
    Software (BOAT_TEMP_SENDER=true): the sender is a thermistor, and its
    absolute resistance -- which differs between makes, and halves on a
    dual-station sender -- folds into the divider fit as the fuel sender's
    does. Only the curve's shape matters, and the published curves agree on
    it (B about 3900-4000 K). So a cold point (the air or lake temperature
    after the engine has sat) and a warm point calibrate the whole gauge,
    overheat included: straight lines through the same two points read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
    [sensor-board-bom.csv, sensor-board.kicad_pcb, sensor-board.kicad_sch]
2026-09-23 Sensor board: 5 V input (J7) that powers the Pi through the header
    The Pi now runs from an external 12 V -> 5 V converter wired to J7 on the
    board, through the header's 5 V pins (back-powering, 5 V +/-5 %, up to
    2.5 A per the HAT guide); the board's 3V3 comes from the Pi as before.
    An ideal diode sits in the way (TI LM74700-Q1 driving an IRLML0030): about
    20 mV drop where a Schottky's 0.4 V would trip the Pi's undervoltage
    warning. J7 wired backwards is blocked, and the Pi's USB-C can't push
    current back into the converter. SMAJ5.0A clamp and 22 uF bulk on the
    rail. Not protected: a converter failing with 12 V out (docs say to buy
    one with output OVP).
    The Pi's 5 V pins are in the header's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
    [sensor-board-bom.csv, sensor-board-pcbway-bom.csv, sensor-board-pcbway-centroid.csv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]
2026-09-23 Sensor board: no probe input; J6 gets its own I2C bus
    No temperature probes on this boat: engine temperature comes from the temp
    gauge's sender (J1 TEMP), water temperature from the depth transducer on
    NMEA 2000. J3 and its 1-Wire parts (D8, R24, R25, GPIO26) are gone.
    J6 moves to J3's old spot on the right edge, next to the header pins it
    uses, and its SDA/SCL leave the converters' bus for a bus of their own:
    i2c-gpio on GPIO5/6 (dtoverlay=i2c-gpio,bus=7,...; BOAT_LED_I2C_BUS=7),
    4.7k pull-ups on the board (R24, R25). A stuck or shorted LED board can't
    stall the engine data, and a bit-banged bus handles clock stretching,
    which a microcontroller on the LED board may do and the Pi's hardware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
    [sensor-board-bom.csv, sensor-board-pcbway-bom.csv, sensor-board-pcbway-centroid.csv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]
2026-09-23 Sensor board: tap resistors all on the board, plain wire to the gauges
    Each tap's top resistor is now a single 49.9k 1% 1206 on the board
    (R1, R2, R4-R6), in place of 39k here plus a 10k soldered into the tap
    wire at the gauge end. The tap wires are plain wire from the gauge
    terminals to J1; nothing to solder into the harness.
    The trade-off, at the owner's call: a tap wire is now part of its gauge's
    circuit, so one chafed to ground would read like a shorted sender on that
    gauge (and on IGN would short the key-on 12 V). SENSOR_BOARD.md says so
    and says to route and secure them accordingly.
    BOAT_TAP_R_TOP defaults to 49900 (49000 for a rev 1.0-1.1 board). The
    tap levels are ratios, so the se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
    [sensor-board-bom.csv, sensor-board-pcbway-bom.csv, sensor-board.kicad_pcb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]
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2026-09-24 Gauges: stop forcing a page layout per gauge per frame
    Each gauge asked whether its screen was showing (getClientRects) inside
    its animation step, between one gauge's DOM writes and the next's, so
    every question forced a layout of the whole page: once per gauge, every
    frame. Profiled on the Pi 4 kiosk, that was 52% of the page's CPU, with
    the browser's own layout work behind it most of the rest. The browser
    now reports visibility itself (IntersectionObserver), with no layout.
    The media widget's progress bar also animated its width, relaying the
    page out every frame a song played; it scales with a transform now,
    which the GPU does alone. Its play/pause icon is no longer re-parsed
    every secon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
2026-09-24 Kiosk: network-later.sh -- the dashboard first, the network after
    NetworkManager takes ~16 s to report ready on the Pi (four runs of
    netplan's generator, ~3.5 s each on the Pi 4), and the login screen, the
    kiosk session and the dashboard's server all wait for it through
    network.target, though none needs the network to show the dashboard.
    A service not started during boot isn't waited for, so NetworkManager is
    no longer enabled; boatmfd-network.service starts it after
    graphical.target, and a timer starts it 60 s after boot regardless, so
    WiFi and SSH come back even if the display doesn't. --undo restores it.
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2026-09-24 Pi image: a system of its own for the dashboard, built on GitHub
    image/ builds the boat MFD's own system with Raspberry Pi's rpi-image-gen: minimal Debian 13 in
    its A/B layout (two read-only system copies and a data partition, so the power switch can't damage
    anything), with the dashboard's server, the display (labwc + Chromium on tty1 through a PAM
    session, the same session as kiosk/), SSH by key only, and the sensor board's I2C, SPI, CAN and
    LED-bus overlays. The kernel's boot logo is the kiosk splash on a full-HD frame, so boot logo,
    session background and page show the same "Starting up..." in the same place.
    The Pi 4 test build boots from a USB flash drive: usb-boot.sh adds USB boot mo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
    [main.py]
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2026-09-24 Remove AIS; no mouse pointer or white flash on the Pi's screen; update the Pi over SSH
    AIS is gone: the simulated targets (app/ais.py), their icons on the chart, the AIS Targets menu
    and panel, and the frame's "ais" list. The boat won't track other boats.
    The Pi's screen:
    - No mouse pointer: the image's display session uses a cursor theme whose every cursor is one
    transparent pixel (image/layer/boatmfd.d/no-cursor.py), and the dashboard in kiosk mode sets
    cursor: none.
    - No white flash before the dashboard's first frame: Chromium runs with --force-dark-mode, so its
    empty window is dark, and the page is black from its first paint.
    Updates without re-flashing: the workflow also publish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
    [main.py]
2026-09-24 Sensor board rev 1.3: the LED link is an RJ45; LED board routing progress
    Sensor board:
    - J6 (JST GH) becomes an RJ45 on a new tab above the Pi's GPIO edge,
    facing up, with a PCA9615 (U8) carrying the LED board's I2C bus
    (GPIO5/6) as differential I2C over a straight-through patch cable, and
    each pair terminated 620/120/620 at 5 V. GPIO 18, 19 and 21 are freed:
    the LED board's RP2040 makes the addressable data itself now.
    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
    [sensor-board.kicad_sch]
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2026-09-24 LED board: first KiCad build fixes (still 275 DRC findings; not orderable)
    - board.py: skip paste-only pads (the LFPAK33's twelve unnumbered stencil openings, no copper)
    in the padgeom-vs-pcbnew self-check, which stopped the build.
    - schematic.py: the power flags' zone origin on the schematic grid (ZONE_X 610.0 -> 609.6):
    13 off-grid ERC findings. ERC is now clean.
    - led-board.pretty: the footprints as footprints.py writes them under KiCad.
    The generated KiCad files stay uncommitted until DRC passes.
    [board.py, schematic.py]
2026-09-24 LED board built and checked under KiCad: ERC, DRC and parity clean; fab files for PCBWay
    The LED board's first KiCad build reported 275 DRC findings; all fixed in the generator:
    - Clearance: the Default netclass was written at 0.2 mm while the router spaces at 0.15 (69).
    - Parity: +3V3 and +1V1 named "/+3V3" on the board; every power symbol's net is global (31).
    - Stitching vias: the MOSFETs' three source pins each got a via on the same spot; a pad now
    reuses its own part's nearby via, and new vias keep PCBWay's 0.41 mm hole spacing (54).
    - Fuse holders: each clip is one piece of metal with four legs, and the push-buttons' contacts
    likewise -- "duplicate pad numbers are jumpers"; each f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
    [led-board-bom.csv, led-board-pcbway-bom.csv, led-board-pcbway-centroid.csv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]
2026-09-24 Both boards at 8/8 mil for PCBWay's 2 oz copper
    PCBWay only offers 2 oz copper with 8/8 mil minimum track and spacing.
    LED board: rerouted at 0.2 mm clearance; ERC, DRC and parity clean.
    - Router: no safety margin on straight copper (0.2 mm tracks leave the
    RP2040's 0.4 mm pitch exactly at the limit), a per-curve margin for
    diagonal steps past pad corners, track ends and vias, and no path
    starting from a pad cell too close to its neighbour.
    - A bottom-layer ground spoke from the RP2040's exposed pad, laid before
    its supplies close a ring round it.
    - The PCA9685's right-hand PWM pins get their vias before SDA/SCL run past.
    Sensor board: design rules raised to 0.2 mm; copper unchange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
    [led-board.kicad_pcb, led-board.kicad_sch]
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2026-09-25 Fix the bugs found in review: lights, depth, CAN errors, frozen screens
    - PCA9685: clear SLEEP when starting it up. A chip fresh from power-up
    (MODE1 0x11) was left asleep, with every PWM output dark.
    - Depth: PGN 128267's first byte is a sequence ID, not an instance.
    Filtering on it hid the depth from real transducers. Readings are now
    keyed by source address, with optional BOAT_N2K_DEPTH_SOURCE.
    - CAN: python-can's errors are raised as OSError, so the callers' handlers
    catch them. A failed TelMute unmute is retried, not forgotten. Before,
    a full transmit buffer froze the gauges on stale values.
    - A fast-packet message's frames go out under one lock, so two
    simultaneous stereo c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
    [boat_rgb_node.ino, lighting.py, main.c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]
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
